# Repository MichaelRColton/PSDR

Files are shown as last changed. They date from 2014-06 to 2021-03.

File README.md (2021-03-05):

PSDR
====

PortableSDR - A Stand Alone HF Software Defined Transciever.
[Hackaday.io Link](https://hackaday.io/project/1538-portablesdr)

The PortableSDR is an all-in-one solution for ham operators, hikers, backpackers, and DIY enthusiasts who are looking for an open-source QRP (low-power) radio for communication. It is a fully stand-alone HF/Shortwave Software Defined Radio (SDR) Transceiver and includes a Vector Network Analyzer and Antenna Analyzer as well as GPS, perfect for portable operations in a variety of conditions. It is designed to be a flexible platform for development, a learning aid, and and a useful instrument for electronics enthusiasts.

## Features

- Coverage from 0 to 35MHz
- Waterfall display that lets you see radio signals
- Receives AM, USB (Upper Side Band), LSB (Lower Side Band), and Morse code (CW)
- Modulates USB and LSB signals
- Variable bandpass filter

## Hardware

- Powerful ARM processor
- Color LCD display
- Dual DDS frequency Synthesizers
- Quadrature Sampling Detector & Exciter
- Digitally controllable instrumentation amplifiers
- Morse Code key (the "Giblet" on the bottom right corner of the enclosure)
- Magnitude & Phase measurement chip (for VNA and antenna analysis functions) with Impedance Bridge
- Dual SMA connectors, smartphone style earphone/microphone connector, and USB port
- GPS
- Built in Microphone and Speaker
- Internal Lithium Polymer battery with charger and high efficiency switching regulator
- MicroSD slot
- Pads for grabbing raw I/Q signals, both in and out.

## Why did I make it?
I'm an avid backpacker and radio enthusiast. To me there is something exciting about making contact with others from remote locations where cell phones and the internet can't reach. I wanted an advanced radio that was ideally suited to tough environments. That meant I it needed to be very compact, integrated, and durable. As an engineer, I wanted an open platform that really takes advantage of the hardware and has the potential to grow and be used for other applications.

There are numerous, excellent radios out there, but none offered the combination I wanted. The best radios are closed source, larger, and expensive, while most open designs are very basic and lacking in flexibility.

=======
## Contributing
Please read our [Contributing.md](CONTRIBUTING.md) for ways to help keep this project going.

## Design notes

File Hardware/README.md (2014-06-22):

Schematics and Board layout files are for Mentorgraphics PADS.

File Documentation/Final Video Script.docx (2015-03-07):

Final Video:

Open, Wow, Connected, Reproducable/other uses, Inovation, Interface, Manufacturable

Show off prototype (industrial design), demonstrate connectedness, Sell to non-technical viewers.

5 Minutes.

PortableSDR. What it is, what does it do, why would you want one? (What can it do for you?) What makes it special.

Points I want to hit on. SDR flexibility and upgradability use as a tool and learning aid, backpacking/survival applications. Why HF?

PortableSDR.

What is it? The PortableSDR is a pocket sized, two way shortwave radio. It’s a radio that can keep you connected with the world when you are out in remote places like when you are hiking, backpacking, or fishing, or when traveling abroad.

What sets the PortableSDR apart? It’s a Software Defined Radio. That means most of its functions are handled in software, rather than with dedicated electronics. That it makes the PortableSDR very flexible and upgradable. For example, the national weather service regularly broadcasts weather photos, they could be very helpful for backpackers, but with a normal radio, if it wasn’t designed to receive these photos, it’ll never be able to. The PortableSDR on the other hand, like a computer or smartphone, can load new software that gives it new capabilities. It’s a radio that can evolve and improve with time.

Easy to use: The PortableSDR was designed to be rugged and easy to use. It has a machined aluminum case with a polycarbonate front cover. It’s totally self contained and requires only an antenna to operate. The whole thing is controlled by a single knob. Push and turn the knob to select what you want to change, and release and turn to change it. These keys are for amateur radio operators wanting to do Morse code. It has USB for charging and firmware updates and could also be used for things like keyboards, or remote operation over the internet. It includes what’s called a waterfall display. This allows you to see radio signals. With this you can quickly and easily find signals to listen to.

Why shortwave? Most of the time, when we hear about Megahertz and Gigahertz, more is better. Very high frequency radio waves travel in straight lines. So if you aren’t close to a radio station or cell tower, you can’t hear it. But the band of frequencies up to about 30MHz is special. Signals at these frequencies are able to bounce between the earth and the upper atmosphere. That’s why you can hear broadcasts from China on a shortwave radio, but not on the radio in your car. If you are in a remote area, shortwave signals may be the only thing that will reach you. These are the frequencies the PortableSDR was designed to listen and transmit on so you can connect to people around the world.

Using a shortwave radio at home can be challenging because there is so much noise from things like power lines, and computers. But out away from civilization, things are quieter, so you can hear signals more clearly and from much further away. When I am at home, I can jump on the internet and connect to anyone, anywhere, but there is something magical to me about connecting with people around the world from remote places, where cell phones and the internet can’t reach.

It’s also worth pointing out that in disasters, radios like these are sometimes the only way to communicate.

Emergency Location: The PortableSDR includes a GPS receiver, this combined with the shortwave transmitter means that in an emergency, the PortableSDR may be able to transmit your location to others, even when there is no internet or cellular coverage.

I didn’t design it as an emergency device, if that’s what you need, there are better tools, I made it for fun, for shortwave listeners and amateur radio enthusiasts to take their hobby to remote places, where cell phones and wifi still can’t reach.

Open: The PortableSDR is an open source project. Everything about its design is freely available. Anyone that is interested in making the PortableSDR better can contribute. Its circuitry was designed to be easy to understand and modify so it will be helpful to people learning radio electronics. I’m working on documentation that walks through how each part of the circuit works and why. It also contains several advanced instruments, like an Antenna Analyzer and Vector Network Analyzer, and Spectrum analyzer that make it a useful tool for electronics and radio enthusiasts.

More Info: There is a lot more than I can share in a few minutes. For more detailed information, please visit the link below.

I designed the PortableSDR because I wanted a high performance radio I could take with me on backpacking trips. This is the radio I wanted. I’ve been blown away by the response I’ve received from many people online. Apparently, this is the radio a lot of you want as well. Thank you so much for all your support and encouragement. And thank you for watching.

Licence: No licences is needed to use the PortableSDR for listening in on broadcasts and other signals, but to take full advantage of its capabilities, you’ll need to get an Amatrue Radio licence. They aren’t particularly hard to get, you’ll learn a lot, and may discover a new hobby.

Getting a PSDR: I plan on offering kits for people that are excited to build their own. I’m working on detailed assembly instructions that will help. I also hope to offer assembled units.

I am looking into producing both the case and circuit boards in different colors.

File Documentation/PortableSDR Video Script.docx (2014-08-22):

PortableSDR

The PortableSDR is a self constrained software defined transceiver. With spectrum analysis, and vector network analysis functions. It’s designed to be ergonomic, and very intuitive to use.

I want the PortableSDR to be a great radio, particularly for portable use, a useful, versatile tool, and a potentially life saving device.

I designed it because this is was the radio I wanted to have. I love backpacking, in particular ultralight backpacking. I have two great radios that are made for portable use, the Yaesu FT-817 and the AT Sprint (version2). The 817 is very capable and fun to use, but large, fairly heavy, consumes a lot of electricity. The Sprint is much smaller and lighter, but is extremely limited in its capabilities. Neither take advantage of the amazing flexibility of SDR techniques.

Whenever I’ve seen ham radio operators operating out in the field, they often carry a radio like one of these, an external battery, an antenna tuner, a morse code key, etc. I don’t want that. I really want the only thing other than the radio, to be the antenna.

I also realized that so many RF instruments have many of the same building blocks in common, a transceiver has a lot in common with a spectrum analyzer which has a pretty good deal in common with a vector network analyzer. I want the PortableSDR to take full advantage of the components available.

There have been interesting developments in ultra low power communication. With DSP techniques, it is possible to send and receive extremely weak signals, far too weak to hear, if you don’t mind sending very slowly. This is a perfect fit for backpacking use, where you may want or need to get a message out, but don’t have a lot of power or a great antenna. In particular for emergencies, I think the PortableSDR could send out a call for help when there may be few other options for communication. For this reason (as well as obtaining precies time information) the PSDR will include GPS.

I’ve decided to take the plunge with open source here for the first time. I figured I’d go all in, so every aspect of the design is open, all component lists, schematic, pcb files, gerbers, software, etc. It’s all open.

I’ve made great progress on the design. It’s already highly functional, and I’m delighted that a few people have already built their own. Check it out!

- PortableSDR: The PortableSDR is a Portable Software Defined Tranciever, with Spectrum analyzer, Vector network analyzer and GPS. I am designing it to be ergonomic and easy to use. It has an innovative interface, and is completely open source.
- Background: I made the PortableSDR because I wanted the capability of SDR, but I needed something rugged, self constrained, and in a size and form that I could take backpacking. I wanted something very capable, but also light and easy to use. Most portable Amateur radios are either very limited in capability and usability, or are large and expensive. Often, they require accessories and upgrades to work well and very few run open source software.
- Only about 30Mhz? The PortableSDR covers the HF or shortwave bands. From the AM broadcast band up to about 30Mhz. At these frequencies, radio waves bounce off the earth’s atmosphere, meaning you can hear signals and people from all around the world, and you can talk back. This means the PortableSDR can communicate for huge distances, thousands of miles. Some of the most interesting signals in radio happen here.
- Flexibility: Transceivers, Spectrum analyzers, and Vector Network Analyzers share a lot of common components, so I am designing the PortableSDR to take advantage of this to make it very flexible. The circuit is laid out in blocks that make it easy to learn and modify. It’s not only a great little radio, a learning aid and a useful tool.
- Recent work on very low power digital transmission means that the PortableSDR will be able to send short digital messages thousands of miles from anywhere in the world without any infrastructure. This means it could be used as a lifesaving tool when there is no other way to get a message out. That’s why the GPS is included. There is already a large number of people that monitor these messages, I hope in the future this emergency reporting can be automated.
- This is my first time completely open sourcing my work. Every part of the design is freely available to inspect, learn from, and tinker with. I’m really excited to see what others can do with what I’ve started. A few people have already built up their own PortableSDRs.
- Currently I have the first board, the PSDR1, build and functioning. The interface works with a single knob. Push and turn to select a setting, turn without pushing to change it. The waterfall display makes it easy to see what is happening on nearby frequencies. A variable bandpass filter makes it possible to focus in on what you are trying to listen to. It can currently demodulate AM and Lower Sideband transmissions. There is a lot to do but a lot is working well already.
- The next step is to build the next revision of hardware, and to get it out into the community.

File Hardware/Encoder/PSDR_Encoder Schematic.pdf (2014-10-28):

## 1 ENCA

## 3 COM

## 2 ENCB

## 4 SWA

## 5 SWB

S2

ENCODER_PEC09-2320F-S0015

1
TOUCH3 1
TOUCH4 1
TOUCH5 1
TOUCH6

1 M4

MH125_PLATED

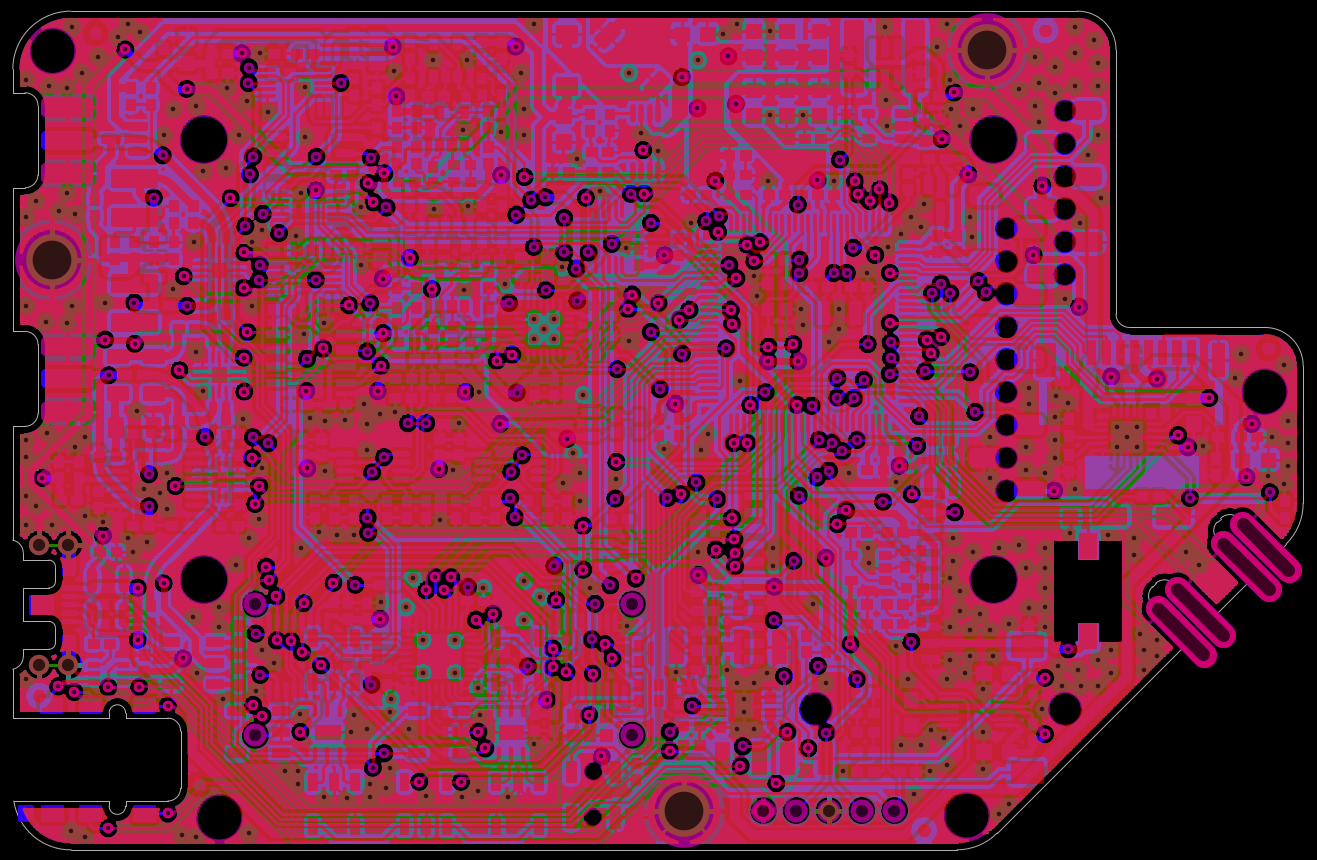
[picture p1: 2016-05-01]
Hardware/Gerbers/PSDR25 Main Board/COPPER.png

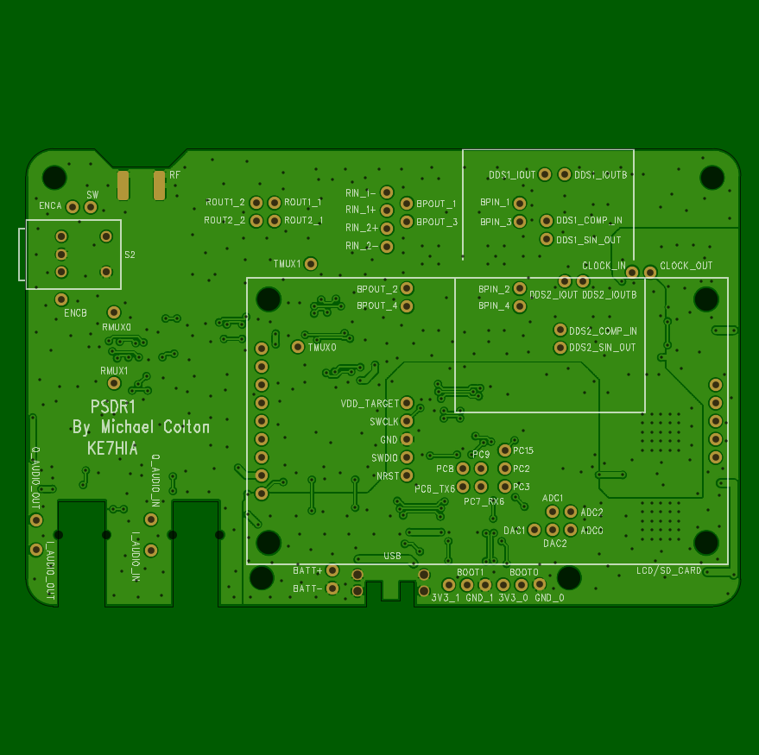
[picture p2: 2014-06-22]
Hardware/Gerbers/PSDR1/bottom_mirror.png

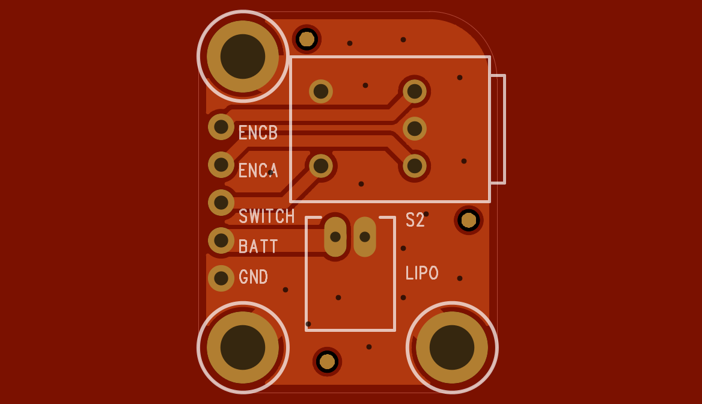
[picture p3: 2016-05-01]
Hardware/Gerbers/PSDR25_Encoder Board/TOP.png

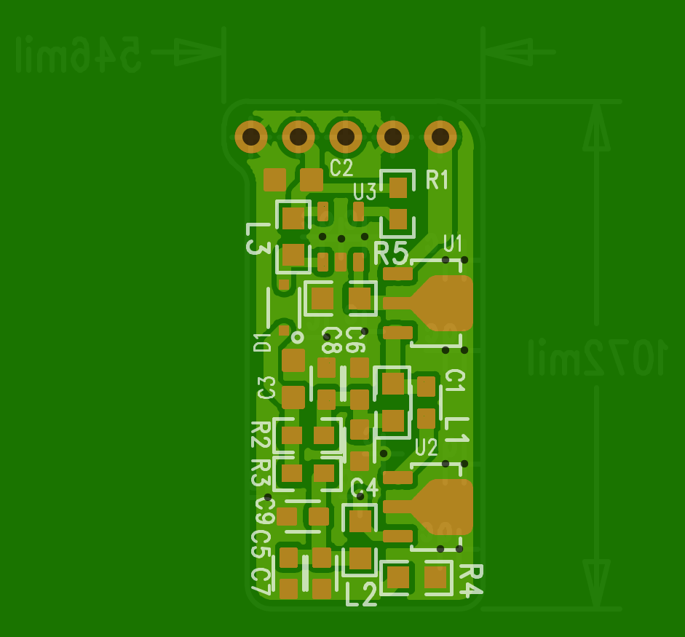
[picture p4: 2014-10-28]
Hardware/Gerbers/PSDR2 Amp Board/BOTTOM-Mirrored.png

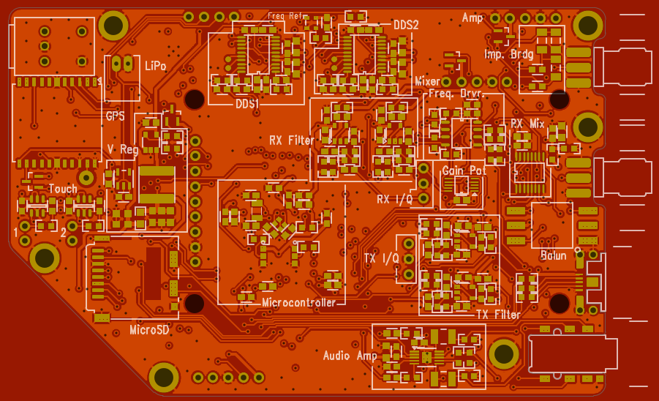
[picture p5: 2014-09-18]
Hardware/Gerbers/PSDR2 Main Board/BOTTOM - Mirrored.png

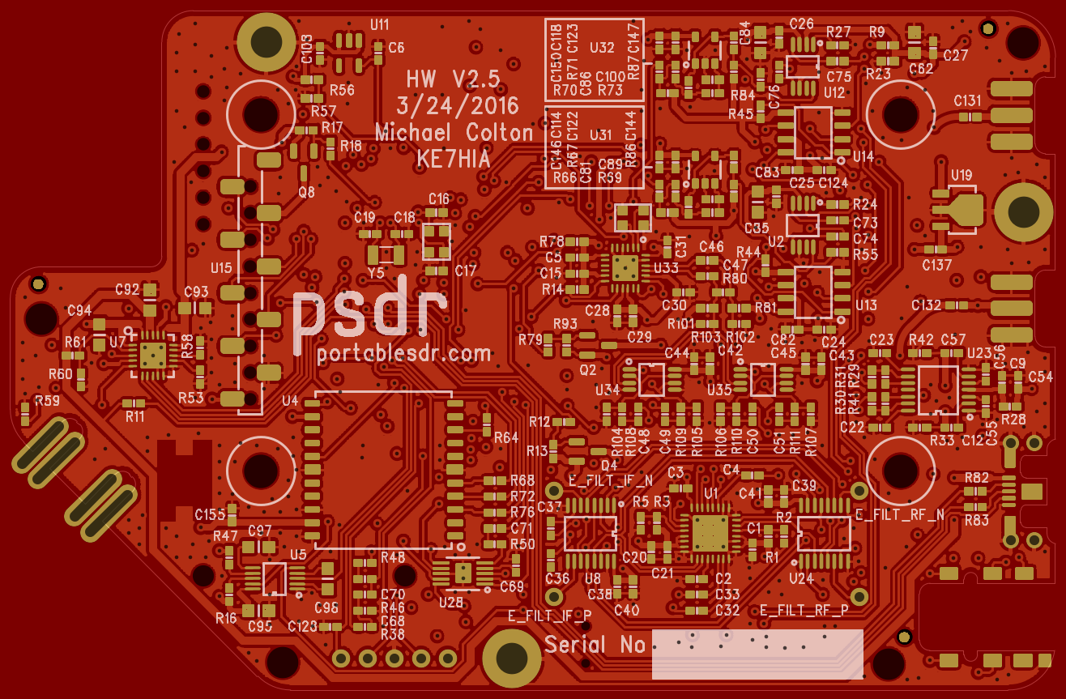
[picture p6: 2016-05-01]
Hardware/Gerbers/PSDR25 Main Board/BOTTOM.png

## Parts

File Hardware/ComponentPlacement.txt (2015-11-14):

PartType                                RefDes                        PartDecal                                Pins      Layer                          Orient.                        X                              Y                             SMD       Glued
0.1"_1PIN                               AMP-IN                        0.1"_1PIN                                1         Top                            90                             330                            2490                          False     False     
0.1"_1PIN                               AMP-OUT                       0.1"_1PIN                                1         Top                            0                              530                            2490                          False     False     
0.1"_1PIN                               AMP-POWER                     0.1"_1PIN                                1         Top                            0                              630                            2490                          False     False     
SMA_BOARD_EDGE                          ANT/VNA-IN                    SMA_BOARD_EDGE                           5         Bottom                         180                            177.165354330709               2165.35433070866              True      True      
CSM-X7R-100N-10P-25V-0603               C1                            C0603                                    2         Bottom                         90                             2100                           2170                          True      False     
CSM-X7R-100N-10P-25V-0603               C2                            C0603                                    2         Bottom                         270                            2100                           2290                          True      False     
CSM-X7R-100N-10P-25V-0603               C3                            C0603                                    2         Bottom                         0                              2230                           2410                          True      False     
CSM-X5R-10U0-10P-25V-0805               C4                            GENERIC_CAP_0805                         2         Bottom                         90                             2040                           2160                          True      False     
CSM-X5R-10U0-10P-25V-0805               C5                            GENERIC_CAP_0805                         2         Bottom                         270                            2040                           2300                          True      False     
CSM-X7R-1U0-10P-10V-0603                C6                            C0603                                    2         Bottom                         180                            3180                           1310                          True      False     
CSM-X7R-1U0-10P-10V-0603                C7                            C0603                                    2         Bottom                         270                            3280                           1430                          True      False     
CSM-X7R-100N-10P-25V-0603               C8                            C0603                                    2         Bottom                         0                              950                            1290                          True      False     
CSM-C0G-100P-5P-50V-0603                C9                            C0603                                    2         Top                            0                              1130                           2410                          True      False     
CSM-X7R-100N-10P-25V-0603               C10                           C0603                                    2         Bottom                         270                            3540                           1250                          True      False     
CSM-X7R-100N-10P-25V-0603               C11                           C0603                                    2         Bottom                         270                            3850                           1250                          True      False     
CSM-X7R-100N-10P-25V-0603               C12                           C0603                                    2         Top                            180                            1330                           2480                          True      False     
CSM-X5R-4U7-10P-10V-0603                C13                           C0603                                    2         Bottom                         180                            3000                           1800                          True      False     
CSM-X5R-10U0-10P-10V-0805               C14                           GENERIC_CAP_0805                         2         Bottom                         270                            2990                           1180                          True      False     
CSM-X7R-10N-10P-50V-0603                C15                           C0603                                    2         Bottom                         270                            1840                           2460                          True      False     
CSM-X5R-1U0-10P-25V-0603                C16                           C0603                                    2         Top                            0                              300                            780                           True      False     
CSM-X5R-1U0-10P-25V-0603                C17                           C0603                                    2         Bottom                         0                              550                            1710                          True      False     
CSM-X7R-10N-10P-50V-0603                C18                           C0603                                    2         Top                            270                            780                            1880                          True      False     
CSM-X7R-10N-10P-50V-0603                C19                           C0603                                    2         Top                            270                            780                            1750                          True      False     
CSM-C0G-18P-5P-50V-0603                 C20                           C0603                                    2         Top                            270                            2570                           1990                          True      False     
CSM-C0G-18P-5P-50V-0603                 C21                           C0603                                    2         Top                            0                              2550                           1900                          True      False     
CSM-X7R-10N-10P-50V-0603                C22                           C0603                                    2         Top                            270                            780                            1520                          True      False     
CSM-X7R-10N-10P-50V-0603                C23                           C0603                                    2         Top                            270                            780                            1390                          True      False     
CSM-X7R-100N-10P-25V-0603               C24                           C0603                                    2         Top                            0                              1020                           1610                          True      False     
CSM-X7R-100N-10P-25V-0603               C25                           C0603                                    2         Top                            0                              1020                           1550                          True      False     
CSM-X7R-100N-10P-25V-0603               C26                           C0603                                    2         Top                            90                             850                            960                           True      False     
CSM-X7R-100N-10P-25V-0603               C27                           C0603                                    2         Top                            90                             850                            720                           True      False     
CSM-X7R-100N-10P-25V-0603               C28                           C0603                                    2         Bottom                         180                            2140                           2080                          True      False     
CSM-X7R-100N-10P-25V-0603               C29                           C0603                                    2         Bottom                         90                             2240                           2050                          True      False     
CSM-X7R-10N-10P-50V-0603                C30                           C0603                                    2         Bottom                         270                            2300                           2050                          True      False     
CSM-C0G-18P-5P-50V-0603                 C31                           C0603                                    2         Bottom                         180                            2400                           2020                          True      False     
CSM-C0G-18P-5P-50V-0603                 C32                           C0603                                    2         Bottom                         0                              2530                           2020                          True      False     
CSM-X5R-1U0-10P-25V-0603                C33                           C0603                                    2         Bottom                         180                            2350                           2410                          True      False     
CSM-X7R-100N-10P-25V-0603               C34                           C0603                                    2         Bottom                         90                             1400                           2170                          True      False     
CSM-X7R-100N-10P-25V-0603               C35                           C0603                                    2         Bottom                         270                            1400                           2290                          True      False     
CSM-X7R-100N-10P-25V-0603               C36                           C0603                                    2         Bottom                         180                            1650                           2410                          True      False     
CSM-X5R-10U0-10P-25V-0805               C37                           GENERIC_CAP_0805                         2         Bottom                         90                             1340                           2160                          True      False     
CSM-X5R-10U0-10P-25V-0805               C38                           GENERIC_CAP_0805                         2         Bottom                         270                            1340                           2300                          True      False     
CSM-X7R-100N-10P-25V-0603               C39                           C0603                                    2         Bottom                         180                            1440                           2080                          True      False     
CSM-X7R-100N-10P-25V-0603               C40                           C0603                                    2         Bottom                         90                             1540                           2050                          True      False     
CSM-X7R-10N-10P-50V-0603                C41                           C0603                                    2         Bottom                         270                            1600                           2050                          True      False     
CSM-C0G-18P-5P-50V-0603                 C42                           C0603                                    2         Bottom                         180                            1700                           2020                          True      False     
CSM-C0G-18P-5P-50V-0603                 C43                           C0603                                    2         Bottom                         0                              1830                           2020                          True      False     
CSM-X5R-1U0-10P-25V-0603                C44                           C0603                                    2         Bottom                         0                              1530                           2410                          True      False     
CSM-C0G-18P-5P-50V-0603                 C45                           C0603                                    2         Top                            270                            2000                           1990                          True      False     
CSM-C0G-18P-5P-50V-0603                 C46                           C0603                                    2         Top                            180                            2020                           1900                          True      False     
CSM-C0G-18P-5P-50V-0603                 C47                           C0603                                    2         Top                            90                             2000                           1810                          True      False     
CSM-C0G-18P-5P-50V-0603                 C48                           C0603                                    2         Top                            180                            2100                           1660                          True      False     
CSM-C0G-18P-5P-50V-0603                 C49                           C0603                                    2         Top                            270                            2060                           1990                          True      False     
CSM-C0G-18P-5P-50V-0603                 C50                           C0603                                    2         Top                            270                            2060                           1810                          True      False     
CSM-C0G-18P-5P-50V-0603                 C51                           C0603                                    2         Top                            0                              2100                           1720                          True      False     
CSM-C0G-18P-5P-50V-0603                 C52                           C0603                                    2         Top                            90                             2570                           1810                          True      False     
CSM-C0G-18P-5P-50V-0603                 C53                           C0603                                    2         Top                            0                              2470                           1660                          True      False     
CSM-C0G-18P-5P-50V-0603                 C54                           C0603                                    2         Top                            270                            2510                           1990                          True      False     
CSM-C0G-18P-5P-50V-0603                 C55                           C0603                                    2         Top                            270                            2510                           1810                          True      False     
CSM-C0G-18P-5P-50V-0603                 C56                           C0603                                    2         Top                            180                            2470                           1720                          True      False     
CSM-C0G-18P-5P-50V-0603                 C57                           C0603                                    2         Top                            270                            1850                           1990                          True      False     
CSM-X7R-10N-10P-50V-0603                C58                           C0603                                    2         Bottom                         180                            880                            1860                          True      False     
CSM-X7R-100N-10P-25V-0603               C59                           C0603                                    2         Bottom                         180                            880                            1920                          True      False     
CSM-X7R-100N-10P-25V-0603               C60                           C0603                                    2         Bottom                         0                              550                            1650                          True      False     
CSM-X7R-100N-10P-25V-0603               C61                           C0603                                    2         Top                            0                              300                            840                           True      False     
CSM-X5R-47U-20P-6V3-0805                C62                           C0805                                    2         Bottom                         90                             290                            1740                          True      False     
CSM-X7R-100N-10P-25V-0603               C63                           C0603                                    2         Bottom                         90                             350                            1730                          True      False     
CSM-X7R-1N-10P-50V-0603                 C64                           C0603                                    2         Top                            0                              990                            2380                          True      False     
CSM-X7R-1N-10P-50V-0603                 C65                           C0603                                    2         Top                            0                              990                            2200                          True      False     
CSM-X7R-1N-10P-50V-0603                 C66                           C0603                                    2         Top                            0                              990                            2260                          True      False     
CSM-X7R-1N-10P-50V-0603                 C67                           C0603                                    2         Top                            0                              990                            2320                          True      False     
CSM-C0G-100P-5P-50V-0603                C68                           C0603                                    2         Top                            180                            1290                           2160                          True      False     
CSM-C0G-18P-5P-50V-0603                 C69                           C0603                                    2         Top                            0                              1830                           1900                          True      False     
CSM-C0G-18P-5P-50V-0603                 C70                           C0603                                    2         Top                            90                             1850                           1810                          True      False     
CSM-C0G-18P-5P-50V-0603                 C71                           C0603                                    2         Top                            0                              1750                           1660                          True      False     
CSM-C0G-18P-5P-50V-0603                 C72                           C0603                                    2         Top                            270                            1790                           1990                          True      False     
CSM-C0G-18P-5P-50V-0603                 C73                           C0603                                    2         Top                            270                            1790                           1810                          True      False     
CSM-C0G-18P-5P-50V-0603                 C74                           C0603                                    2         Top                            180                            1750                           1720                          True      False     
CSM-C0G-18P-5P-50V-0603                 C75                           C0603                                    2         Top                            270                            1280                           1990                          True      False     
CSM-C0G-18P-5P-50V-0603                 C76                           C0603                                    2         Top                            180                            1300                           1900                          True      False     
CSM-C0G-18P-5P-50V-0603                 C77                           C0603                                    2         Top                            90                             1280                           1810                          True      False     
CSM-C0G-18P-5P-50V-0603                 C78                           C0603                                    2         Top                            180                            1380                           1660                          True      False     
CSM-C0G-18P-5P-50V-0603                 C79                           C0603                                    2         Top                            270                            1340                           1990                          True      False     
CSM-C0G-18P-5P-50V-0603                 C80                           C0603                                    2         Top                            270                            1340                           1810                          True      False     
CSM-C0G-18P-5P-50V-0603                 C81                           C0603                                    2         Top                            0                              1380                           1720                          True      False     
CSM-X7R-100N-10P-25V-0603               C82                           C0603                                    2         Top                            0                              1020                           1970                          True      False     
CSM-X7R-100N-10P-25V-0603               C83                           C0603                                    2         Top                            0                              1020                           1910                          True      False     
CSM-X5R-10U0-20P-6V3-0603               C84                           C0603                                    2         Top                            90                             790                            720                           True      False     
CSM-X5R-10U0-20P-6V3-0603               C85                           C0603                                    2         Top                            90                             790                            960                           True      False     
CSM-X5R-10U0-20P-6V3-0603               C86                           C0603                                    2         Top                            0                              640                            880                           True      False     
CSM-X5R-10U0-20P-6V3-0603               C87                           C0603                                    2         Top                            0                              640                            940                           True      False     
CSM-X5R-10U0-20P-6V3-0603               C88                           C0603                                    2         Top                            0                              640                            820                           True      False     
CSM-X5R-10U0-20P-6V3-0603               C89                           C0603                                    2         Top                            0                              640                            1000                          True      False     
CSM-X5R-10U0-10P-10V-0805               C90                           GENERIC_CAP_0805                         2         Bottom                         180                            3190                           1200                          True      False     
CSM-X5R-10U0-10P-10V-0805               C91                           GENERIC_CAP_0805                         2         Bottom                         180                            3190                           1130                          True      False     
CSM-X5R-10U0-10P-25V-0805               C92                           GENERIC_CAP_0805                         2         Top                            180                            2890                           2450                          True      False     
CSM-X5R-4U7-10P-16V-0805                C93                           C0805                                    2         Top                            90                             3010                           2330                          True      False     
CSM-X5R-4U7-10P-16V-0805                C94                           C0805                                    2         Top                            180                            2640                           2350                          True      False     
CSM-X5R-10U0-10P-25V-0805               C95                           GENERIC_CAP_0805                         2         Top                            90                             3180                           450                           True      False     
CSM-X5R-10U0-10P-25V-0805               C96                           GENERIC_CAP_0805                         2         Top                            0                              3150                           330                           True      False     
CSM-X5R-10U0-10P-25V-0805               C97                           GENERIC_CAP_0805                         2         Top                            180                            2960                           400                           True      False     
CSM-X5R-10U0-10P-25V-0805               C98                           GENERIC_CAP_0805                         2         Top                            180                            3090                           640                           True      False     
CSM-X7R-100N-10P-25V-0603               C99                           C0603                                    2         Top                            270                            2990                           600                           True      False     
CSM-X7R-1N-10P-50V-0603                 C100                          C0603                                    2         Top                            180                            1970                           250                           True      False     
CSM-X7R-1N-10P-50V-0603                 C101                          C0603                                    2         Top                            90                             1860                           280                           True      False     
CSM-X7R-10N-10P-50V-0603                C102                          C0603                                    2         Top                            270                            1650                           230                           True      False     
CSM-X7R-1U0-10P-10V-0603                C103                          C0603                                    2         Top                            270                            1590                           230                           True      False     
CSM-X7R-100N-10P-25V-0603               C104                          C0603                                    2         Top                            180                            1750                           340                           True      False     
CSM-X5R-4U7-10P-6V3-0603                C105                          C0603                                    2         Top                            270                            2370                           280                           True      False     
CSM-X7R-100N-10P-25V-0603               C106                          C0603                                    2         Top                            180                            3440                           750                           True      False     
CSM-X5R-22U-20P-10V-1210                C107                          C1210                                    2         Bottom                         0                              1070                           390                           True      False     
CSM-X5R-1U0-10P-25V-0603                C108                          C0603                                    2         Bottom                         90                             1380                           290                           True      False
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

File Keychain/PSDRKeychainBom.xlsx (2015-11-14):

RefDes | Part Type | Description | Count | Value | Digikey Prt#
U3 | 3V3_LDO_MCP1802 |  | 1 |  | MCP1802T-3302I/OTCT-ND
Y1 | ABMM2-8.000MHZ-E2-T |  | 1 |  | 535-9628-1-ND
BUT, RESET | BUTTON_B3U-1000P-B |  | 2 |  | SW1143CT-ND
C8,10 | CSM-C0G-100P-5P-50V-0603 |  | 2 | 47p | 1276-1037-1-ND
C20,21 | CSM-C0G-18P-5P-50V-0603 |  | 2 | 18p | 1276-1089-1-ND
C9 | CSM-X5R-10U0-10P-10V-0805 |  | 1 | 10u0 | 1276-2407-1-ND
C1,2,4,5 | CSM-X5R-1U0-10P-25V-0603 |  | 4 | 1u0 | 1276-1946-1-ND
D3 | LED-WHITE-0603 |  | 1 | APTD1608QWF | 475-2831-1-ND
USB | MICRO-USB_10118194-0001LF |  | 1 |  | 609-4618-1-ND
Q3,4 | NPN_SOT23_CORRECTED |  | 2 |  | 568-4510-1-ND
R2,3,8 | RSM-10K0-1PCT-100MW-0603 |  | 3 | 10K0 | 311-10.0KHRCT-ND
R1,4,5 | RSM-1K00-1PCT-100MW-0603 |  | 3 | 1K00 | 311-1.00KHRCT-ND
R9 | RSM-1K50-1PCT-100MW-0603 |  | 1 | 1K50 | 311-1.50KHRCT-ND
R10,11 | RSM-22R1-1PCT-100MW-0603 |  | 2 | 22R1 | 311-22.1HRCT-ND
R32 | RSM-255R-1PCT-100MW-0603 |  | 1 | 255R | 311-255HRCT-ND
R7 | RSM-36K5-1PCT-100MW-0603 |  | 1 | 36K5 | 311-36.5KHRCT-ND
R6 | RSM-47K5-1PCT-100MW-0603 |  | 1 | 47K5 | 311-47.5KHRCT-ND
U1 | STM32F103CB |  | 1 |  | 497-6288-ND

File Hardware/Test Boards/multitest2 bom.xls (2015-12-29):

Bill Of Materials for Si5338 Test Board_00AF.sch on 11/14/2015
Number | Reference Designator | Qty | Part | Value | DigiPartNo
1 | U9,15 | 2 | 74CBTLV3253 |  | 568-5265-1-ND
2 | C1-9,11,18-23,26-39,42,63,136-139 | 36 | CAP_0603 | 100n | 490-1532-1-ND
3 | C12,13,24,25 | 4 | CAP_0603 | 100p | 1276-1008-1-ND
4 | C40,41 | 2 | CAP_0603 | 1u0 | 1276-1946-1-ND
5 | Y1 | 1 | CRYSTAL3225 |  | SER4069CT-ND
6 | C16,17 | 2 | CSM-X5R-2U2-10P-6V3-0603 | 2u2 | 1276-1134-1-ND
7 | C62 | 1 | CSM-X5R-47U-20P-6V3-0805 | 47u | 1276-2420-1-ND
8 | C14,15 | 2 | CSM-X7R-1N-10P-50V-0603 | 1n | 490-1494-1-ND
9 | U6,8 | 2 | DPDT_ANALOG_MAX4525 |  | MAX4525CUB+-ND
10 | L1,2 | 2 | ISM-0805-10U | MUCH HIGHER? Than 2u2 | 587-2472-1-ND
11 | U4,5 | 2 | MMIC-AMP_HMC482ST |  | 1127-1421-1-ND
12 | Q1,8 | 2 | MOSFET_P_SOT23_IRLML6401 |  | IRLML6401PBFCT-ND
13 | R4,7-9,25,44 | 6 | RES_0603 | 100k | P100KGCT-ND
14 | R1-3,10-22,26-43 | 34 | RES_0603 | 1k0 | MCT0603-1.00K-CFCT-ND
15 | U26 | 1 | RF_DPDT_MASWSS0129TR |  | 1465-1374-1-ND
16 | U10,11 | 2 | RF_MIXER_PE4140 |  | 1046-1021-1-ND
17 | R23,24 | 2 | RES_0603 | 10k | MCT0603-10.0K-CFCT-ND
18 | R5,6 | 2 | RES_0603 | 10r | RHM10.0ADCT-ND
19 | U1 | 1 | SI5338 |  | SI5338A-B-GM
20 | ANT/VNA-IN | 1 | SMA_BOARD_EDGE |  | J629-ND
21 | U2,3 | 2 | SY10EP52V
22 | L9 | 1 | T4-1-KK81
23 | U7 | 1 | VARIABLE_FILTER_HMC1023 |  | 1127-1662-ND
 | Maybe a sample pack of 0603 Resistors
 | Maybe some variable resistors!

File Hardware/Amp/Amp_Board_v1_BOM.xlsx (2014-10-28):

RefDes | Count | Part Type | Distributor Part No. | Distributor | Description | Manufacturer | Value | Tolerance
R1 | 1 | RSM-100K-1PCT-100MW-0603 | P100KGCT-ND |  |  |  | 100K | 0.01
C1 | 1 | CSM-X7R-100N-10P-25V-0603 | 490-1532-1-ND |  |  |  | 100n | 10P
C4, 5 | 2 | CSM-C0G-100P-5P-50V-0603 | 1276-1008-1-ND |  |  |  | 100p | 5P
R2, 3 | 2 | RSM-10R0-1PCT-100MW-0603 | RHM10.0ADCT-ND |  | RES 10 OHM 1/4W 1% 0603 SMD |  | 10R0 | 0.01
C2, 3 | 2 | CSM-X5R-10U0-10P-25V-0805 | 1276-1113-1-ND |  |  |  | 10u0 | 10P
L3 | 1 | ISM-0805-10U | 587-3020-1-ND |  | INDUCTOR 15UH 20% 0805 SMD |  | 15u
C6, 7 | 2 | CSM-X7R-1N-10P-50V-0603 | 490-1494-1-ND |  |  |  | 1n | 10P
R4, 5 | 2 | RSM-10R0-1PCT-125MW-0805 | 541-1.74HHCT-ND |  | RES 1.74 OHM 1/10W 1% 0603 SMD |  | 1R74 | 0.01
C8, 9 | 2 | CSM-X5R-2U2-10P-6V3-0603 | 1276-1134-1-ND |  |  |  | 2u2 | 10P
L1, 2 | 2 | ISM-0805-10U | 587-2043-1-ND |  | INDUCTOR 2.2UH 260MA 20% SMD |  | 2u2
D1 | 1 | DIODE-SOD-323 | SD101CWSTPMSCT-ND |  | DIODE SCHOTTKY 40V SOD323
U1, 2 | 2 | MMIC-AMP_HMC482ST | 1127-1421-1-ND |  | IC MMIC AMP HBT 5GHZ SOT-89
U3 | 1 | LED-BOOST-REG_LM3410 | LM3410XMF/NOPBCT-ND |  | IC DRVR WT/OLED BCKLT SOT23-5

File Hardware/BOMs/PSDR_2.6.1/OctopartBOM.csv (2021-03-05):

Qty | Line Item | Manufacturer | MPN | Octopart URL | Schematic Reference | Internal Part Number | Description | Total Qty (@ Batch Size: 1) | SKU | SKU | SKU | SKU | Packaging | Packaging | Packaging | Packaging | Unit Price (@ Batch Size: 1) | Unit Price (@ Batch Size: 1) | Unit Price (@ Batch Size: 1) | Unit Price (@ Batch Size: 1) | In Stock | In Stock | In Stock | In Stock | MOQ | MOQ | MOQ | MOQ | URL | URL | URL | URL | Distributor [Lowest Price (Overall)] | SKU [Lowest Price (Overall)] | Packaging [Lowest Price (Overall)] | Unit Price (@ Batch Size: 1) [Lowest Price (Overall)] | Line Total [Lowest Price (Overall)] | Batch Total [Lowest Price (Overall)] | In Stock [Lowest Price (Overall)] | MOQ [Lowest Price (Overall)] | URL [Lowest Price (Overall)] | Notes
 |  |  |  |  |  |  |  |  | Digi-Key | Future Electronics | Mouser | RS Components | Digi-Key | Future Electronics | Mouser | RS Components | Digi-Key | Future Electronics | Mouser | RS Components | Digi-Key | Future Electronics | Mouser | RS Components | Digi-Key | Future Electronics | Mouser | RS Components | Digi-Key | Future Electronics | Mouser | RS Components
2 | WM50018-05-ND | Molex | 22-28-4054 | https://octopart.com/22-28-4054-molex-278278 |  |  |  | 2 | WM50018-05-ND |  | 538-22-28-4054 |  | Bulk |  | Bulk |  | 0.45 |  | 0.41 |  | 1714 |  | 288 |  | 1 |  | 1 |  | https://octopart.com/click/track?ai=8237&sig=0768743&sid=459&ppid=278278&vpid=78026448&ct=offers |  | https://octopart.com/click/track?ai=8237&sig=0e5d879&sid=2401&ppid=278278&vpid=37931119&ct=offers |  | Newark | 56H1979 |  | 0.226 | 0.452 | 0.452 | 10524 | 1 | https://octopart.com/click/track?ai=8237&sig=0e22af8&sid=2402&ppid=278278&vpid=534807129&ct=offers
2 | J629-ND | Emerson Network Power | 142-0711-821 | https://octopart.com/142-0711-821-emerson+network+power-39448276 |  |  |  | 2 | J629-ND |  |  |  | Bulk |  |  |  | 4.74 |  |  |  | 34132 |  |  |  | 1 |  |  |  | https://octopart.com/click/track?ai=8237&sig=03f6d87&sid=459&ppid=39448276&vpid=113513258&ct=offers |  |  |  | Voyager Components | 142-0711-821-JOHNSON-N/A |  | 2.43361 | 4.86722 | 4.86722 | 7 | 1 | https://octopart.com/click/track?ai=8237&sig=03d8987&sid=2424&ppid=39448276&vpid=590627797&ct=offers
2 | SW1143CT-ND | Omron | B3U-1000P-B | https://octopart.com/b3u-1000p-b-omron-1057356 |  |  |  | 2 | SW1143CT-ND |  | 653-B3U-1000P-B |  | Cut Tape |  | Tape & Reel |  | 0.92 |  | 0.92 |  | 1995 |  | 6379 |  | 1 |  | 1 |  | https://octopart.com/click/track?ai=8237&sig=0715549&sid=459&ppid=1057356&vpid=36619538&ct=offers |  | https://octopart.com/click/track?ai=8237&sig=02e6279&sid=2401&ppid=1057356&vpid=37858250&ct=offers |  | LCSC | C231330 |  | 0.3769 | 0.7538 | 0.7538 | 3097 | 1 | https://octopart.com/click/track?ai=8237&sig=0cb2428&sid=27971&ppid=1057356&vpid=499990529&ct=offers
68 | 490-3285-1-ND | Murata | GRM188R72A104KA35D | https://octopart.com/grm188r72a104ka35d-murata-196904 |  |  |  | 68 | 490-3285-1-ND | 6104052 | 81-GRM188R72A104KA35 |  | Cut Tape | Cut Tape | Tape & Reel |  | 0.1154 | 0.073 | 0.116 |  | 1934716 | 0 | 313351 |  | 1 | 1 | 1 |  | https://octopart.com/click/track?ai=8237&sig=0552a4b&sid=459&ppid=196904&vpid=1759958&ct=offers | https://octopart.com/click/track?c=1&ai=8237&sig=095ddca&sid=2454&ppid=196904&vpid=495870575&ct=offers | https://octopart.com/click/track?ai=8237&sig=017296d&sid=2401&ppid=196904&vpid=37944309&ct=offers |  | Quest | GRM188R72A104KA35D |  | 0.0699 | 4.7532000000000005 | 4.7532000000000005 | 280406 | 1 | https://octopart.com/click/track?ai=8237&sig=0c9acba&sid=2412&ppid=196904&vpid=67430058&ct=offers
4 | 1276-1008-1-ND | Samsung | CL10C101JB8NNNC | https://octopart.com/cl10c101jb8nnnc-samsung-9299377 |  |  |  | 4 | 1276-1008-1-ND | 4220968 | 187-CL10C101JB8NNNC | 7665130 | Cut Tape | Cut Tape | Tape & Reel |  | 0.1 | 1.63 | 0.1 |  | 239121 | 341798 | 214141 | 176000 | 1 | 1 | 1 | 4000 | https://octopart.com/click/track?ai=8237&sig=0af5203&sid=459&ppid=9299377&vpid=72524765&ct=offers | https://octopart.com/click/track?ai=8237&sig=029d983&sid=2454&ppid=9299377&vpid=495872537&ct=offers | https://octopart.com/click/track?ai=8237&sig=0cd9e3d&sid=2401&ppid=9299377&vpid=659501335&ct=offers | https://octopart.com/click/track?ai=8237&sig=09b4d69&sid=10022&ppid=9299377&vpid=575772157&ct=offers | Newark | 82AC9367 | Cut Tape | 0.005 | 0.02 | 0.02 | 40090 | 1 | https://octopart.com/click/track?ai=8237&sig=0b7e270&sid=2402&ppid=9299377&vpid=511545639&ct=offers
5 | 1276-1009-1-ND | Samsung | CL10B103KB8NNNC | https://octopart.com/cl10b103kb8nnnc-samsung-9299374 |  |  |  | 5 | 1276-1009-1-ND | 7103639 | 187-CL10B103KB8NNNC | 7665373 | Cut Tape | Cut Tape | Tape & Reel |  | 0.1 | 0.098 | 0.1 |  | 1613097 | 6572866 | 438083 | 6204000 | 1 | 1 | 1 | 4000 | https://octopart.com/click/track?ai=8237&sig=08f0957&sid=459&ppid=9299374&vpid=72523832&ct=offers | https://octopart.com/click/track?ai=8237&sig=08b147c&sid=2454&ppid=9299374&vpid=495872440&ct=offers | https://octopart.com/click/track?ai=8237&sig=0edcec1&sid=2401&ppid=9299374&vpid=659501108&ct=offers | https://octopart.com/click/track?ai=8237&sig=09d8818&sid=10022&ppid=9299374&vpid=575772086&ct=offers | Newark | 82AC9315 | Cut Tape | 0.004 | 0.02 | 0.02 | 41660 | 1 | https://octopart.com/click/track?ai=8237&sig=00bc199&sid=2402&ppid=9299374&vpid=511545493&ct=offers
15 | 1276-1113-1-ND | Samsung | CL21B106KQQNNNE | https://octopart.com/cl21b106kqqnnne-samsung-18183217 |  |  |  | 15 | 1276-1113-1-ND | 9526229 | 187-CL21B106KQQNNNE |  | Cut Tape | Cut Tape | Tape & Reel |  | 0.139 | 0.196 | 0.082 |  | 963 | 1988 | 73036 |  | 1 | 1 | 1 |  | https://octopart.com/click/track?ai=8237&sig=0995b10&sid=459&ppid=18183217&vpid=72526172&ct=offers | https://octopart.com/click/track?ai=8237&sig=0265d4b&sid=2454&ppid=18183217&vpid=495872705&ct=offers | https://octopart.com/click/track?ai=8237&sig=01ff177&sid=2401&ppid=18183217&vpid=659501630&ct=offers |  | Mouser | 187-CL21B106KQQNNNE | Tape & Reel | 0.082 | 1.23 | 1.23 | 73036 | 1 | https://octopart.com/click/track?ai=8237&sig=01ff177&sid=2401&ppid=18183217&vpid=659501630&ct=offers
15 | 490-1472-1-ND | Murata | GRM188R72A102KA01D | https://octopart.com/grm188r72a102ka01d-murata-196190 |  |  |  | 15 | 490-1472-1-ND | 7114712 |  |  | Cut Tape | Cut Tape |  |  | 0.077 | 0.108 |  |  | 348772 | 886796 |  |  | 1 | 1 |  |  | https://octopart.com/click/track?ai=8237&sig=057f021&sid=459&ppid=196190&vpid=1764216&ct=offers | https://octopart.com/click/track?ai=8237&sig=00da36d&sid=2454&ppid=196190&vpid=657019381&ct=offers |  |  | Freelance Electronics | GRM188R72A102KA01D |  | 0.00647 | 0.09705 | 0.09705 | 7900 | 1 | https://octopart.com/click/track?ai=8237&sig=048efb7&sid=13062&ppid=196190&vpid=248337884&ct=offers
7 | 1276-1946-1-ND | Samsung | CL10B105KP8NNNC | https://octopart.com/cl10b105kp8nnnc-samsung-19831604 |  |  |  | 7 | 1276-1946-1-ND | 8103641 | 187-CL10B105KP8NNNC |  | Cut Tape | Cut Tape | Tape & Reel |  | 0.1 | 0.0141 | 0.1 |  | 3872897 | 416878 | 227214 |  | 1 | 1 | 1 |  | https://octopart.com/click/track?ai=8237&sig=084b68a&sid=459&ppid=19831604&vpid=72523947&ct=offers | https://octopart.com/click/track?ai=8237&sig=071bacc&sid=2454&ppid=19831604&vpid=495872463&ct=offers | https://octopart.com/click/track?ai=8237&sig=04a8eac&sid=2401&ppid=19831604&vpid=659501159&ct=offers |  | Newark | 82AC9335 | Cut Tape | 0.007 | 0.049 | 0.049 | 8083 | 1 | https://octopart.com/click/track?ai=8237&sig=0dd3b91&sid=2402&ppid=19831604&vpid=511545544&ct=offers
11 | 1276-3375-1-ND | Samsung | CL32A227MQVNNNE | https://octopart.com/cl32a227mqvnnne-samsung-21642163 |  |  |  | 11 | 1276-3375-1-ND | 7061029 | 187-CL32A227MQVNNNE | 7661160 | Cut Tape | Cut Tape | Tape & Reel |  | 1.525 | 2.03 | 1.53 | 1.627 | 4538 | 198141 | 44353 | 18 | 1 | 1 | 1 | 2 | https://octopart.com/click/track?ai=8237&sig=056834c&sid=459&ppid=21642163&vpid=72529399&ct=offers | https://octopart.com/click/track?ai=8237&sig=072bdb2&sid=2454&ppid=21642163&vpid=421050959&ct=offers | https://octopart.com/click/track?ai=8237&sig=02c25d7&sid=2401&ppid=21642163&vpid=659502060&ct=offers | https://octopart.com/click/track?ai=8237&sig=02c5766&sid=10022&ppid=21642163&vpid=575772541&ct=offers | LCSC | C400951 |  | 0.7538 | 8.2918 | 8.2918 | 12811 | 1 | https://octopart.com/click/track?ai=8237&sig=068f5a2&sid=27971&ppid=21642163&vpid=594417399&ct=offers
4 | 1276-1193-1-ND | Samsung | CL10A226MQ8NRNC | https://octopart.com/cl10a226mq8nrnc-samsung-19018972 |  |  |  | 4 | 1276-1193-1-ND | 1951326 | 187-CL10A226MQ8NRNC | 7661006P | Cut Tape | Cut Tape | Tape & Reel |  | 0.24 | 0.235 | 0.32 |  | 112669 | 309837 | 305 | 25 | 1 | 1 | 1 | 25 | https://octopart.com/click/track?ai=8237&sig=065f626&sid=459&ppid=19018972&vpid=72523680&ct=offers | https://octopart.com/click/track?ai=8237&sig=067f4e7&sid=2454&ppid=19018972&vpid=421049762&ct=offers | https://octopart.com/click/track?ai=8237&sig=0491f0a&sid=2401&ppid=19018972&vpid=659501058&ct=offers | https://octopart.com/click/track?ai=8237&sig=0ada1f7&sid=10022&ppid=19018972&vpid=660735010&ct=offers | Quest | CL10A226MQ8NRNC |  | 0.2 | 0.8 | 0.8 | 104 | 1 | https://octopart.com/click/track?ai=8237&sig=077a634&sid=2412&ppid=19018972&vpid=542505621&ct=offers
5 | 1276-1134-1-ND | Samsung | CL10B225KP8NNNC | https://octopart.com/cl10b225kp8nnnc-samsung-19831669 |  |  |  | 5 | 1276-1134-1-ND | 4103667 | 187-CL10B225KP8NNNC |  | Cut Tape | Cut Tape | Tape & Reel |  | 0.11 | 0.0325 | 0.12 |  | 92201 | 354585 | 72645 |  | 1 | 1 | 1 |  | https://octopart.com/click/track?ai=8237&sig=0f63fb3&sid=459&ppid=19831669&vpid=72524202&ct=offers | https://octopart.com/click/track?ai=8237&sig=06c1043&sid=2454&ppid=19831669&vpid=495872483&ct=offers | https://octopart.com/click/track?ai=8237&sig=0c75fe2&sid=2401&ppid=19831669&vpid=659501210&ct=offers |  | Future Electronics | 4103667 | Cut Tape | 0.0325 | 0.1625 | 0.1625 | 354585 | 1 | https://octopart.com/click/track?ai=8237&sig=06c1043&sid=2454&ppid=19831669&vpid=495872483&ct=offers
1 | 1276-2030-1-ND | Samsung | CL10B332JB8NNNC | https://octopart.com/cl10b332jb8nnnc-samsung-15492529 |  |  |  | 1 | 1276-2030-1-ND |  |  |  | Cut Tape |  |  |  | 0.1 |  |  |  | 102646 |  |  |  | 1 |  |  |  | https://octopart.com/click/track?c=1&ai=8237&sig=0ae29b7&sid=459&ppid=15492529&vpid=72524250&ct=offers |  |  |  | Digi-Key | 1276-2030-1-ND | Cut Tape | 0.1 | 0.1 | 0.1 | 102646 | 1 | https://octopart.com/click/track?c=1&ai=8237&sig=0ae29b7&sid=459&ppid=15492529&vpid=72524250&ct=offers
1 | 311-4001-1-ND | Yageo | CC0603JRX7R8BB333 | https://octopart.com/cc0603jrx7r8bb333-yageo-25629527 |  |  |  | 1 | 311-4001-1-ND | 7099787 | 603-CC603JRX7R8BB333 |  | Cut Tape | Tape & Reel | Tape & Reel |  | 0.11 |  | 0.13 |  | 18852 | 0 | 8695 |  | 1 | 4000 | 1 |  | https://octopart.com/click/track?ai=8237&sig=0ca1308&sid=459&ppid=25629527&vpid=457174973&ct=offers | https://octopart.com/click/track?c=1&ai=8237&sig=076279b&sid=2454&ppid=25629527&vpid=657181783&ct=offers | https://octopart.com/click/track?ai=8237&sig=0bc5dc1&sid=2401&ppid=25629527&vpid=268303231&ct=offers |  | Digi-Key | 311-4001-1-ND | Cut Tape | 0.11 | 0.11 | 0.11 | 18852 | 1 | https://octopart.com/click/track?ai=8237&sig=0ca1308&sid=459&ppid=25629527&vpid=457174973&ct=offers
4 | 1276-1062-1-ND | Samsung | CL10B474KO8NNNC | https://octopart.com/cl10b474ko8nnnc-samsung-9301678 |  |  |  | 4 | 1276-1062-1-ND | 2488724 | 187-CL10B474KO8NNNC | 7664765 | Cut Tape | Cut Tape | Tape & Reel |  | 0.1 | 0.098 | 0.1 |  | 216128 | 236311 | 151105 | 116000 | 1 | 1 | 1 | 4000 | https://octopart.com/click/track?ai=8237&sig=01034d2&sid=459&ppid=9301678&vpid=72524451&ct=offers | https://octopart.com/click/track?ai=8237&sig=03b38b2&sid=2454&ppid=9301678&vpid=495872506&ct=offers | https://octopart.com/click/track?ai=8237&sig=0ecb067&sid=2401&ppid=9301678&vpid=658751354&ct=offers | https://octopart.com/click/track?ai=8237&sig=04430c8&sid=10022&ppid=9301678&vpid=575772136&ct=offers | Newark | 82AC9359 | Cut Tape | 0.006 | 0.024 | 0.024 | 12275 | 1 | https://octopart.com/click/track?ai=8237&sig=004f9a0&sid=2402&ppid=9301678&vpid=511545615&ct=offers
1 | 1276-2420-1-ND | Samsung | CL21A476MQCLRNC | https://octopart.com/cl21a476mqclrnc-samsung-24871259 |  |  |  | 1 | 1276-2420-1-ND | 7103714 | 187-CL21A476MQCLRNC |  | Cut Tape | Cut Tape | Tape & Reel |  | 0.83 | 0.14 | 0.53 |  | 409971 | 0 | 71990 |  | 1 | 1 | 1 |  | https://octopart.com/click/track?ai=8237&sig=0b44936&sid=459&ppid=24871259&vpid=72525933&ct=offers | https://octopart.com/click/track?c=1&ai=8237&sig=0c213f7&sid=2454&ppid=24871259&vpid=495872659&ct=offers | https://octopart.com/click/track?ai=8237&sig=0621a86&sid=2401&ppid=24871259&vpid=659501512&ct=offers |  | Future Electronics | 7103714 | Cut Tape | 0.14 | 0.14 | 0.14 | 0 | 1 | https://octopart.com/click/track?c=1&ai=8237&sig=0c213f7&sid=2454&ppid=24871259&vpid=495872659&ct=offers
4 | 490-7203-1-ND | Murata | GRM188R61E475KE11D | https://octopart.com/grm188r61e475ke11d-murata-26982327 |  |  |  | 4 | 490-7203-1-ND | 6104085 | 81-GRM188R61E475KE1D | 8151386 | Cut Tape | Cut Tape | Tape & Reel |  | 0.36 | 0.365 | 0.41 |  | 300910 | 1056 | 213126 | 1350 | 1 | 1 | 1 | 25 | https://octopart.com/click/track?ai=8237&sig=0a6541a&sid=459&ppid=26982327&vpid=68513470&ct=offers | https://octopart.com/click/track?ai=8237&sig=0bae64b&sid=2454&ppid=26982327&vpid=495870555&ct=offers | https://octopart.com/click/track?ai=8237&sig=0cc25c5&sid=2401&ppid=26982327&vpid=168137474&ct=offers | https://octopart.com/click/track?ai=8237&sig=003d1de&sid=10022&ppid=26982327&vpid=575622394&ct=offers | Express Electronics | GRM188R61E475KE11D |  | 0.03 | 0.12 | 0.12 | 11307 | 1 | https://octopart.com/click/track?ai=8237&sig=0b8568b&sid=2450&ppid=26982327&vpid=674983100&ct=offers
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

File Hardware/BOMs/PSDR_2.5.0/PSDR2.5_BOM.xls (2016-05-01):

Bill Of Materials for PSDR.sch on 3/31/2016 |  | Quantity | Total Quantity
 |  | Number of units to build | 2
Item Number | Reference Designator |  |  | Type | Value | Vendor | Vendor Part Number | Manufacturer | Manufacturer Part Number | Replacement Allowed?
1 | ANT/VNA-IN,VNA-OUT | 2 | 4 | SMA_BOARD_EDGE |  |  | J629-ND
2 | BOOT, RST | 2 | 4 | BUTTON_B3U-1000P-B |  | Digikey | SW1143CT-ND
3 | C1-5,8,15,20,21,25-39,42,43,46–54,59,63,82,83,99,104,106,112,116,117,120,125,-144,146,147,150 | 69 | 138 | CAP_0603 | 100n |  | 490-1532-1-ND
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

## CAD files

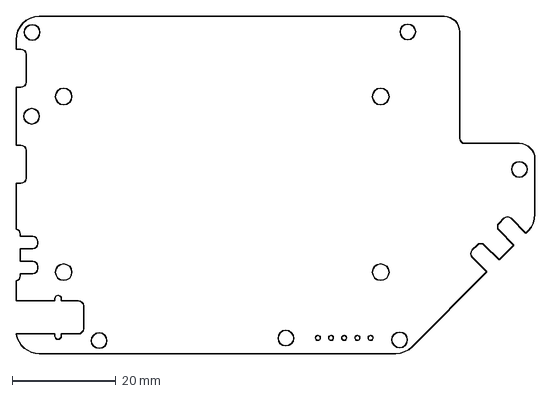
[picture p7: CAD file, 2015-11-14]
Hardware/BOMs/PSDR_2.0.0/PSDR2_MainBoard.DXF
100.0 x 65.0 mm

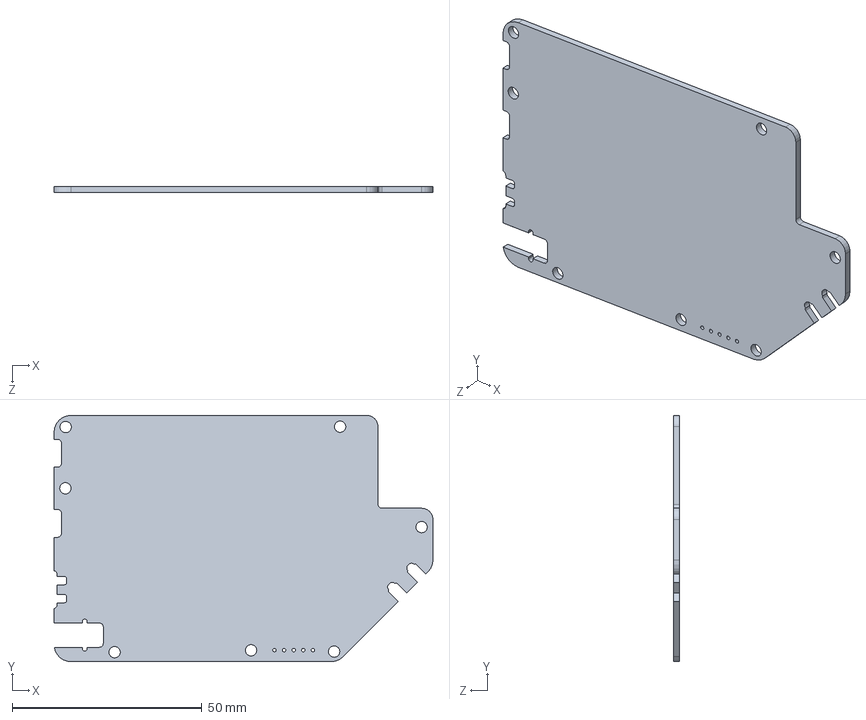
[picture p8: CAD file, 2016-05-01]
Hardware/Enclosure/PSDR2_MainBoard.SLDPRT
100.0 x 65.0 x 1.68 mm

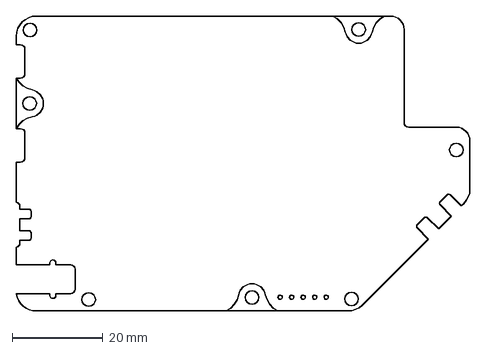
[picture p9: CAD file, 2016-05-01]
Hardware/Enclosure/PSDR2_MainBoard-Backside Housing Keepouts.DXF
100.0 x 65.0 mm

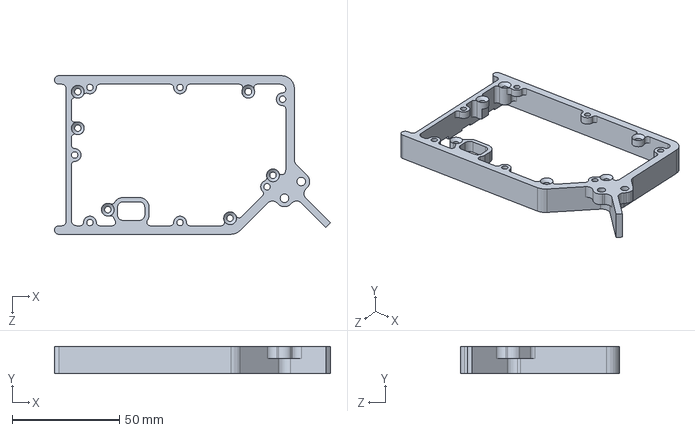
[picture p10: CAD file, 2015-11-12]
Hardware/Enclosure/Main_Enclosure.SLDPRT
128.7 x 12.7 x 74.0 mm

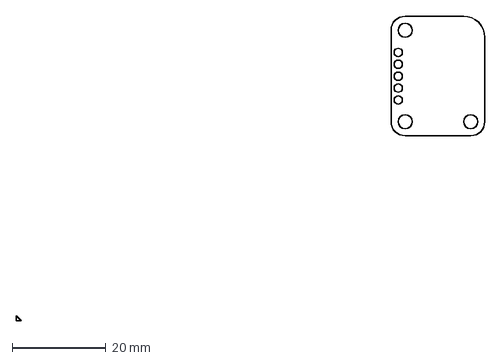
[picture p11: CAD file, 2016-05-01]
Hardware/Enclosure/EncoderBoard-offset.DXF
100.0 x 65.0 mm

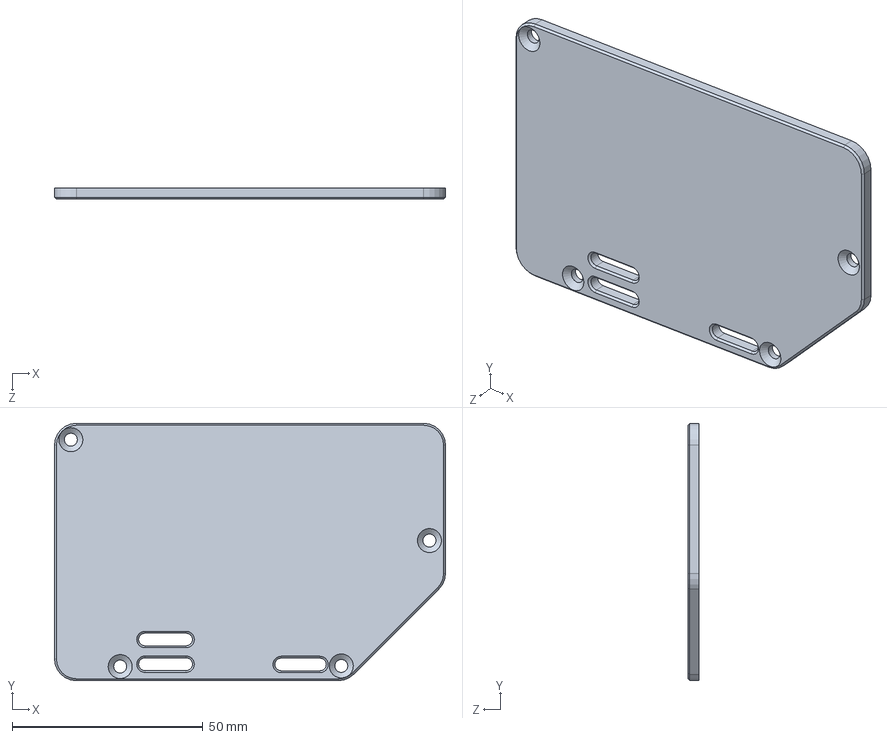
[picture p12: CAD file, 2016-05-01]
Hardware/Enclosure/Face Cover.SLDPRT
102.4 x 67.4 x 3.00 mm

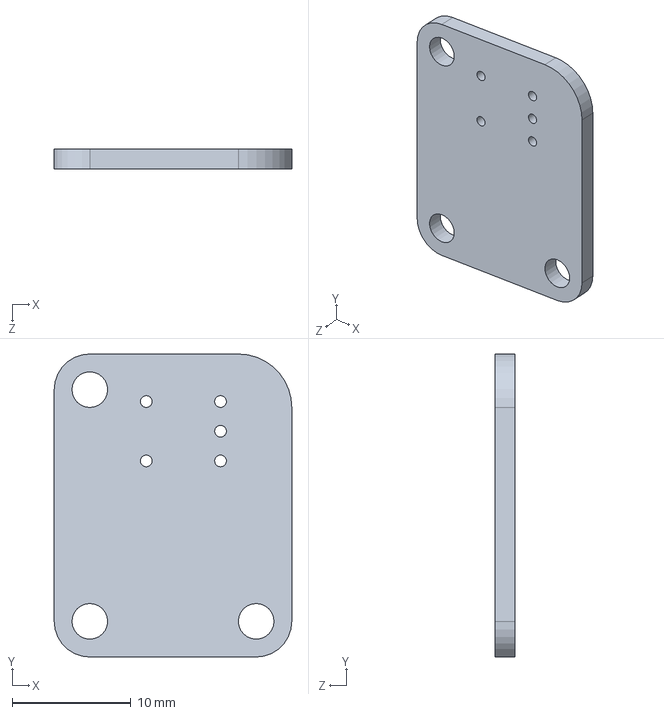
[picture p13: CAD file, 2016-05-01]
Hardware/Enclosure/EncoderBoard.SLDPRT
20.0 x 25.5 x 1.68 mm

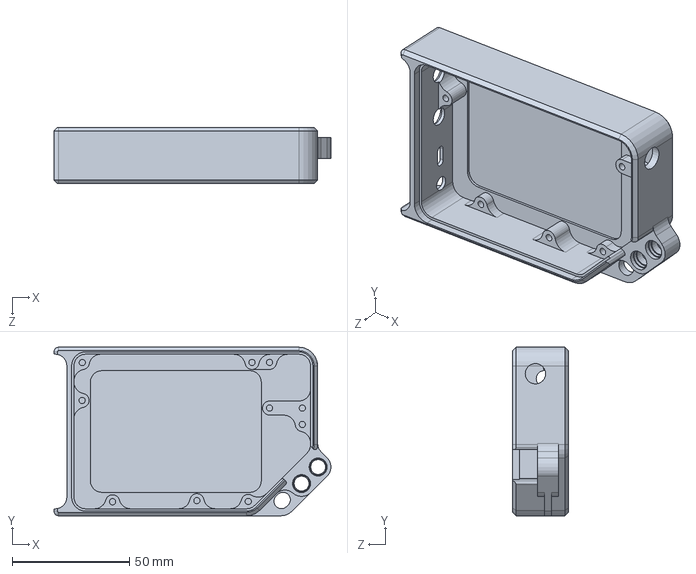
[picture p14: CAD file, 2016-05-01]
Hardware/Enclosure/BottomHalf2.sldprt
118.2 x 72.0 x 24.0 mm

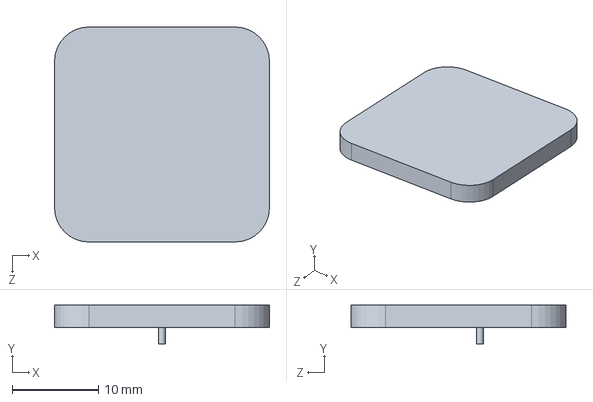
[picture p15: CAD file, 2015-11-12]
Hardware/Enclosure/GPS_Antenna.SLDPRT
25.0 x 4.50 x 25.0 mm

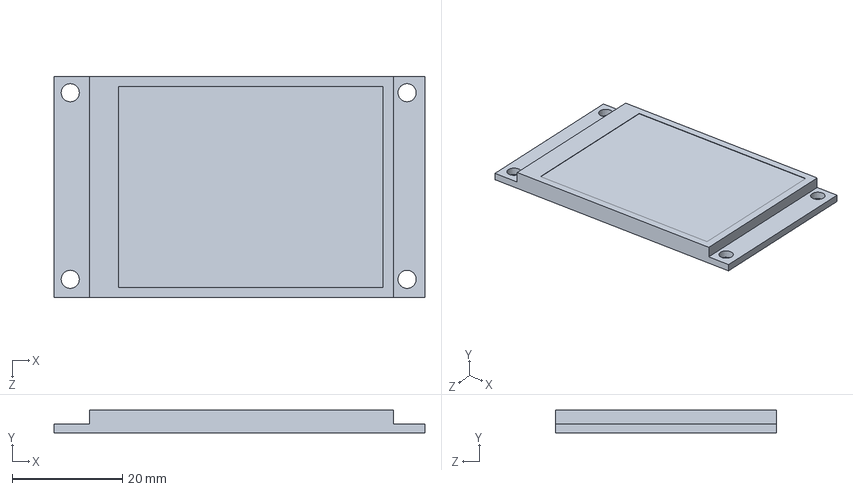
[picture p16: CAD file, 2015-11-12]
Hardware/Enclosure/2.2in_LCD_Module.SLDPRT
67.3 x 4.15 x 40.0 mm

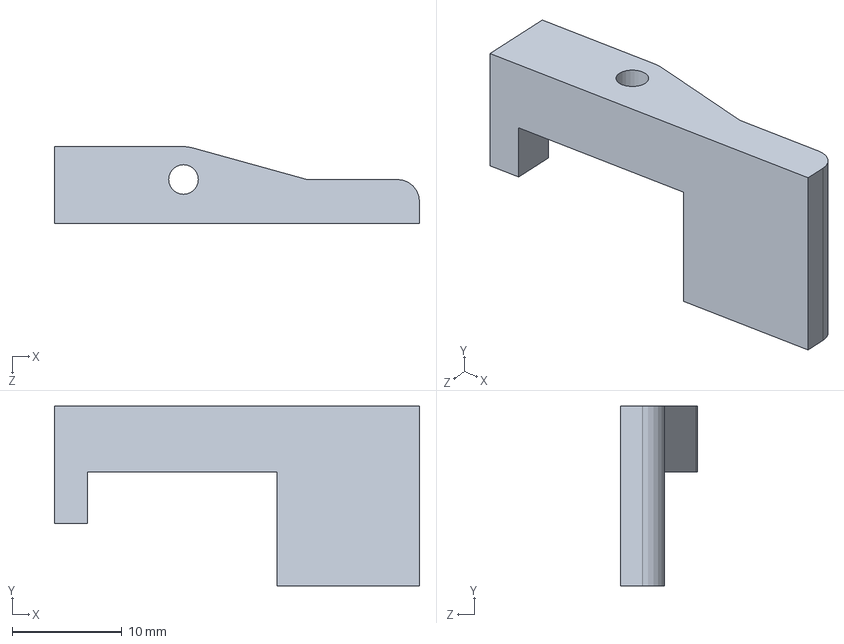
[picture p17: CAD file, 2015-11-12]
Hardware/Enclosure/paddle_Middored.SLDPRT
33.3 x 16.4 x 7.00 mm

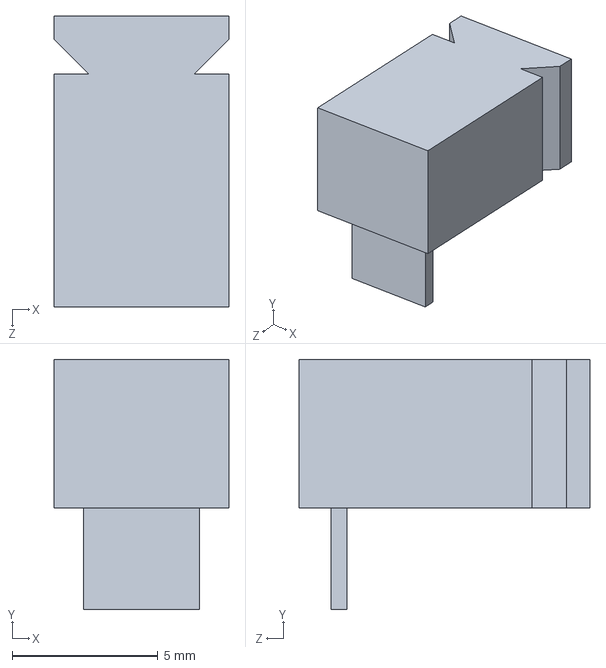
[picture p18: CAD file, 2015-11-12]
Hardware/Enclosure/Battery Connector.SLDPRT
6.00 x 8.60 x 10.0 mm

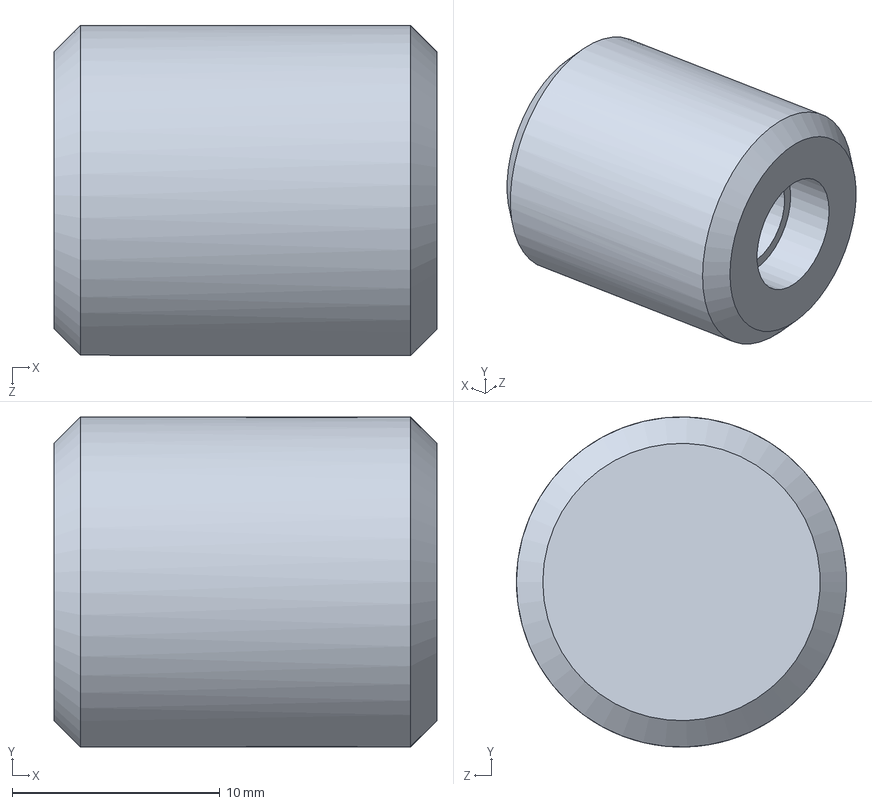
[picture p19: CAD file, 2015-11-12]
Hardware/Enclosure/knob.SLDPRT
18.4 x 15.9 x 15.9 mm

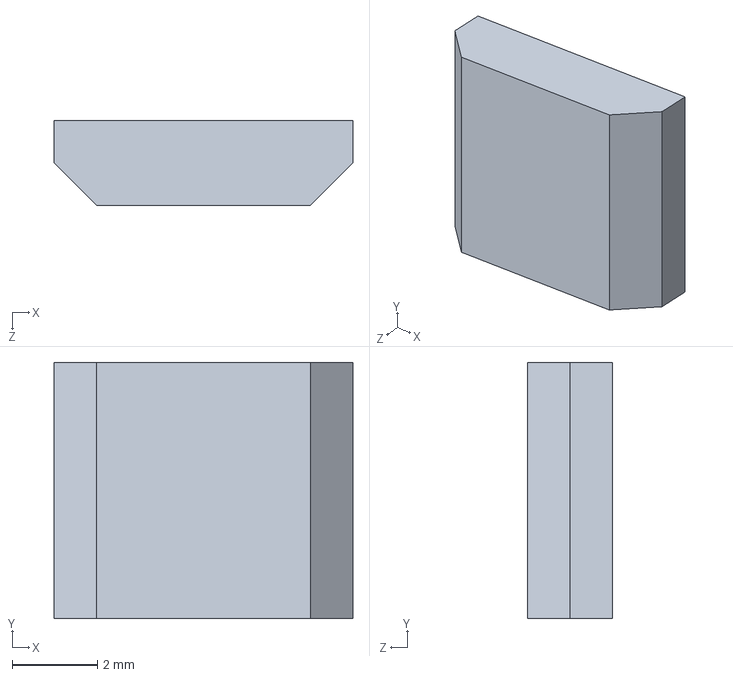
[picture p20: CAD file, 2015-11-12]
Hardware/Enclosure/MicroUSBMale.SLDPRT
7.00 x 6.00 x 2.00 mm

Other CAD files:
Hardware/Enclosure/LeeSpring-LTR028E01S.SLDPRT
Hardware/Enclosure/Bottom_Enclosure.SLDPRT
Hardware/Enclosure/paddle_Mirrored.SLDPRT
Hardware/Enclosure/GPS_Antenna_18x18x4.SLDPRT
Hardware/Enclosure/7x3x3 Bearing.SLDPRT
Hardware/Enclosure/92029A208.SLDPRT
Hardware/Enclosure/92095A183.SLDPRT
Hardware/Enclosure/93395A198.SLDPRT
Hardware/Enclosure/93395A210.SLDPRT
Hardware/Enclosure/93657A708.SLDPRT
Hardware/Enclosure/94500A222.SLDPRT
Hardware/Enclosure/95610A530.SLDPRT
Hardware/Enclosure/BNC_Adapter.SLDPRT
Hardware/Enclosure/Battery.SLDPRT
Hardware/Enclosure/Bottom_Cover.SLDPRT
Hardware/Enclosure/Encoder.SLDPRT
Hardware/Enclosure/EncoderBoard.DXF
Hardware/Enclosure/Knurled_Knob.SLDPRT
Hardware/Enclosure/LCD_Standoff.SLDPRT
Hardware/Enclosure/LeeSpring-LTL015B08S.SLDPRT
Hardware/Enclosure/Other Spring Thing.SLDPRT
Hardware/Enclosure/PSDR2_MainBoard.DXF
Hardware/Enclosure/Slotted_Knob1.SLDPRT
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

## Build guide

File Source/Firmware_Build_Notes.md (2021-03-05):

Firmware Build Notes
====================

* Install gcc-arm-none-eabi: apt-get install gcc-arm-none-eabi, or download from https://launchpad.net/gcc-arm-embedded/4.7
* Download Eclipse Kepler, v4.3 for C/C++ dev from https://eclipse.org/downloads/packages/release/Kepler/SR2
* Help -> Install New software
* add Name: GNU ARM, Location: http://gnuarmeclipse.sourceforge.net/updates
* Click the radio button, and hit next, next, agree to the license, finsh, Hit OK to allow unsigned contents
* Restart eclipse
* Help -> Install New Software
* same as before,add: Name: Zylin Embedded CDT, Location: http://opensource.zylin.com/zylincdt 
* sudo apt-get install openocd
* File -> import -> Existing Projects into Workspace (May be a better way here!)
* Navigate to the PSDR/Source directory and add it.
* hit Build All

You should end up with PSDR/Source/Debug/PSDR.elf  which is the binary firmware file

TODO: Flashing firmware to the PSDR instructions

New Architecture Build Instructions (WIP):

Windows:
1. Install the GNU Tools ARM Embedded. Add bin (not arm-none-eabi/bin) to path?
2. Navigate to firmware directory in shell and execute: make
3. Use whatever editor you want for the files

For eclipse:
1. File->New->Project...
2. C/C++->Makefule Project with Existing Code, "Next"
3. Browse to the root directory of the PSDR firmware
4. I have been selecting "Cross ARM GCC" not sure if that's needed. "Next"
5. Right click on the project in the Project Explorer and select settings. In C/C++ Build, uncheck "Use default build command" and type "make" (or "make VERBOSE=1") without the quotes. Clock "OK"
6. Try to build the project: CTRL-B or Project Menu->Build-All or right click on the project->Build Project
7. TODO: Set up debugging. Fix all the error messages that come up.
For some reason this doesn't work for me unless I build it at least once from the command line. Also, if I do a make clean, I have to build from the command line. More to learn!

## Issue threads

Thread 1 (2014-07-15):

Create Assembly Drawing for PSDR1

MichaelRColton, 2014-07-15:
Some of the silk screens can be a little confusing, so an assembly drawing would be helpful.

MichaelRColton, 2017-01-07:
I probably won't bother with the drawings for the PSDR1 (if the three of you that have one really need one let me know!) but I did make instructions for the PSDR2.6. Find it here: https://github.com/MichaelRColton/PSDR/blob/PSDR_F7/Documentation/Assembly%20Instructions.pdf

Closed 2017-01-07.

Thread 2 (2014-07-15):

Create PSDR1 Assembly Notes

MichaelRColton, 2014-07-15:
This should include the changes to the PCB (VSS/VDD swap on MCU, and Grounds on DDS1-2) and all jumpers. Pictures wouldn't be a bad idea.

MichaelRColton, 2017-01-07:
Again, not going to bother at this point. If someone really needs them, let me know. Some documentation is available in the updates on the hackaday.io page here: https://hackaday.io/project/1538-portablesdr#menu-logs

Closed 2017-01-07.

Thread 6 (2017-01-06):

S meter pinned on USB with filter bottom at 0

pwarren, 2017-01-06:
S meter is pinned to halfway between +20 and +30 Db over 9. Moving the bottom of the filter up to '40' and it moves around with some bearing on the received signal! (PSDR_F7 branch)

MichaelRColton, 2017-01-07:
Are you saying it's always stuck there? On mine it moves around a lot (though the numbers don't correspond to anything yet.)

pwarren, 2017-01-07:
Heh ok, and I just noticed it doing the same thing on AM mode as well!

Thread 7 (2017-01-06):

Project organisation: Licensing, Contributions etc

pwarren, 2017-01-06:
Figured I'd put up an issue for this.

I'd like to get a CONTRIBUTING.md file going, probably based on following https://mozillascience.github.io/working-open-workshop/contributing/

It would be a good idea to set the licensing terms for the code too, and make clear which parts are under which license (eg. GPLv2 or higher not appropriate for the shematics or gerbers, works for the code, but DSP_Lib is BSD(?) licensed, etc)

Code layout and design, I've been very impressed by the code in the mCHF repos: https://github.com/df8oe/mchf-github, which may have some ideas for us!  (In particular, I'm struggling with how to add FM mod/demod, including subaudible tones etc It's not clear to me from the current code, which may say more about me than the code!)

jeffersonbenson, 2021-02-19:
#15 seems to be accomplishing this, pending any necessary changes.

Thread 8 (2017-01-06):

Persistent state storage

pwarren, 2017-01-06:
It'd be nice to have the last used menu settings come back when the radio's turned on, with a way to reset it too I guess.

I'd imagine we'd need a menu state struct, which can be written to FLASH memory at some interval, maybe a second or so after a change?

MichaelRColton, 2017-01-07:
Agreed. Depending on what power state we drop down into, we may be able to preserve those things in memory without too much of a hit to standby current.

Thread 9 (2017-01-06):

Proper Off menu item and 'Turn On' gesture

pwarren, 2017-01-06:
While my current implementation of an off button 'works' it doesn't seem to preserve the battery much more than a day or so.

Also, I need to figure out how to get the unit into a state that can monitor the buttons for the turn on gesture, I don't think my EnterSTANDBYMode() can do that, it appears to only be able to look for rising edges on the PA0 pin or interrupts.

MichaelRColton, 2017-01-07:
I haven't had time to look at or play with your new code yet, but I think I remember you mentioning turning off peripherals. Were you talking about those internal to the MCU, or the various external devices attached to the MCU?

I didn't design the PSDR with an eye for excellent standby efficiency (not that I don't want to, it just wasn't high on the list and I had other things to worry about) but I did include the ability to kill power to many of the sub systems on the board (via MCU controlled FETs), and some of the chips can be turned off by setting them to lower power states via whatever bus they are connected to.

I was pretty sure that the pins I used for the encoder switch, and maybe (hopefully!) the paddles supported pin change interrupts that should be able to wake the MCU, but I am not positive. Also potentially helpful would be slowing the clock way down, and setting up a routine that, for example, wakes the MCU on the first pin change event, then quietly watches for the other events in the gesture (whatever form that ends up taking) before bringing itself (and the other subsystems) up the rest of the way. If it doesn't see those other events within a certain time window, then it assumes that first event was unintentional and goes back to sleep.

I think the boards draw around 8mA (is that right?) before they are programmed, so that might be as low as we end up getting, but that should give 10ish days, which I think would be reasonable at this stage of development.

pwarren, 2017-01-07:
All I've done so far is do the opposite of the setupPeripheralPower() function, i.e: __GPIO_CLK_DISABLE() etc etc. then call HAL_PWR_EnterSTANDBYMode(). Not sure how much it helps, but It does recover when the reset button is pushed for at least a few hours after turning it off.

I should have a bit of time this week to look a things in a bit more depth for power management, after I get myself together for my https://linux.conf.au/ miniconf presentation. I'll definitely be showing off the PSDR while I'm there :)

MichaelRColton, 2017-01-15:
I made a mistake in my measurement before (I was using a different meter and misread it) so it draws ~80mA before it's programmed, and that's about what your turn-off code gets us down to.

Some thermal imaging shows that our biggest power consumption is the frequency synth chip (U241: SI5338). Pretty sure that can be powered down in code.

The LCD control circuitry is wasting some power (not sure if there is a command to power that down), not including the backlight.

Also bad are the phase/mag chip (U314: AD8302), And the AD8131s (U260 and U253) and there isn't anything that can be done by the MCU to power them off.

Looks like I have some changes to make in the next rev.

We'll want to issue a command to put the SI5338 (and LCD if possible) into a lower power state, and then I don't think we'll get a whole lot lower than that.

And, of course, getting the wake-up gesture going. (P.S. Sometimes hitting reset didn't see to want to wake it, not sure why...)

Top side with LCD
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
Top without LCD (that bright spot in the middle is the heat from the back of the SI5338)
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
Bottom
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

sanamon, 2017-01-18:
I know it's not so high-tech, but perhaps an old-school switch between battery and radio would solve the problem?  :-)

jeffersonbenson, 2021-02-01:
Gonna see if I can revive this thread :grin:
Is the goal here to work something like (https://github.com/chacal/stm32sleep) where there is a low-power SLEEP state and then a WAKE gesture?
Based on the circuitry, there isn't really a great way to completely disconnect the device from the battery. At this point it looks like the best we can do is get it to a low enough power state for short to medium-term storage, and then advise users to bring a spare battery pack?

jeffersonbenson, 2021-02-04:
To follow up on my above comment, couldn't you also just add a slide switch inline with the battery and have it poke out the "front" of the case, over by the rotary encoder? See below crude mockup:
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

sanamon, 2021-02-04:
Hi,

I’m sure it’s the easiest route at least.

But i’d start by looking into the preamp issue (preamp not enabled, perhaps by not bing initialized in software) as this thing is deaf as a brick right now (sensitivity around -70dBm if I remember correctly, indicating 50 dB “missing”)

Regards
Jonas

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

jeffersonbenson, 2021-02-04:
@sanamon I see what you're saying with regards to the preamp issue. Perhaps something that can be brought up in a separate issue for further discussion?
For the issue at hand finding a compatible switch is the quickest way to power the whole device off.

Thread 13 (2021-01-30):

Obsolete parts in 2.6.1 BOM

jeffersonbenson, 2021-01-30:
While compiling a BOM for an upcoming 2.6.1 build, I discovered that the following parts are obsolete according to Digikey and do not have replacements available. Further investigation will be required in order to find suitable replacement parts.

Parts not found:
599-1068-1-ND  - RF amplifier U304
1465-1374-1-ND - RF DPDT Switch U16, U24, U30

jeffersonbenson, 2021-02-19:
Found the following outside of DigiKey, which is annoying but nevertheless it can be found

599-1068-1-ND - RF amplifier U304
SXB-2089Z
https://www.win-source.net/rf-amplifiers-sxb-2089z.html

1465-1374-1-ND - RF DPDT Switch U16, U24, U30
MASWSS0129TR-3000
https://www.richardsonrfpd.com/Products/Product/MASWSS0129

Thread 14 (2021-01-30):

Missing parts in 2.6.1. BOM

jeffersonbenson, 2021-01-30:
The following parts are marked as either NA or DNS in the BOM. Have they just been removed and the BOM needs to be updated?

CAP_0603 - C307, C320
RES_0603 - R72, R79

jeffersonbenson, 2021-02-19:
So after learning a few things about reading BOMs, the NA seems to mean "just leave it open" and DNS means "do not stuff".

My only concern would be that there needs to be something to bridge the connections here like a 0ohm resistor or something. I'll need to investigate the traces.

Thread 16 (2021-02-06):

Enable Pre-Amp in Firmware

jeffersonbenson, 2021-02-06:
But i’d start by looking into the preamp issue (preamp not enabled, perhaps by not bing initialized in software) as this thing is deaf as a brick right now (sensitivity around -70dBm if I remember correctly, indicating 50 dB “missing”)

DM2NT, 2021-12-06:
I think Michael hasn't worked on this project for a long time. I also have a PSDR here. But like all the others, it's just a paperweight.

MichaelRColton, 2021-12-06:
It's true, I've become busy with other projects and the PSDR hasn't gotten
much of my time recently. Jeff is correct, the preamp/low-pass filter
circuit isn't working. I had it working on development hardware, but my
efforts to get it to operate properly on the production board didn't reach
completion. That would certainly be a great place to focus attention for
anyone that is interested in assisting with development.

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

DM2NT, 2021-12-06:
Is it very complicated to activate the preamp? Unfortunately I don't have a Windows computer to run the development environment.

MichaelRColton, 2021-12-07:
Well in theory it shouldn't be too hard. Though it's certainly not as easy
as turning on power to it. There are RF switches that need to be
configured, and the pre-amp/low-pass filter IC has a lot of configuration
registers and things that have to be set correctly. The frustrating part is
that I had built one up on a dev board I made, ran some test code on it and
verified it was doing what I wanted (in this case, I was more focused on
the low-pass filtering part, but it did demonstrate the chip was working.)
but when I tried to do it on the production PSDR, I had trouble getting it
to work. I'm not sure what the problem is. And right now I just don't have
the bandwidth to work on it.

Most of my code is not in the main branch on github, btw, make sure you
look at them to see where the most recent activity is.

It might be worth putting on external pre-amp on the PSDR to see if it
performs better with that there. Where I live the bands are so noisy (S9+
most of the time) that the PSDRs sensitivity is actually fine, any signal
that can get through that shows up on the PSDR. I didn't realize at the
time that the sensitivity was a problem.

I am, by no means, an expert in RF/Radio design. If anyone makes
modifications that improve performance, I would love to know about them.

There is another project, called uSDR (there are some variations on it)
that pulls off pretty good performance with simpler circuitry than the
PSDR, and includes a very efficient amplifier design, something the PSDR
almost completely lacks. When I have some time, I'm interested in taking
what is (in my opinion) superior on the PSDR (the screen, processing power,
waterfall, ergonomics, case design, etc.) and merging in what I can from
the uSDR (simpler design, better sensitivity, better output power and
output filtering) into a next generation PSDR that could actually meet the
design goals I had for the original. But that may be a ways down the
line....

-Michael

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

DM2NT, 2021-12-09:
Hi Michael,

I also know the uSDX. Unfortunately, it doesn't offer a good display interface. I don't want to do without the waterfall display. Andreas DF8OE has already implemented the HMC1023 in his UHSDR. Here is the link to the Github: https://github.com/df8oe/UHSDR/tree/active-devel/mchf-eclipse/hardware

Maybe you can already use a part here.
However, I still don't have a Windows computer ...

petermccracken, 2021-12-09:
... I think a Malahit is what you want, either the original or there is one of the china clones which is as good as the original. There's a very active group of FB. Also google teensy convolution sdr if you really want to get into it.

petermccracken, 2021-12-09:
Also have a look at the mcHF group on FB, if you look through the posts there's a Russian guy who is selling modified kits for the mcHF with a 4" display, looks very good. There are heaps of possibilities and projects out there.

MichaelRColton, 2021-12-09:
DM2NT, Yes, I agree the uSDX interface is lacking (and in my opinion, the
ergonomics, case design, and the microcontroller is very underpowered,
thought they've managed to do an impressive amount with it) the idea I'm
playing with is merging the PSDR and the uSDX, but it will be a while, or
may never happen at all. Also, you don't need a Windows computer to work on
the PSDR, I just don't have instructions for other environments. Any guide
on doing STM32 development for your platform will likely work.

Peter, the Malahit looks pretty cool, but looks like it has rather
different goals from what I hope the PSDR eventually becomes. I am aware of
the mcHF, it's a nice project for sure. Interestingly, KA7OEI, the guy that
overhauled the mcHF, hugely improved its software (and maybe hardware too?)
lives not far from me and I've talked to him about the PSDR. He said he's
willing to take a look at it, but we haven't really made it happen yet.

-Michael

On Thu, Dec 9, 2021 at 9:21 AM petermccracken ***@***.***>
wrote:

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

sanamon, 2022-07-04:
> Unfortunately I don't have a Windows computer to run the development environment.

You dont need windows to do this. If You have a Linux machine, see https://github.com/MichaelRColton/PSDR/wiki/Linux-build-instructions

Cheers,
Jonas

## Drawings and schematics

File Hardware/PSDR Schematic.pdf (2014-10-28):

# TODO:

# Rename pins and stuff

## Look into variable band pass filters (switched cap?)

## consider a mixer to enable 2m (or other) freq operation

# Add light sensor for backlight, you know?

# Change frequency antialiasing filters

# Change over to new LCD

# Add temperature sensor near freq reference add second freq ref?

# add comparitor to freq ref output? (or use one with square output)

Consider switching to that frequency generator part that everyone else uses with 4x divider?

# Add ability to turn off subsystems (like RF)

# Add some kind of RF out amplifier?

# Look into magnetic encoder

# antenna tuner?

# DONE:

# Clean up schematic (to resemble block diagram)

# Later?:

## parallel display conflicts with DAC on most parts (unless you go to 144pins or more)

# so should I add a dac/codec or bag the parallel display for now?

bag it for now.

# multitap inductor?

# NOTES: Analog dies at about 2.3v Digital also dies at about 2.4v, but the display becomes very dark at 2.7~

Looks like life is pretty good at 2.9v.

# Add test points to relevent locations

# Add fiducials. Oops!

Try bottom entry LCD connector turn encoder on its side smaller GPS antenna Power cuttoff circuit fix charge voltage divider thing see if you can bring half-vcc to one of the microcontroller ADCs do I like using half-vcc, or just putting voltage dividers all over the place? The mic preamp ouputs a bias voltage, okay for external mic, how about for the mems mic? I really need to characterize the antialiasing filters - DONE: 3db cuttof is 15-16kHz! adjust charge circuit resistors to make sense (current limit, charge rate, etc.) Consider changing freq synth topology, maybe PLL with div2 I/Q splitter? detect charger type (usb type) and adjust charge current appropriately? A few parts are too close together Should I consider 0402s? IN_AMP_ENABLE Doesn't make it to the MCU!!!! GAH! Doesn't there need to be a half-vcc bias on the mic filter out?

Did I forget to route the external mic out to the microcontroller? (to detect button presses?) :/

# Is the mems mic okay with a bias from the preamp? Maybe not. Put cap inline? No bias on external mic. Really? :/ Look into AD9958? We probably want the AMP power line to come from the battery, not from 3v3

# GPS Interface

## Vbat is for backup battery, but since the 3v3 reg is always on

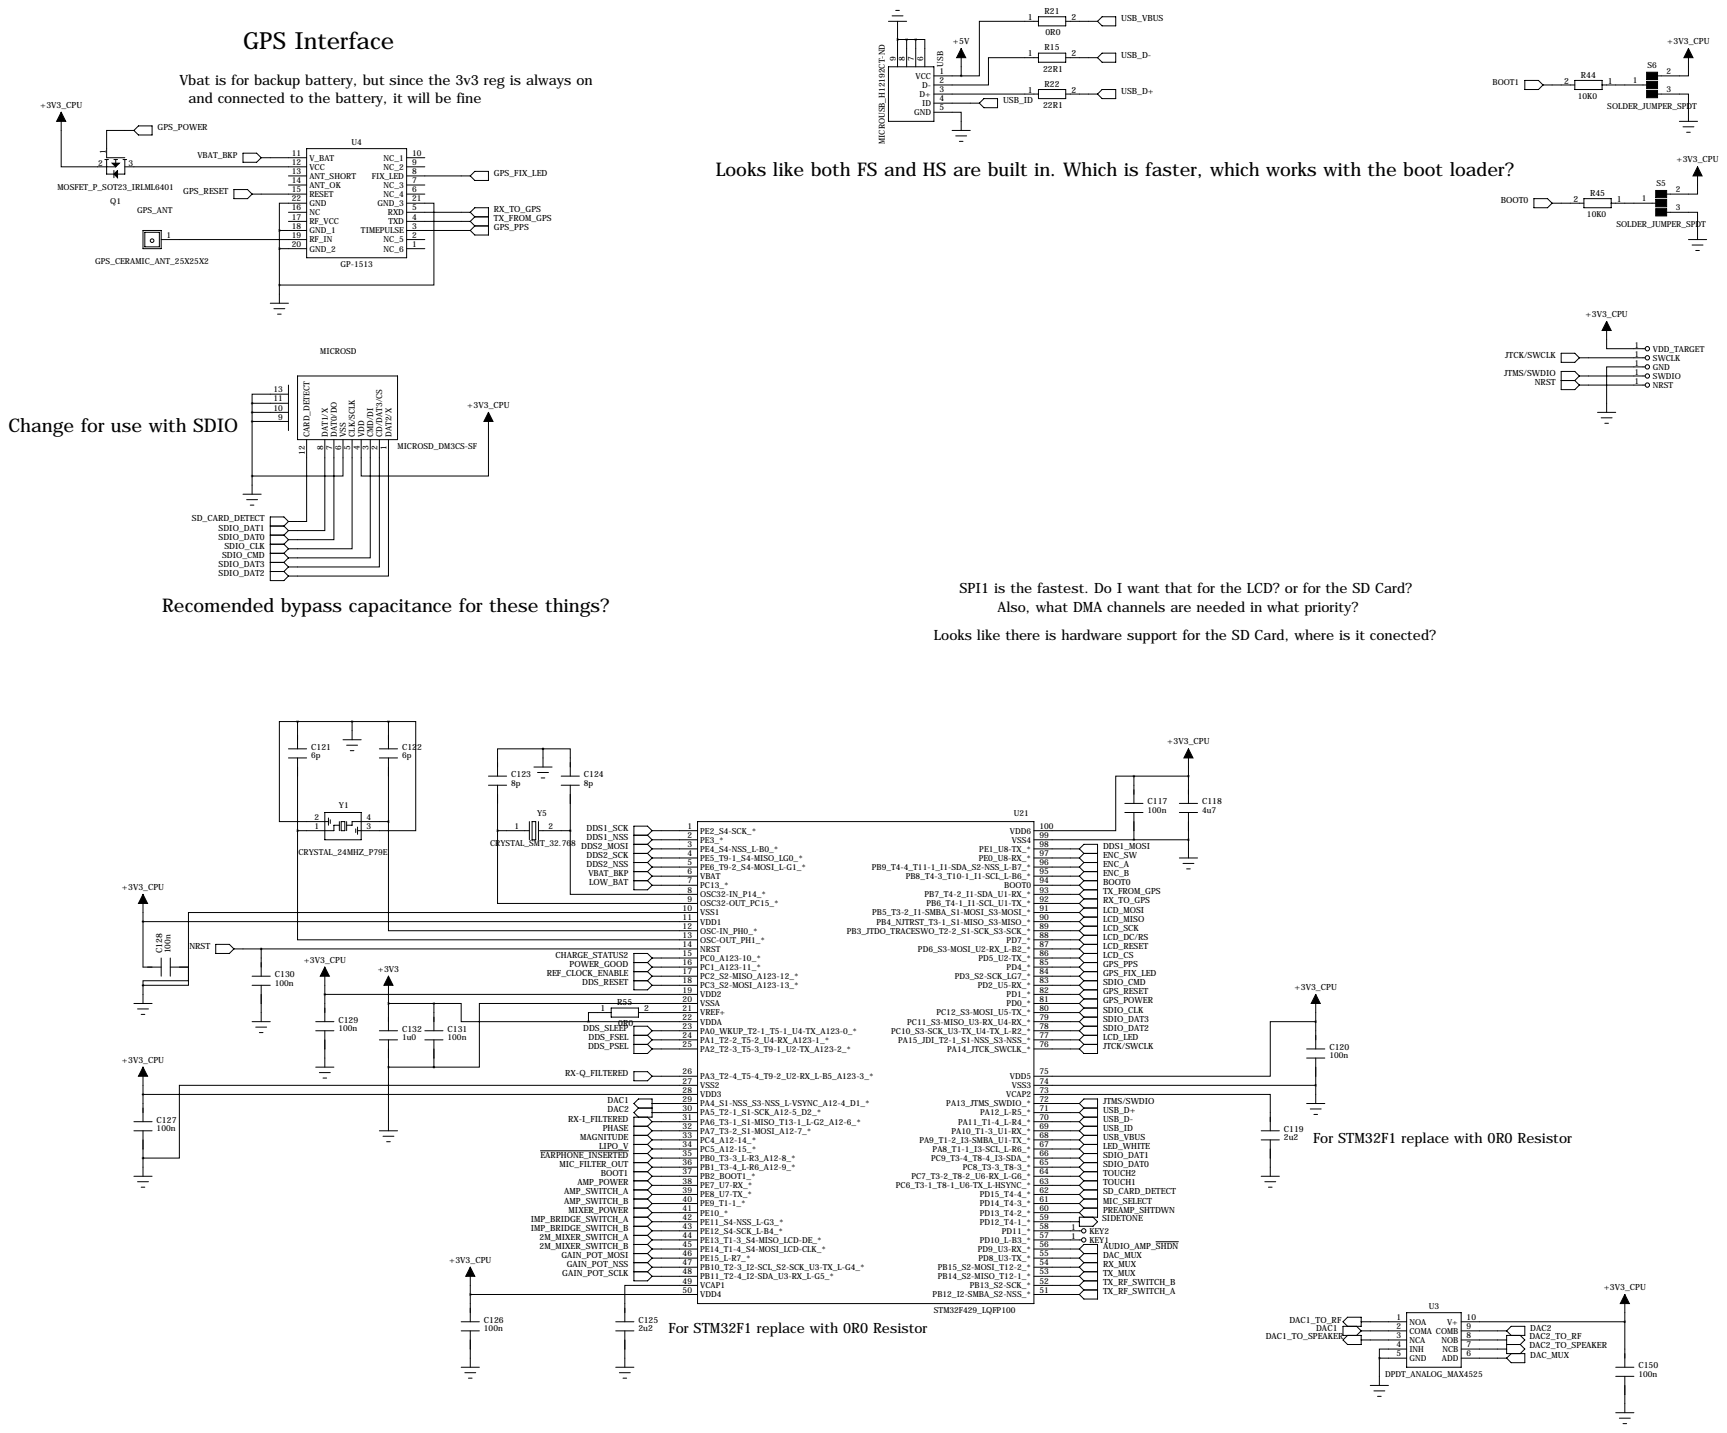
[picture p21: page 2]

and connected to the battery, it will be fine

Looks like both FS and HS are built in. Which is faster, which works with the boot loader?

Change for use with SDIO

SPI1 is the fastest. Do I want that for the LCD? or for the SD Card?

Recomended bypass capacitance for these things?

Also, what DMA channels are needed in what priority?

Looks like there is hardware support for the SD Card, where is it conected?

For STM32F1 replace with 0R0 Resistor

# 75 Mhz Clock Circuit

# 70 Mhz LPF

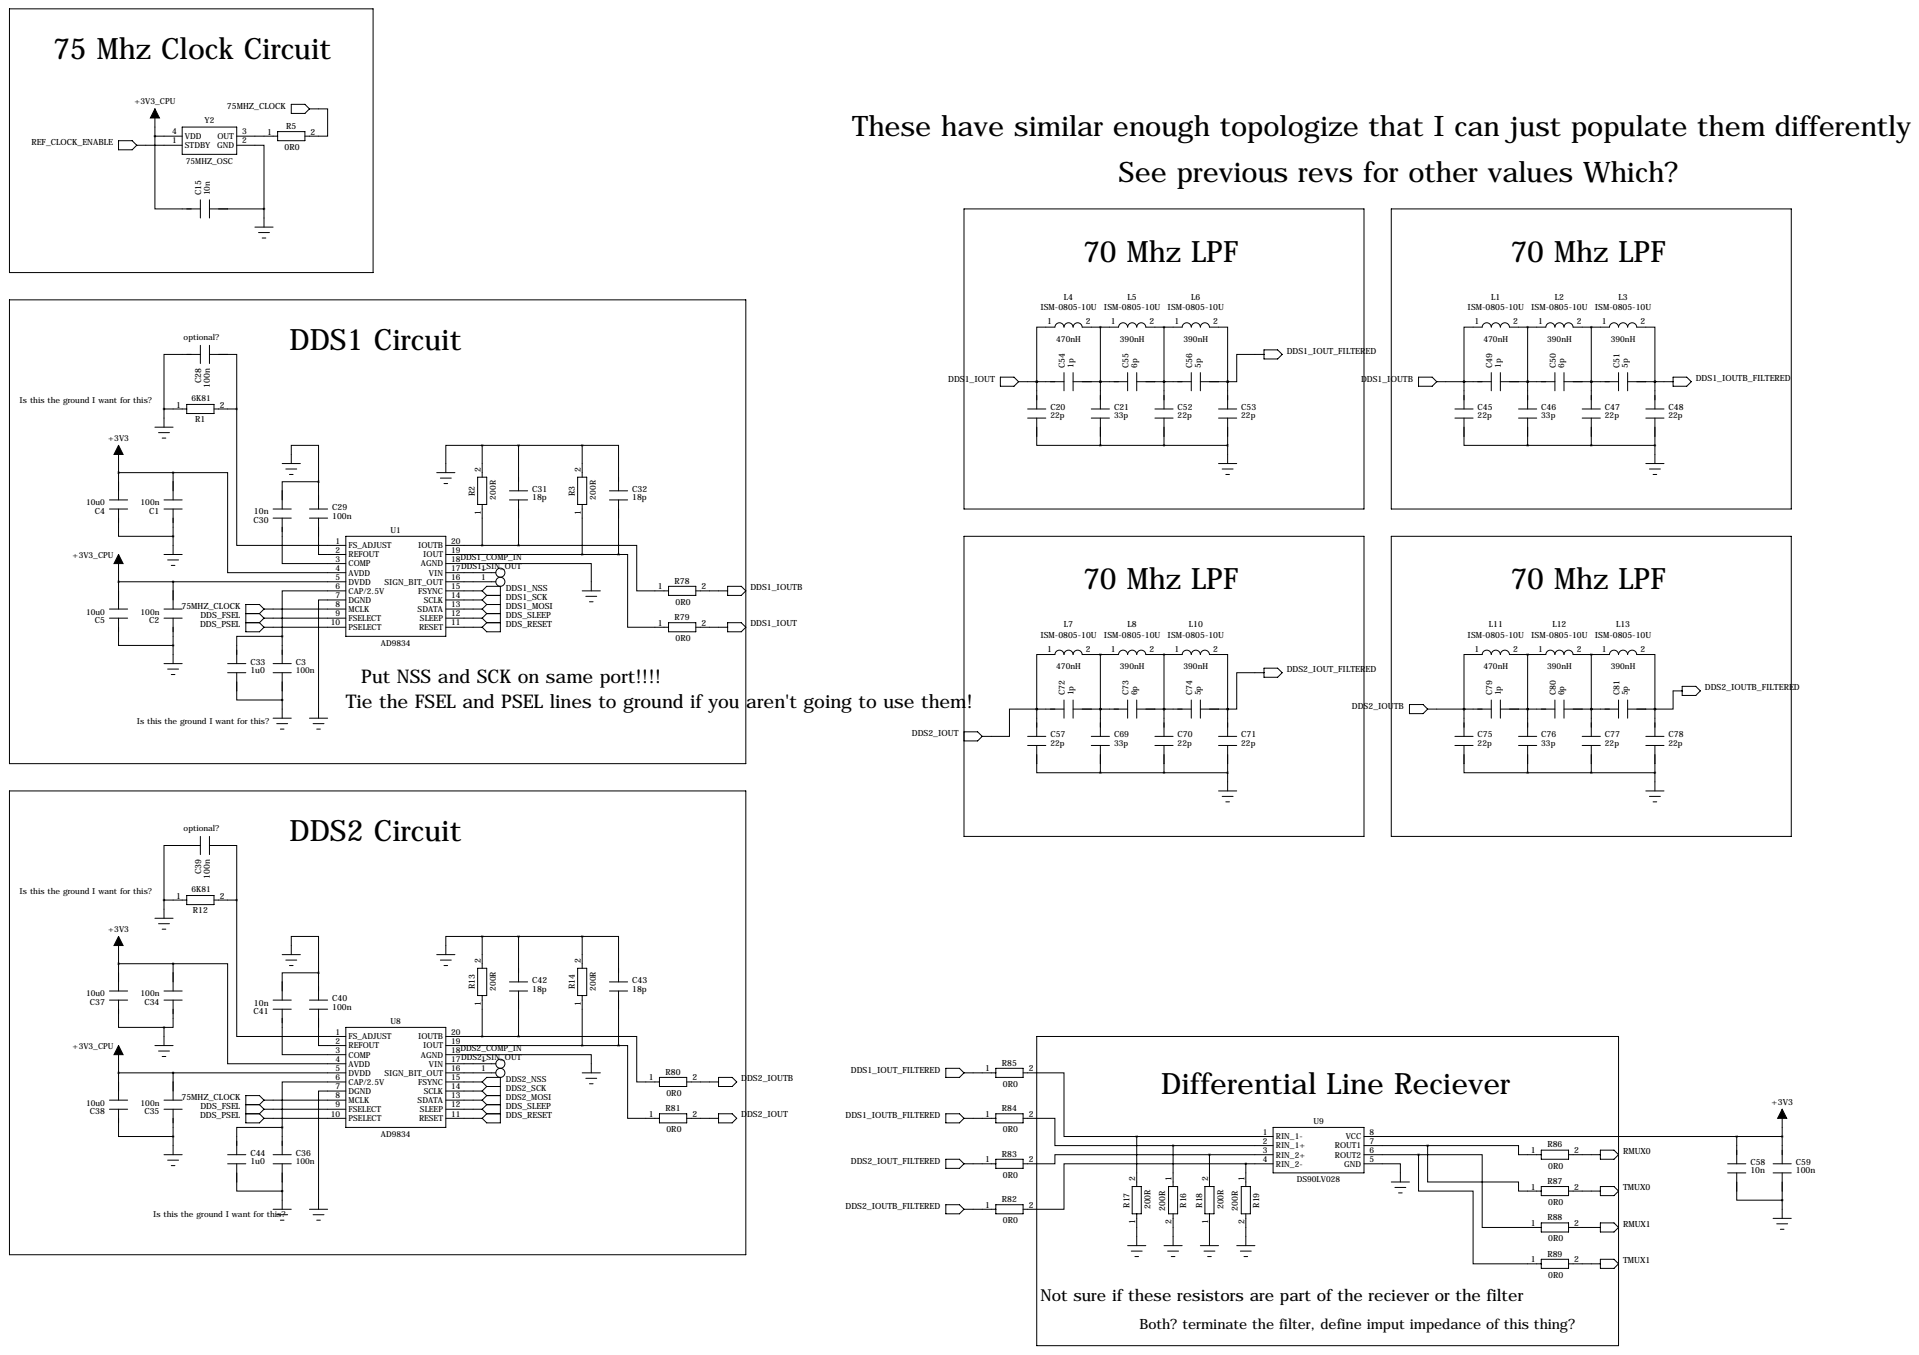
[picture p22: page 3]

These have similar enough topologize that I can just populate them differently

See previous revs for other values Which?

Is this the ground I want for this?

Put NSS and SCK on same port!!!!

Not sure if these resistors are part of the reciever or the filter

Both? terminate the filter, define imput impedance of this thing?

# Do I want analog or digital 3.3?

# RX-I Signal to AA Filter

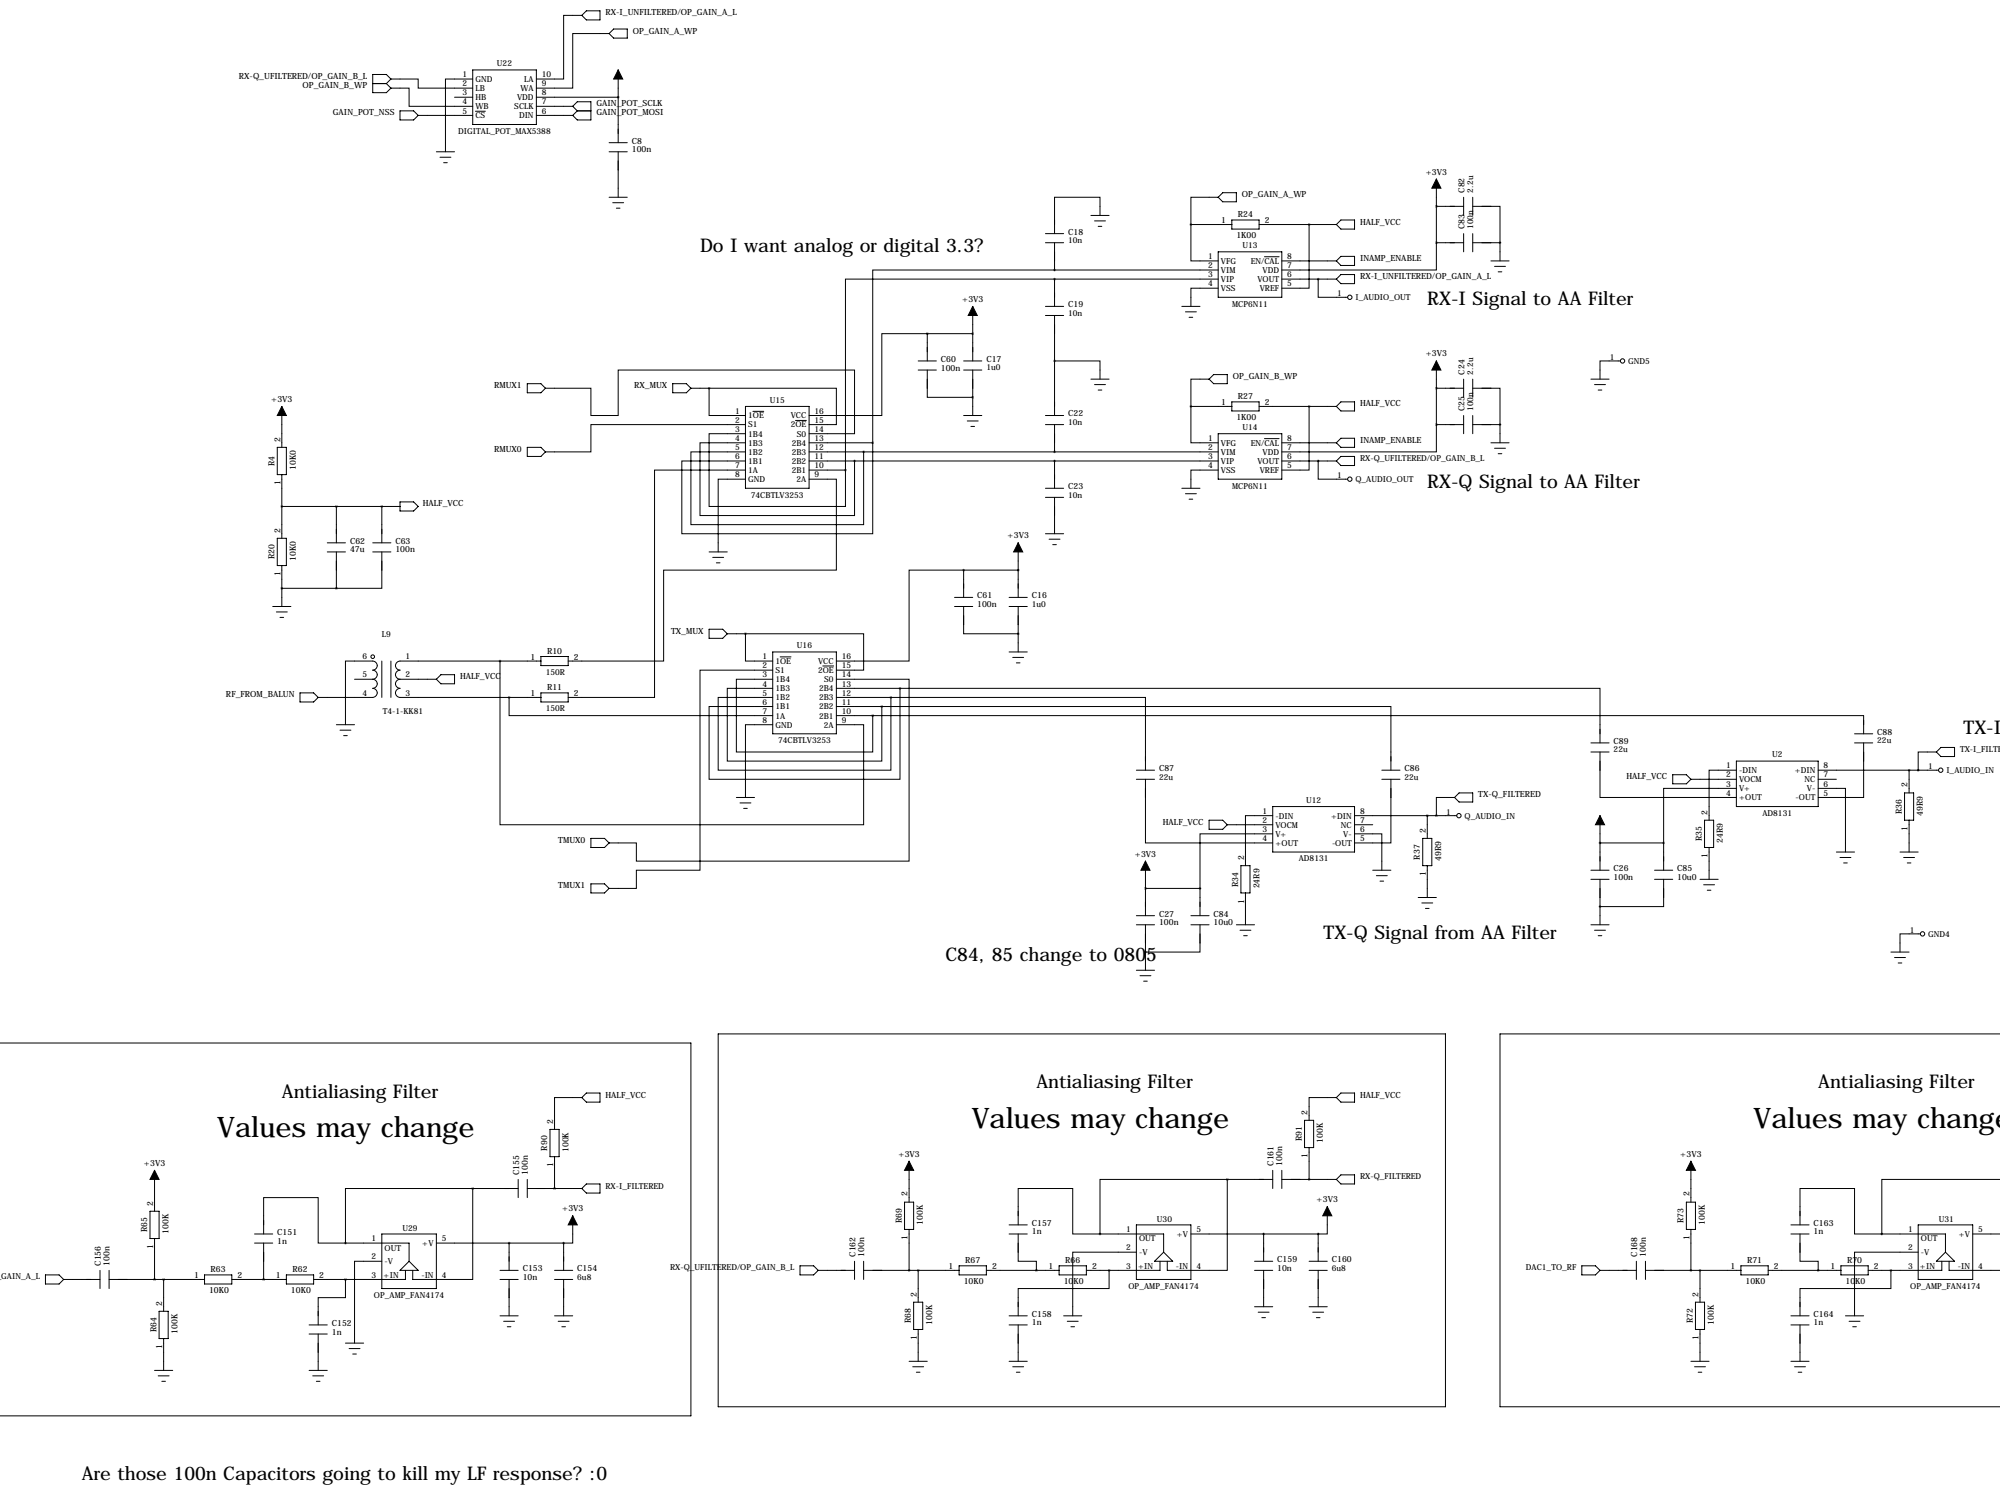
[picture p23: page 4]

RX-Q Signal to AA Filter

TX-I Signal from AA Filter

TX-Q Signal from AA Filter

Are those 100n Capacitors going to kill my LF response? :0

Antialiasing Filter | Microphone Preamp

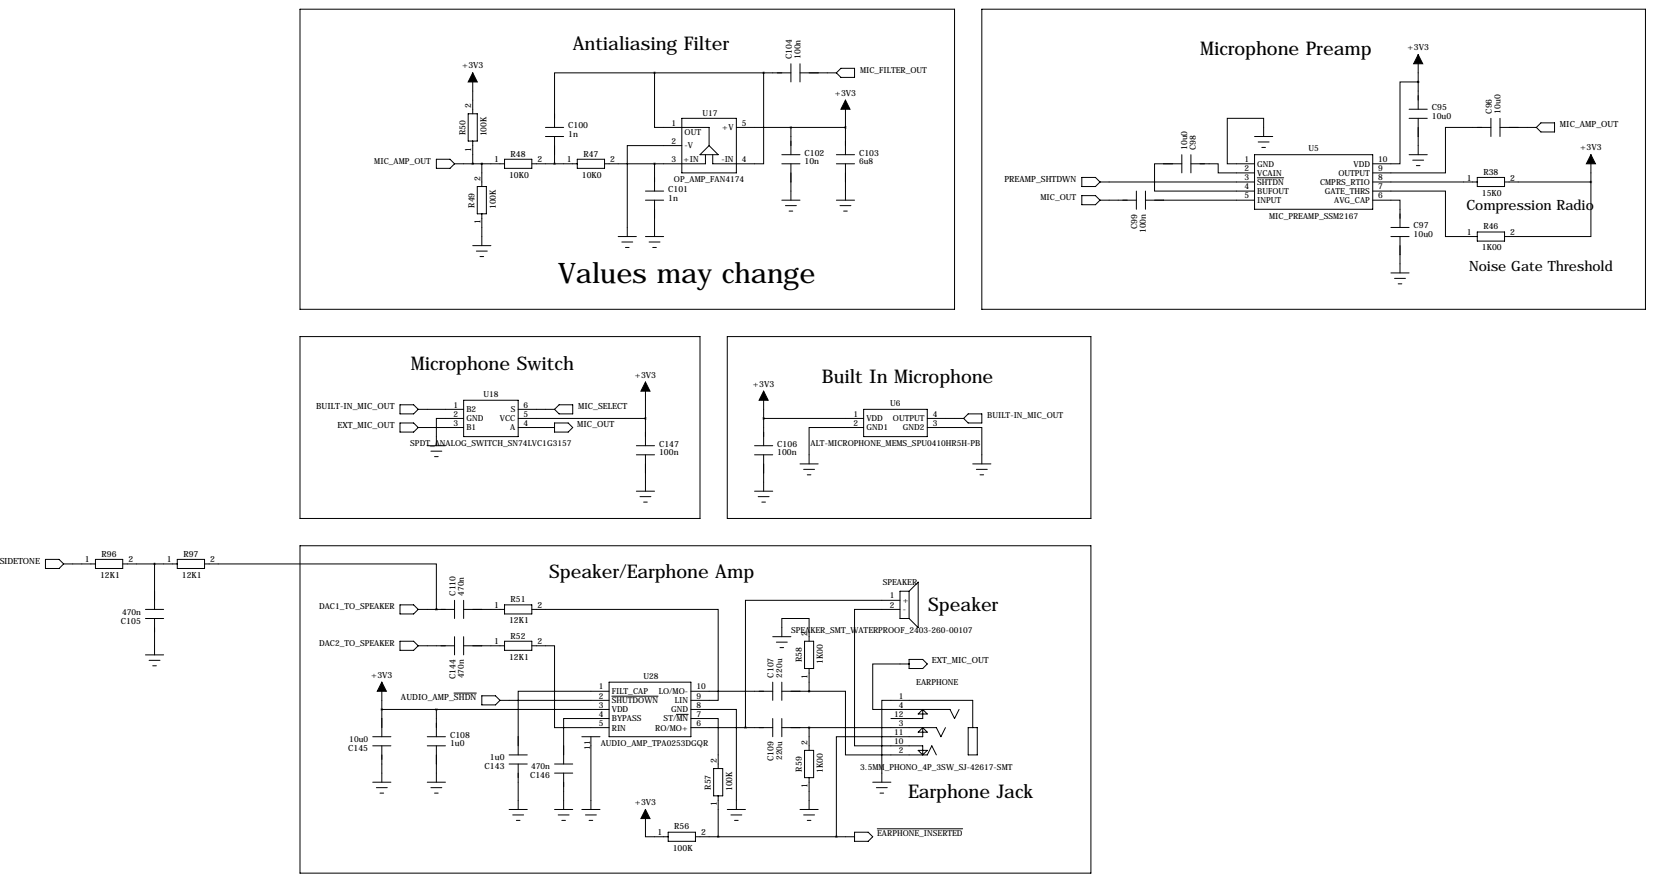
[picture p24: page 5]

Noise Gate Threshold Values may change

Built In Microphone Microphone Switch

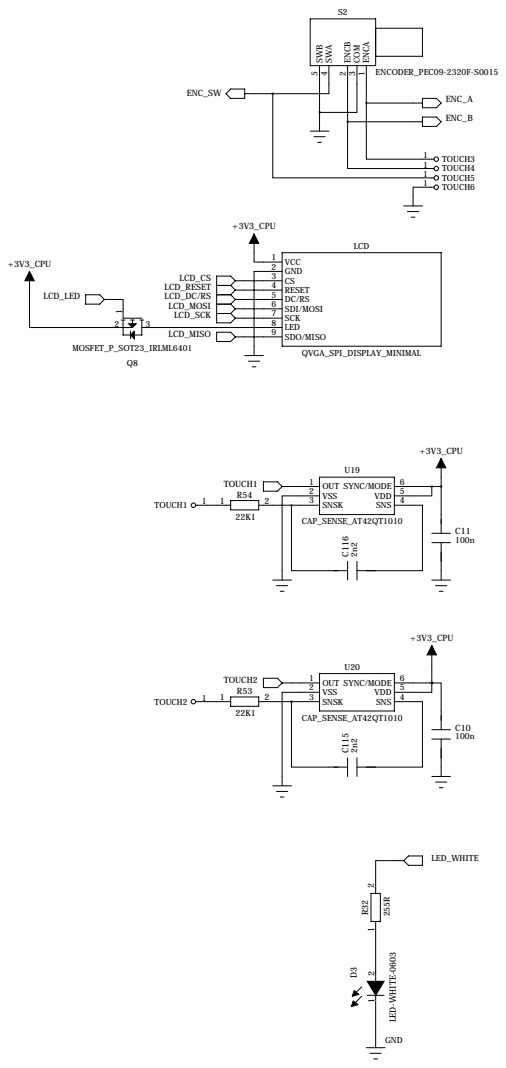
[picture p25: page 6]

# VBackup Supply

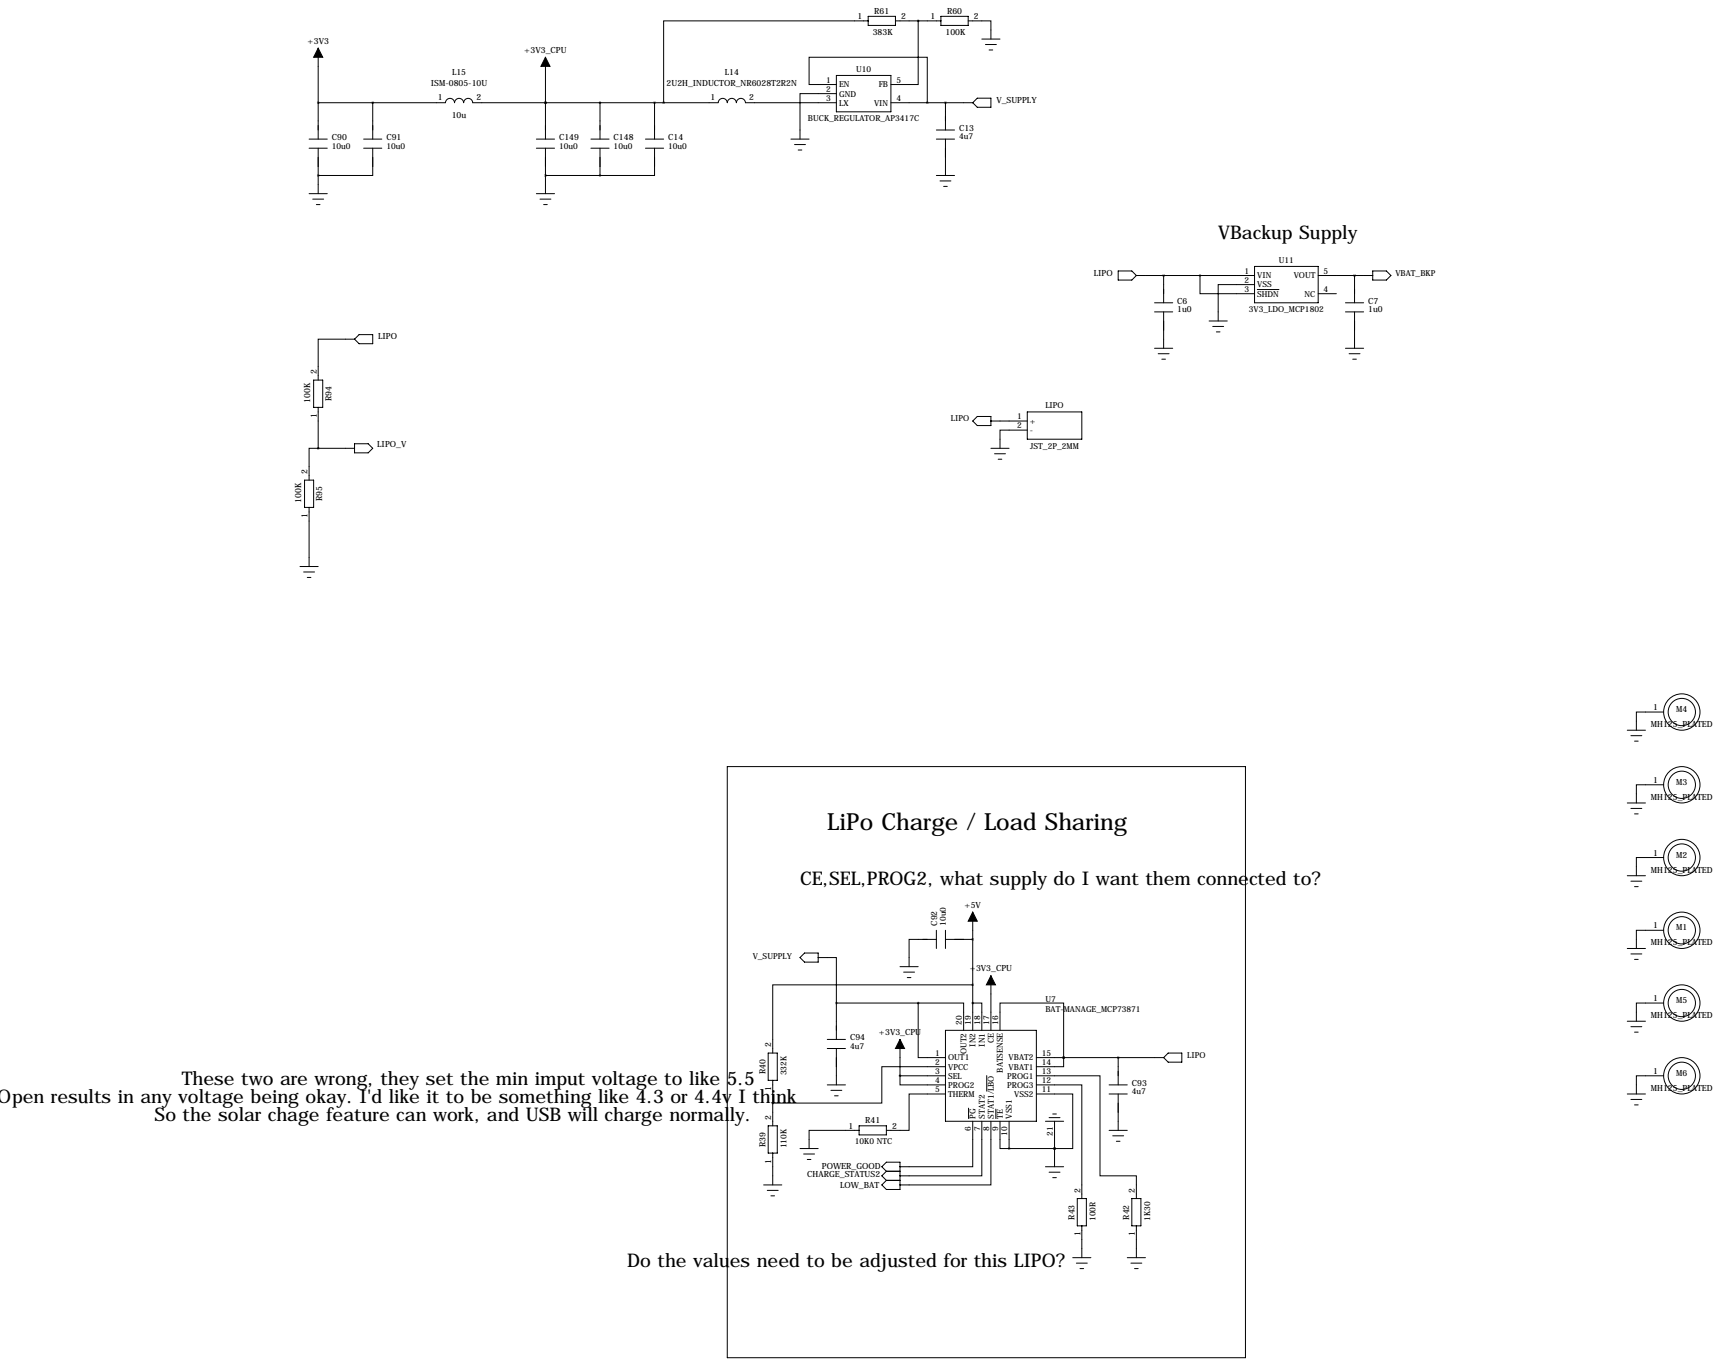
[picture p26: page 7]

LiPo Charge / Load Sharing

CE,SEL,PROG2, what supply do I want them connected to?

R40 = 0R and R39 = Open results in any voltage being okay. I'd like it to be something like 4.3 or 4.4v I think

So the solar chage feature can work, and USB will charge normally.

Do the values need to be adjusted for this LIPO?

# It might make sense to put an inverter rather than run both lines to the micro

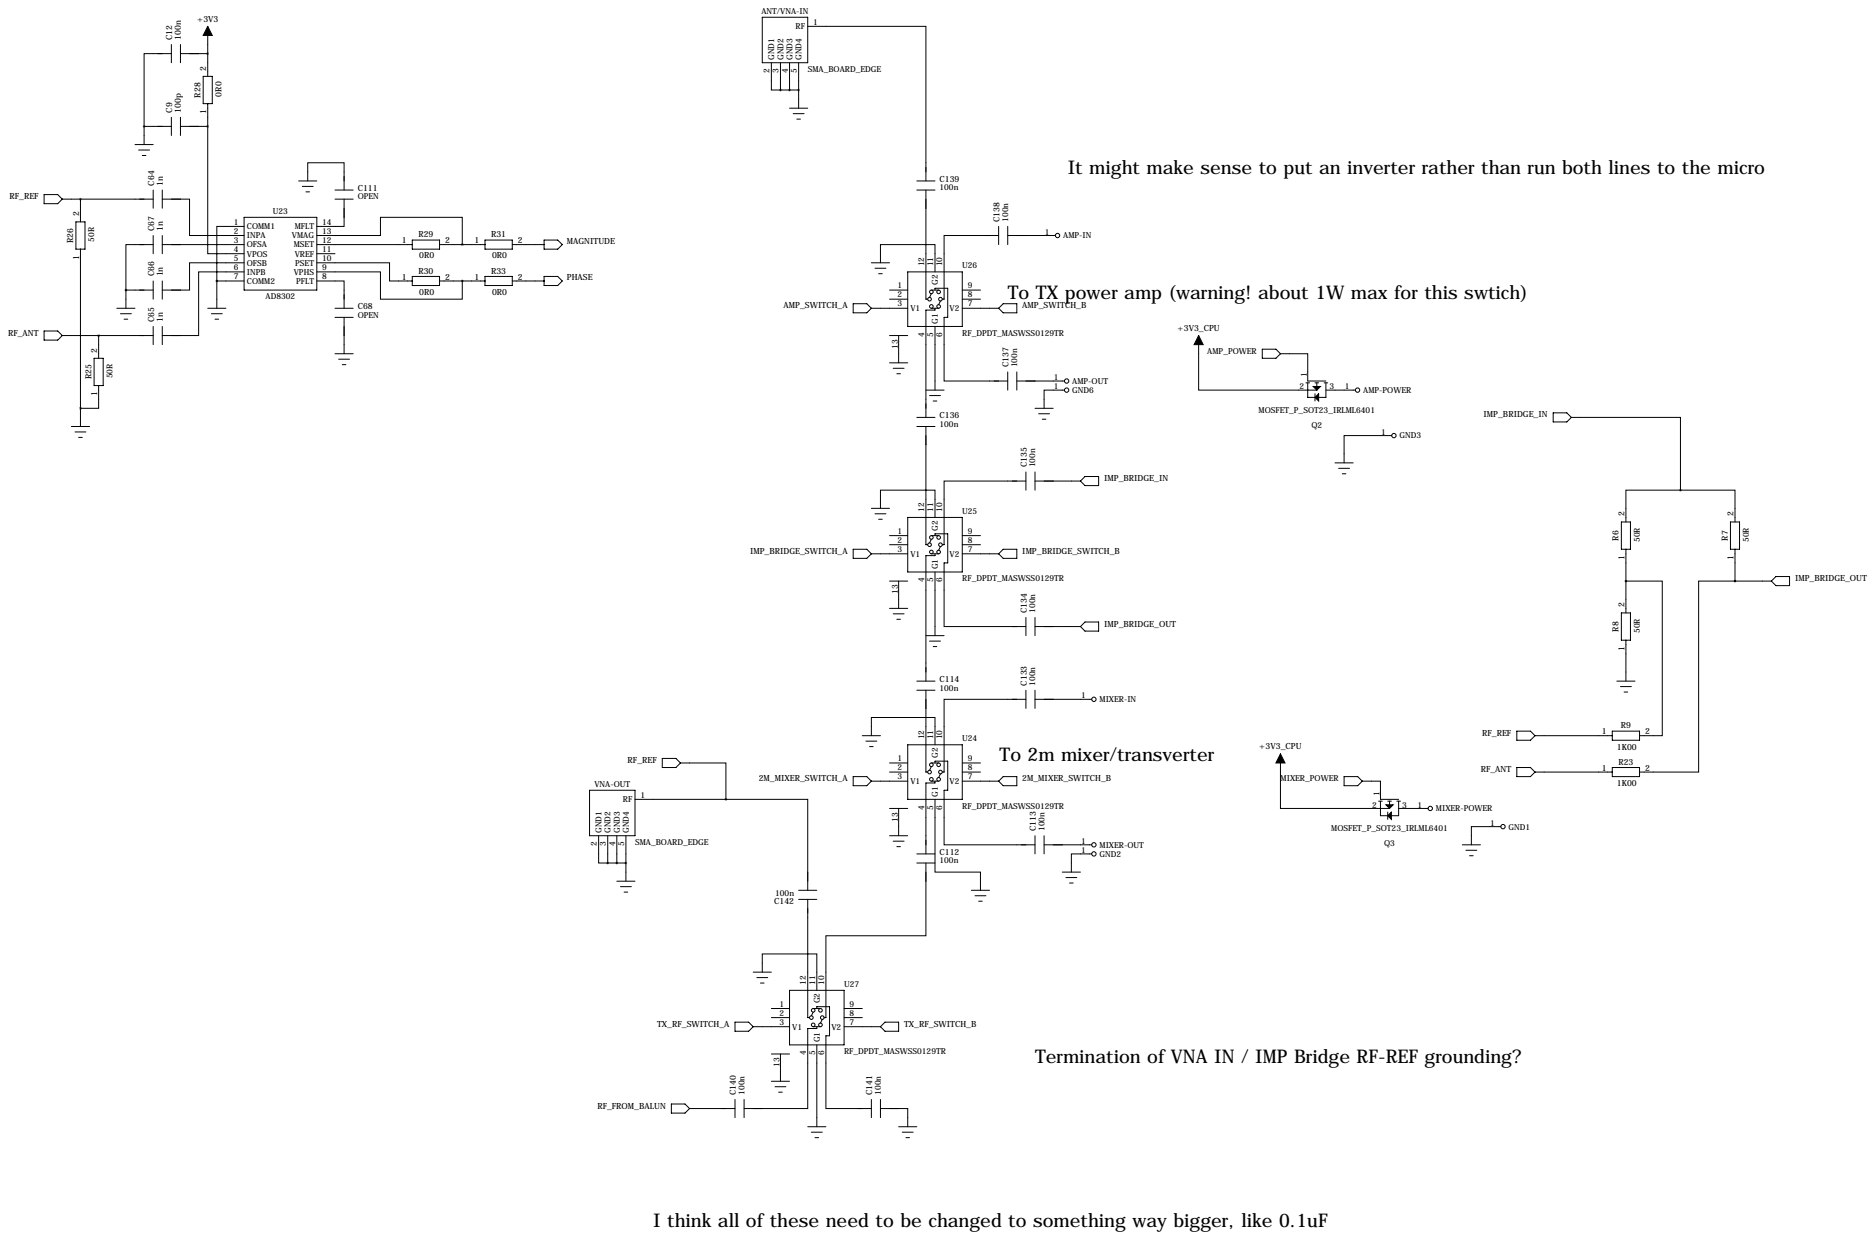
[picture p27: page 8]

INPA 3
OFSA 4

To TX power amp (warning! about 1W max for this swtich)

Termination of VNA IN / IMP Bridge RF-REF grounding?

I think all of these need to be changed to something way bigger, like 0.1uF

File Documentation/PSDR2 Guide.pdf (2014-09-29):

# Vector Network Analyzer

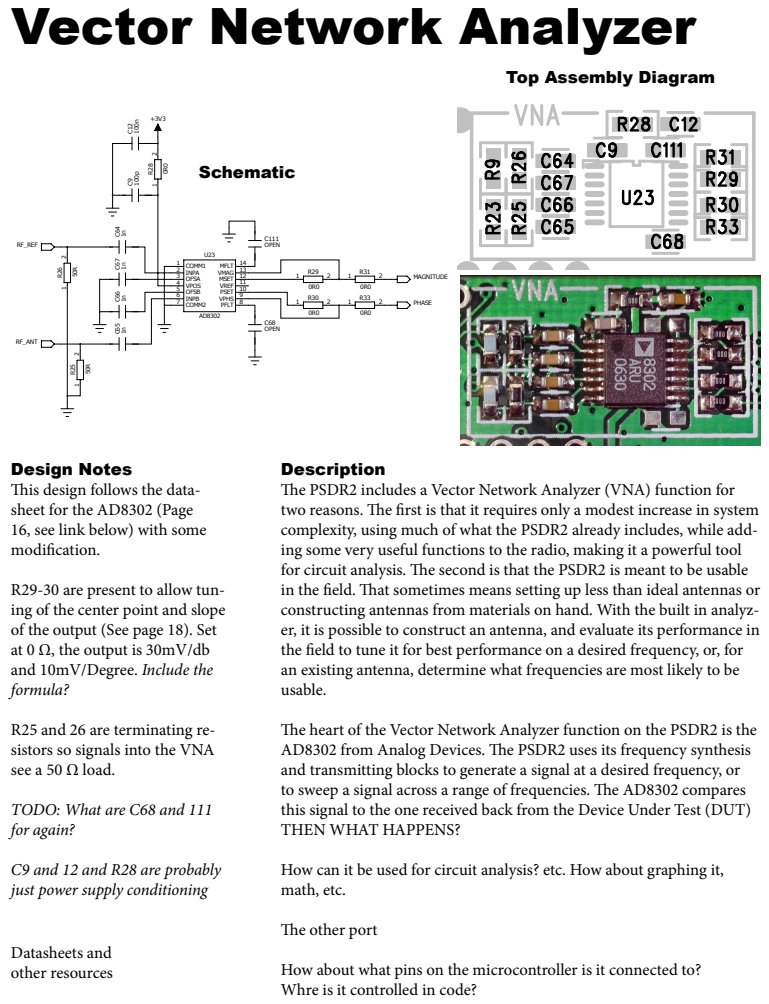
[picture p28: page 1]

1 COMM1 2 INPA 3 OFSA 4 VPOS 5 OFSB 6 INPB 7 COMM2

This design follows the data-
sheet for the AD8302 (Page
16, see link below) with some
modification.
R29-30 are present to allow tun-
ing of the center point and slope
of the output (See page 18). Set
at 0 Ω, the output is 30mV/db
and 10mV/Degree. Include the
formula?
R25 and 26 are terminating re-
sistors so signals into the VNA
see a 50 Ω load.
TODO: What are C68 and 111
for again?
C9 and 12 and R28 are probably
just power supply conditioning

The PSDR2 includes a Vector Network Analyzer (VNA) function for
two reasons. The first is that it requires only a modest increase in system
complexity, using much of what the PSDR2 already includes, while add-
ing some very useful functions to the radio, making it a powerful tool
for circuit analysis. The second is that the PSDR2 is meant to be usable
in the field. That sometimes means setting up less than ideal antennas or
constructing antennas from materials on hand. With the built in analyz-
er, it is possible to construct an antenna, and evaluate its performance in
the field to tune it for best performance on a desired frequency, or, for
an existing antenna, determine what frequencies are most likely to be
usable.
The heart of the Vector Network Analyzer function on the PSDR2 is the
AD8302 from Analog Devices. The PSDR2 uses its frequency synthesis
and transmitting blocks to generate a signal at a desired frequency, or
to sweep a signal across a range of frequencies. The AD8302 compares
this signal to the one received back from the Device Under Test (DUT)
THEN WHAT HAPPENS?
How can it be used for circuit analysis? etc. How about graphing it,
math, etc.
The other port
How about what pins on the microcontroller is it connected to?
Whre is it controlled in code?

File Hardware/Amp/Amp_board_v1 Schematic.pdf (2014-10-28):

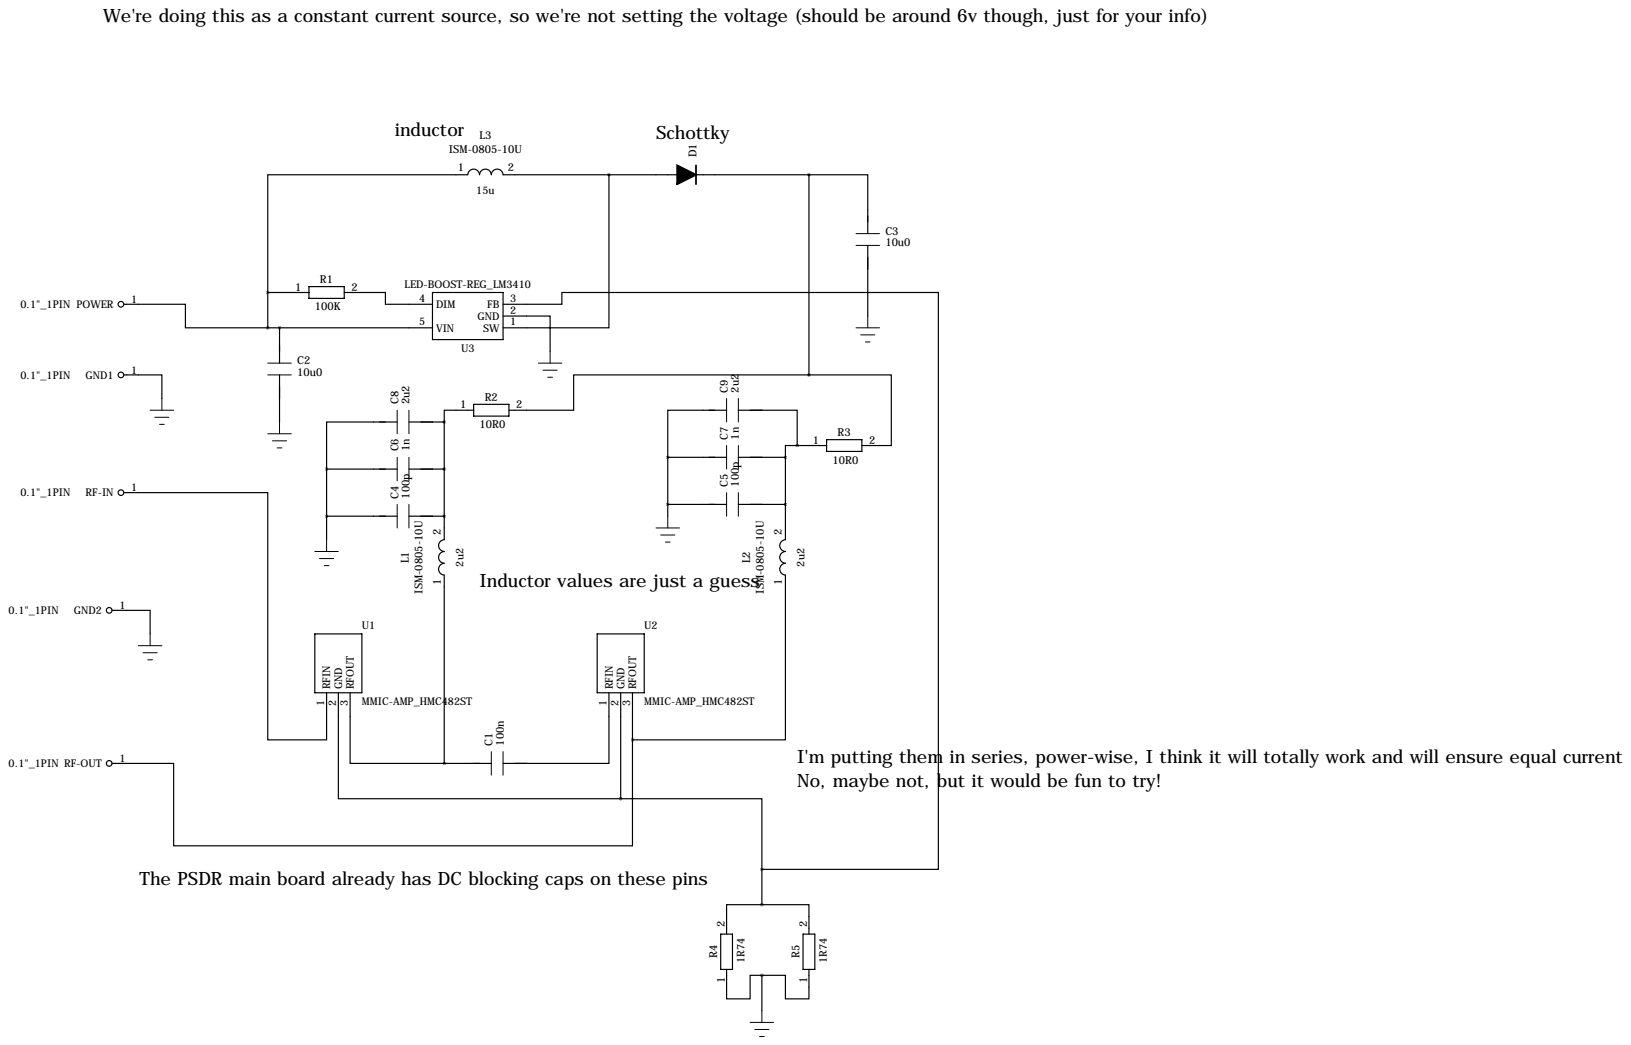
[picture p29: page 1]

We're doing this as a constant current source, so we're not setting the voltage (should be around 6v though, just for your info)

Inductor values are just a guess

I'm putting them in series, power-wise, I think it will totally work and will ensure equal current
No, maybe not, but it would be fun to try!

The PSDR main board already has DC blocking caps on these pins

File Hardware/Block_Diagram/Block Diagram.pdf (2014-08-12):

# User Interface

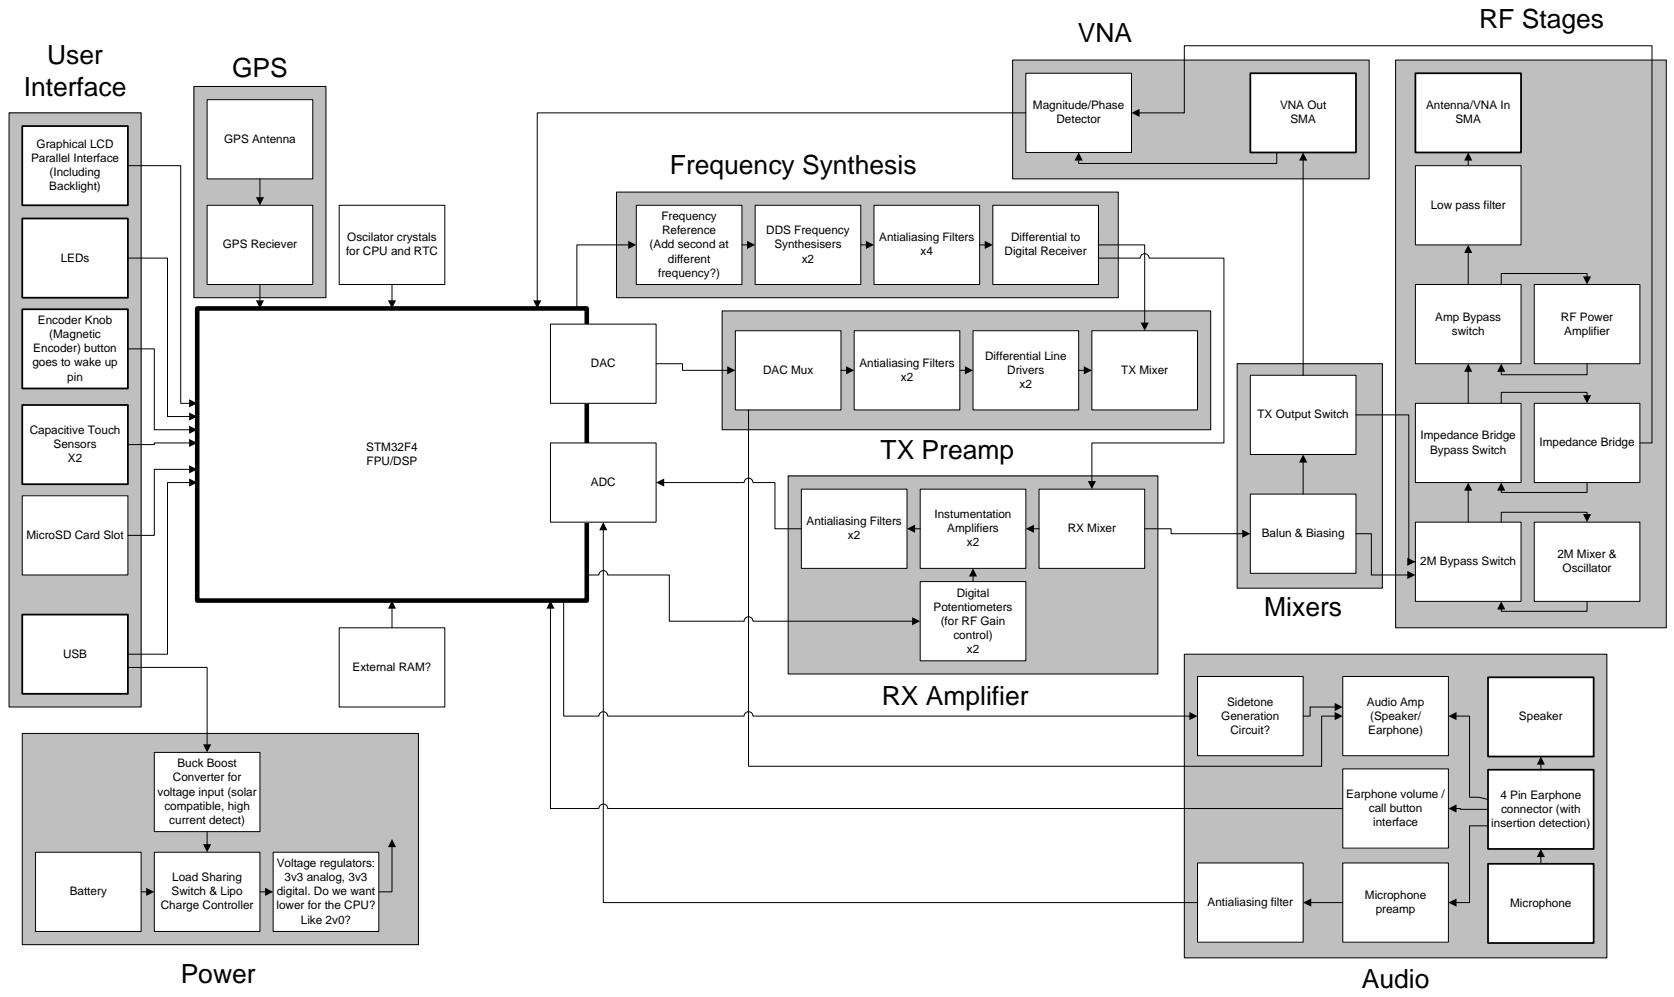
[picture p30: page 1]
STM32F4 FPU/DSP; Backlight); ADC; DAC; Antialiasing Filters x2; pin; USB; DDS Frequency Synthesisers x2; Antialiasing Filters x4; Balun & Biasing; different frequency?); GPS Reciever; GPS Antenna; Battery; VNA Out SMA; Impedance Bridge Bypass Switch; Impedance Bridge; 2M Bypass Switch; 2M Mixer &; Oscillator; LEDs; External RAM?; Capacitive Touch Sensors X2; Antialiasing filter; Microphone preamp; Microphone; DAC Mux; Audio Amp (Speaker/ Earphone); Speaker; insertion detection); GPS; Power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

Magnitude/Phase Detector

Antenna/VNA In SMA

Graphical LCD
Parallel Interface (Including

Low pass filter

Frequency
Reference (Add second at

Oscilator crystals for CPU and RTC

Differential to Digital Receiver

RF Power Amplifier Amp Bypass switch

Encoder Knob
(Magnetic Encoder) button goes to wake up

TX Mixer Differential Line Drivers x2

TX Output Switch

RX Mixer Instumentation Amplifiers x2

MicroSD Card Slot

Digital
Potentiometers (for RF Gain control) x2

Sidetone Generation Circuit?

Buck Boost
Converter for voltage input (solar compatible, high current detect)

Earphone volume / call button interface

4 Pin Earphone connector (with

Voltage regulators: 3v3 analog, 3v3

Load Sharing
Switch & Lipo Charge Controller

digital. Do we want
lower for the CPU?
Like 2v0?

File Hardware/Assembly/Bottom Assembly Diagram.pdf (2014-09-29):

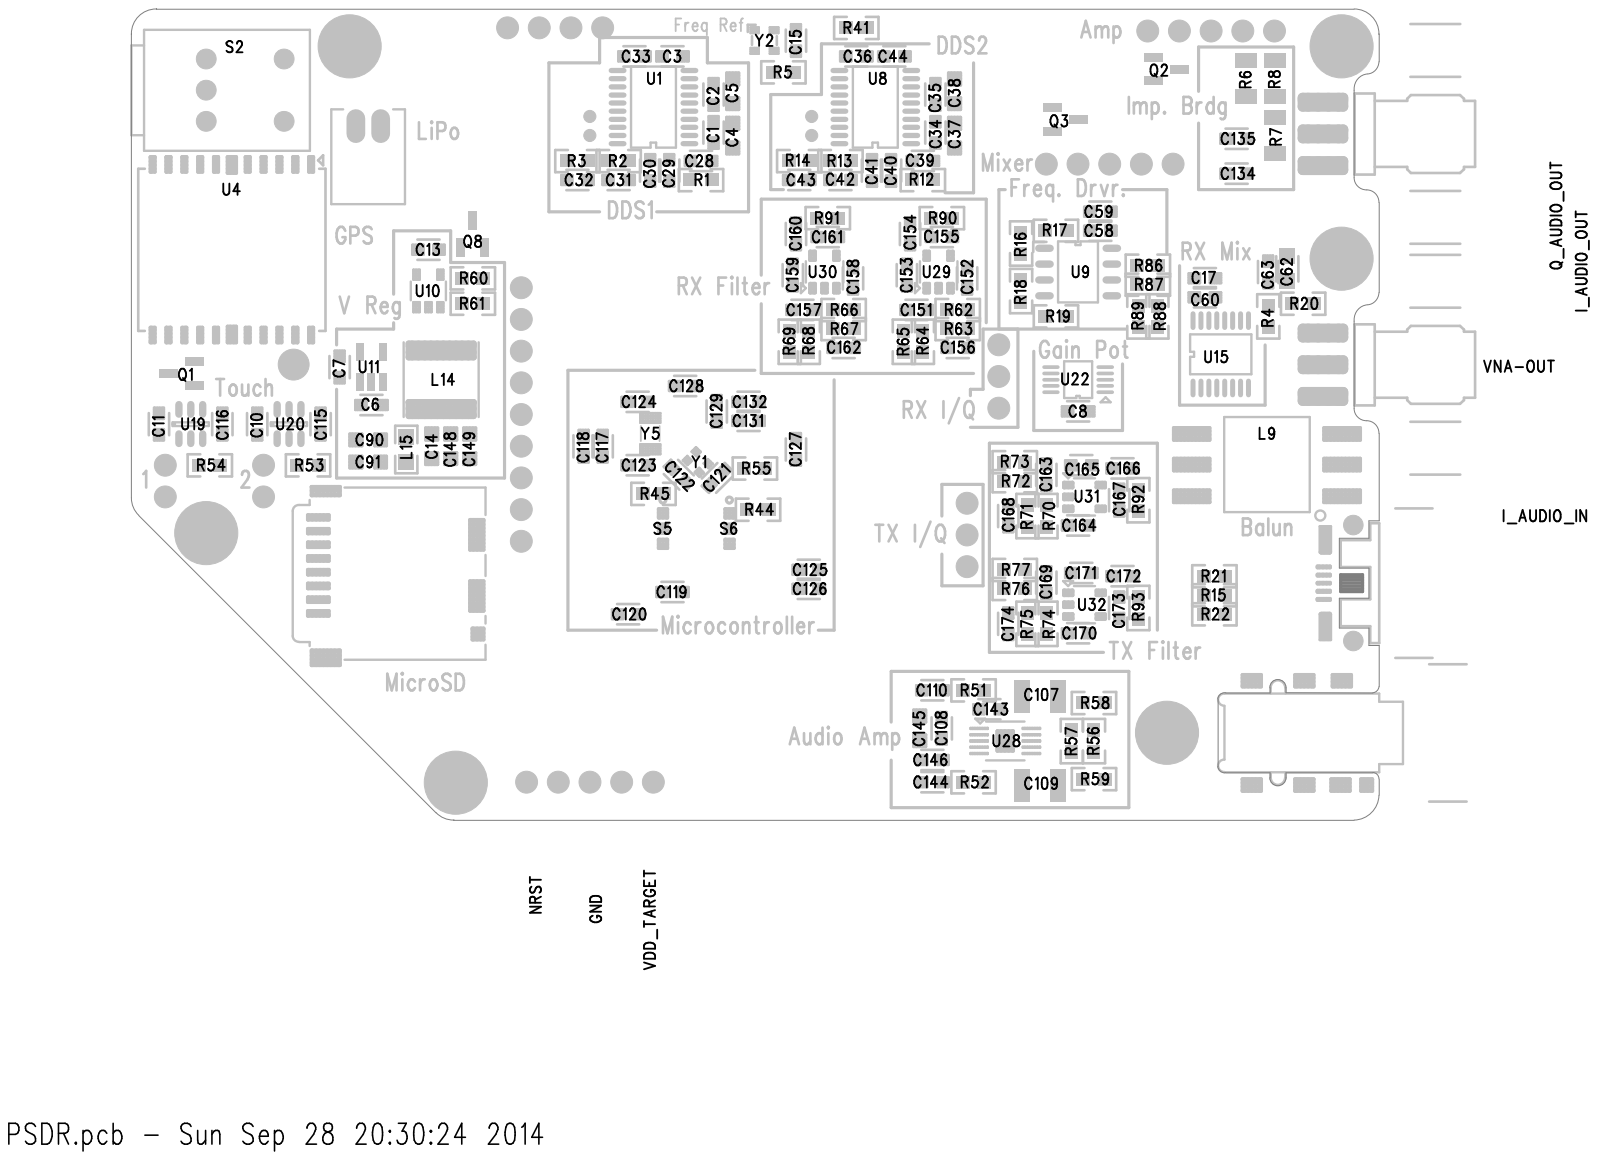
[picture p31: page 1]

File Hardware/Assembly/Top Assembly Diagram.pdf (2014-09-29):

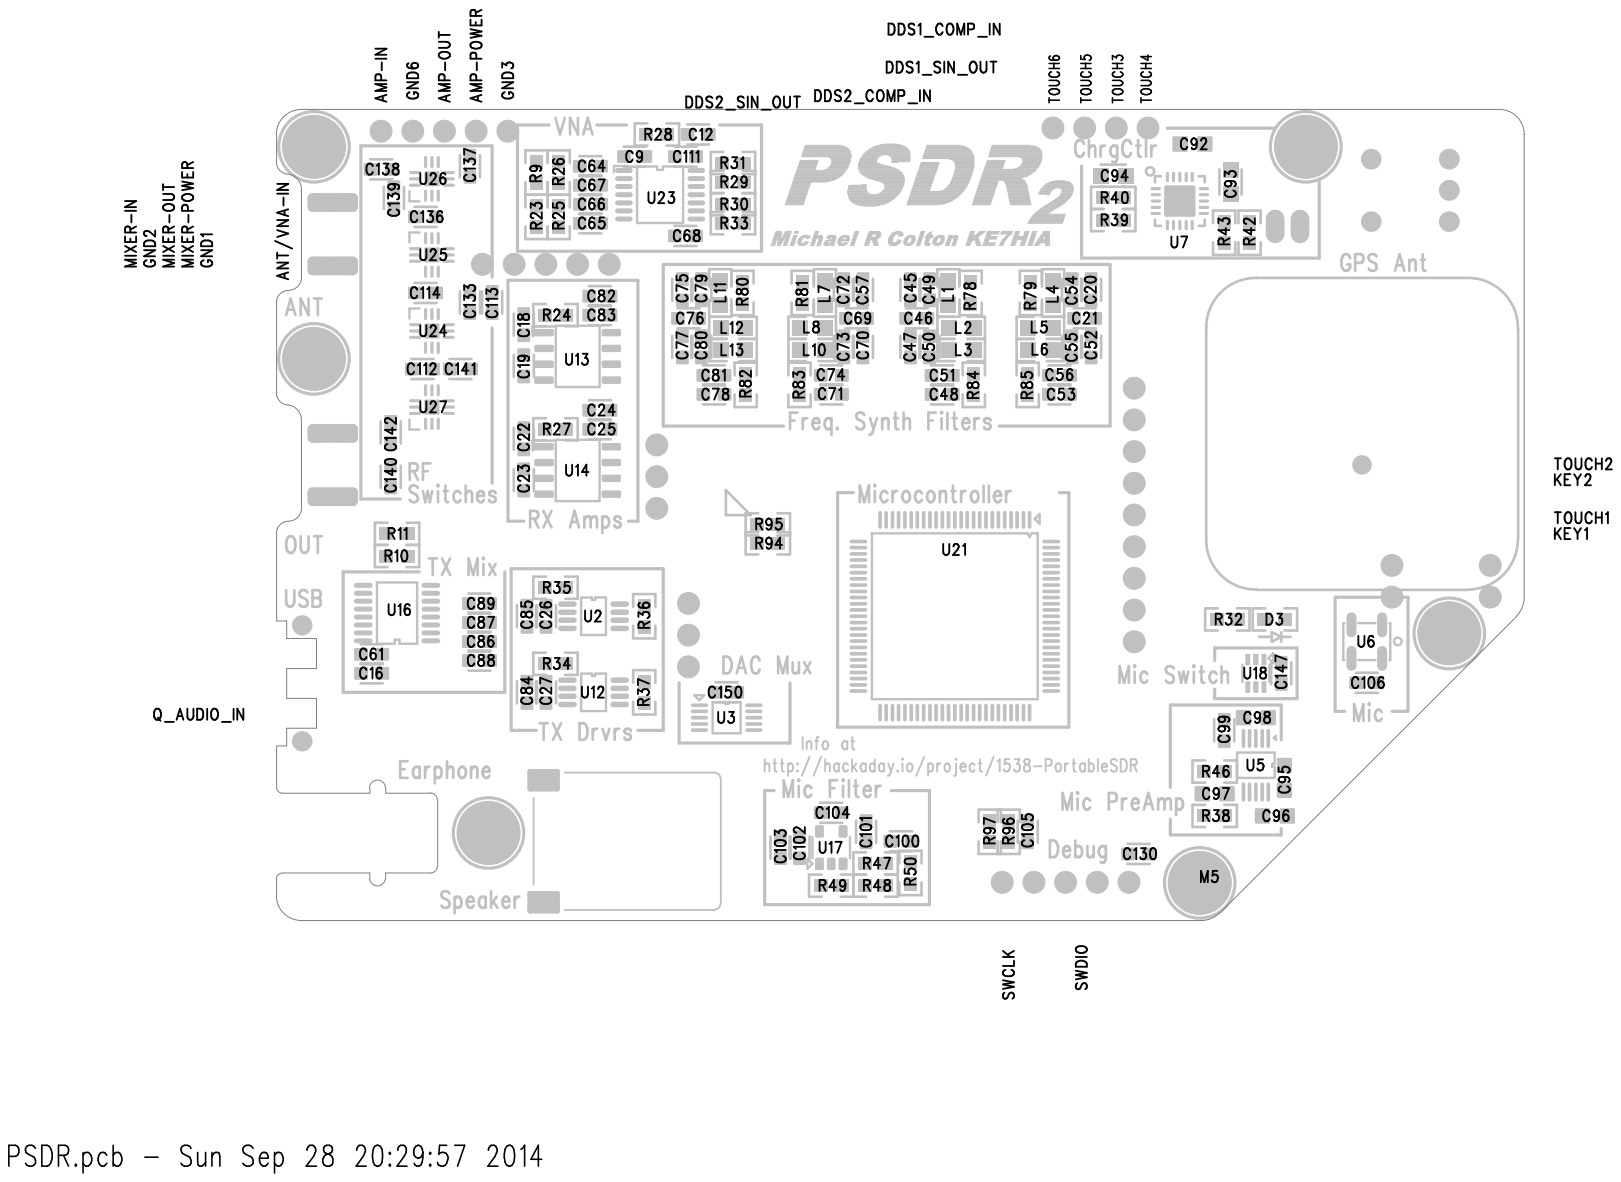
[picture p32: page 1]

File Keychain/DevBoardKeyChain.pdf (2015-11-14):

# Microcontroller

# PortableSDR Keychain


Designed by Michael R Colton

Uses elements of the Maple Mini by Leaf Labs: http://leaflabs.com/about-maple

For more information, please visit PortableSDR.com or github.com/MichaelRColton/PSDR

VIN 2 | 4
VSS 3

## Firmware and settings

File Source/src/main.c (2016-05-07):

//
// This file is part of the GNU ARM Eclipse distribution.
// Copyright (c) 2014 Liviu Ionescu.
//

// ----------------------------------------------------------------------------

//#define ARM_MATH_CM4

#include "main.h"


// ----------------------------------------------------------------------------
//
// Standalone STM32F4 led blink sample (trace via NONE).
//
// In debug configurations, demonstrate how to print a greeting message
// on the trace device. In release configurations the message is
// simply discarded.
//
// Then demonstrates how to blink a led with 1Hz, using a
// continuous loop and SysTick delays.
//
// Trace support is enabled by adding the TRACE macro definition.
// By default the trace messages are forwarded to the NONE output,
// but can be rerouted to any device or completely suppressed, by
// changing the definitions required in system/src/diag/trace_impl.c
// (currently OS_USE_TRACE_ITM, OS_USE_TRACE_SEMIHOSTING_DEBUG/_STDOUT).
//

// ----- Timing definitions -------------------------------------------------

// Keep the LED on for 2/3 of a second.
#define BLINK_ON_TICKS  (TIMER_FREQUENCY_HZ * 2 / 3)
#define BLINK_OFF_TICKS (TIMER_FREQUENCY_HZ - BLINK_ON_TICKS)

// ----- main() ---------------------------------------------------------------

// Sample pragmas to cope with warnings. Please note the related line at
// the end of this function, used to pop the compiler diagnostics status.
#pragma GCC diagnostic push
//#pragma GCC diagnostic ignored "-Wunused-parameter"
//#pragma GCC diagnostic ignored "-Wmissing-declarations"
//#pragma GCC diagnostic ignored "-Wreturn-type"
#pragma GCC diagnostic ignored "-Wfloat-conversion"

void dac1SetValue(uint16_t value);
void dac2SetValue(uint16_t value);
//void ddsPrefix(void);
//void sendToDds(uint16_t data1, uint16_t data2);
#define FFT_SIZE 256 //supported sizes are 16, 64, 256, 1024
#define FFT_BUFFER_SIZE  512 //double the FFT_SIZE above.
__IO long long millis = 0;


float afGain = 1.0;
float afGainLast = 2.0;
float afGainStep = 0.1;
float afGainMax = 25.0;

uint16_t maxAmplitude = 0;

float fftFilterCoeficient[FFT_BUFFER_SIZE];
float filterTemp[FFT_BUFFER_SIZE];
uint16_t filterKernelLength = 100; //what's a good value? How does it relate to the FFT size?

uint16_t menuPos = 0;
uint16_t menuEncoderTicks = 0;
uint16_t menuLastPos = 1;
uint16_t menuCount = 11;
uint32_t frequencyDialMultiplier = 1;

long vfoAFrequency = 6111000;
long vfoALastFreq = 0;
int encoderPos, encoderLastPos;

int16_t filterUpperLimit = 68;
int16_t filterLastUpperLimit = 2;
int16_t filterLowerLimit = 0;
int16_t filterLastLowerLimit = 2;
uint8_t mode = 0;
uint8_t modeLast = 2;

float agcLevel = 0;
float agcScale = 160; //Higher is lower volume.. for now
float txAgcLevel = 0;


int ifShift = 0;

float fftMaxMaxMax = 20;
float fftMaxMaxMin = 0.2;

int transmitting = 0;
unsigned int tone = 0;

uint8_t displayUpdating = 0;

/** System Clock Configuration
*/
void SystemClock_Config(void)
{

  RCC_ClkInitTypeDef RCC_ClkInitStruct;
  RCC_OscInitTypeDef RCC_OscInitStruct;

  __PWR_CLK_ENABLE();

  __HAL_PWR_VOLTAGESCALING_CONFIG(PWR_REGULATOR_VOLTAGE_SCALE1);

  RCC_OscInitStruct.OscillatorType = RCC_OSCILLATORTYPE_HSE;
  RCC_OscInitStruct.HSEState = RCC_HSE_ON;
  RCC_OscInitStruct.PLL.PLLState = RCC_PLL_ON;
  RCC_OscInitStruct.PLL.PLLSource = RCC_PLLSOURCE_HSE;
  RCC_OscInitStruct.PLL.PLLM = 15;
  RCC_OscInitStruct.PLL.PLLN = 210;
  RCC_OscInitStruct.PLL.PLLP = RCC_PLLP_DIV2;
  RCC_OscInitStruct.PLL.PLLQ = 7;
  HAL_RCC_OscConfig(&RCC_OscInitStruct);

  RCC_ClkInitStruct.ClockType = RCC_CLOCKTYPE_SYSCLK|RCC_CLOCKTYPE_PCLK1
                              |RCC_CLOCKTYPE_PCLK2;
  RCC_ClkInitStruct.SYSCLKSource = RCC_SYSCLKSOURCE_PLLCLK;
  RCC_ClkInitStruct.AHBCLKDivider = RCC_SYSCLK_DIV1;
  RCC_ClkInitStruct.APB1CLKDivider = RCC_HCLK_DIV4;
  RCC_ClkInitStruct.APB2CLKDivider = RCC_HCLK_DIV2;
  HAL_RCC_ClockConfig(&RCC_ClkInitStruct, FLASH_LATENCY_5);

}

void polarToRect(float m, float a, float32_t* x, float32_t* y)
{
	*y = m * arm_sin_f32(a);
	*x = m * arm_cos_f32(a);
}

void populateCoeficients(int bandwidth, int sideband, int offset)
{
	//Chapter 17 of DSP Guide* //TODO: Make a bibliography!

	//1. Take as input, desired filter response in array, both magnitude and phase (it's okay for phase to be zero)
	//	 Looks like magnitude can be any non-negative value. First and last values of Phase must be zero.
	//2. Convert to rectangular form. ***I really wish there was a built in function for this :<
	//3. Run through an inverse FFT.
	//4. Shift
	//5. Truncate
	//6. Window
	//7. Reverse the FFT in preparation for FFT Convolution?

	uint16_t filterKernelLength = 100; //what's a good value? How does it relate to the FFT size?

	//1:
	//sideband: 0 = LSB, 1 = USB, 2 = Both (AM)
	//I think the code below is all wrong. At least for LSB, if the magnitude is zero, then phase doesn't matter, yeah?
	if(sideband > 2) return; //Error
	int i;
	for(i = 0; i < FFT_BUFFER_SIZE; i++)
	{
		switch(sideband)
		{
		case 0:
			if((i > FFT_BUFFER_SIZE - (offset + bandwidth)) && (i < FFT_BUFFER_SIZE - offset))
				fftFilterCoeficient[i] = 1;
			else
				fftFilterCoeficient[i] = 0;
			break;
		case 1:
			if((i > offset) && (i < offset + bandwidth))
				fftFilterCoeficient[i] = 1;
			else
				fftFilterCoeficient[i] = 0;
			break;
		case 2:
			if(((i > FFT_BUFFER_SIZE - (offset + bandwidth)) && (i < FFT_BUFFER_SIZE - offset))
					|| ((i > offset) && (i < offset + bandwidth)))
				fftFilterCoeficient[i] = 1;
			else
				fftFilterCoeficient[i] = 0;
			break;
		}
	}
	fftFilterCoeficient[FFT_BUFFER_SIZE / 2] = 0;
	fftFilterCoeficient[FFT_BUFFER_SIZE - 1] = 0;

	return; //Skipping all the later stuff doesn't seem to make a huge difference yet...

	//2:
//	float x, y;
//	for(i = 0; i < FFT_SIZE; i++)
//	{
//		polarToRect(fftFilterCoeficient[i], fftFilterCoeficient[FFT_BUFFER_SIZE - 1 - i], &x, &y);
//		fftFilterCoeficient[i] = x;
//		fftFilterCoeficient[FFT_BUFFER_SIZE - 1 - i] = y;
//	}

	//3:
	arm_cfft_radix4_instance_f32 fft_co;
	arm_cfft_radix4_init_f32(&fft_co, FFT_SIZE, 1, 1);
	arm_cfft_radix4_f32(&fft_co, fftFilterCoeficient);

	//4:
	int index;


	for (i = 0; i < FFT_BUFFER_SIZE; i++)
	{
		index = i + filterKernelLength/2;
		if(index > FFT_BUFFER_SIZE - 1) index = index - FFT_BUFFER_SIZE;
		filterTemp[index] = fftFilterCoeficient[i];
	}

	for(i = 0; i < FFT_BUFFER_SIZE; i++)
	{
		fftFilterCoeficient[i] = filterTemp[i];
	}

	//5 & 6:
	for(i = 0; i < FFT_BUFFER_SIZE; i++)
	{
		if(i <= filterKernelLength) fftFilterCoeficient[i] =
				fftFilterCoeficient[i] * (0.54 - 0.46 * arm_cos_f32(2* 3.14159265*i/filterKernelLength));
		if(i > filterKernelLength) fftFilterCoeficient[i] = 0;
	}

//	arm_cfft_radix4_instance_f32 fft_co;
	arm_cfft_radix4_init_f32(&fft_co, FFT_SIZE, 0, 1);
	arm_cfft_radix4_f32(&fft_co, fftFilterCoeficient);


//	for(i = 0; i < FFT_SIZE; i++)
//	{
//		filterTemp[i] = fftFilterCoeficient[i * 2];
//		filterTemp[FFT_BUFFER_SIZE - 1 - i] = fftFilterCoeficient[i * 2 + 1];
//	}
//
//	for(i = 0; i < FFT_BUFFER_SIZE; i++)
//	{
//		fftFilterCoeficient[i] = filterTemp[i];
//	}
}


void applyCoeficient(float *samples, int shift)
{
	//See DSP Guide Chapter 9 (Equation 9-1)
	int i;
	for(i = 0; i < FFT_SIZE; i++)
	{
		filterTemp[i * 2] = samples[i * 2] * fftFilterCoeficient[i * 2] - samples[i * 2 + 1] * fftFilterCoeficient[i * 2 + 1];
		filterTemp[i * 2 + 1] = samples[i * 2 + 1] * fftFilterCoeficient[i * 2 + 1] + samples[i * 2] * fftFilterCoeficient[i * 2];
	}

	int shifter;
	for(i = 0; i < FFT_BUFFER_SIZE; i++)
	{
		shifter = i + 2 * shift;
		if(i < 0) samples[i] = 0;
		if(i > FFT_BUFFER_SIZE - 1) samples[i] = 0;
		samples[i] = filterTemp[i + 2 * shift];
	}
}


void setupPeripheralPower()
{
	__GPIOA_CLK_ENABLE();
	__GPIOB_CLK_ENABLE();
	__GPIOC_CLK_ENABLE();
	__GPIOD_CLK_ENABLE();
	__GPIOE_CLK_ENABLE();
	__DMA1_CLK_ENABLE();
	__DMA2_CLK_ENABLE();
	__I2C2_CLK_ENABLE();
}

void configDMA(SPI_HandleTypeDef *hspi)
{
//	  static DMA_HandleTypeDef hdma_tx;
//	  static DMA_HandleTypeDef hdma_rx;
//
//
//	hdma_tx.Instance                 = SPIx_TX_DMA_STREAM;
//
//	  hdma_tx.Init.Channel             = SPIx_TX_DMA_CHANNEL;
//	  hdma_tx.Init.Direction           = DMA_MEMORY_TO_PERIPH;
//	  hdma_tx.Init.PeriphInc           = DMA_PINC_DISABLE;
//	  hdma_tx.Init.MemInc              = DMA_MINC_ENABLE;
//	  hdma_tx.Init.PeriphDataAlignment = DMA_PDATAALIGN_BYTE;
//	  hdma_tx.Init.MemDataAlignment    = DMA_MDATAALIGN_BYTE;
//	  hdma_tx.Init.Mode                = DMA_NORMAL;
//	  hdma_tx.Init.Priority            = DMA_PRIORITY_LOW;
//	  hdma_tx.Init.FIFOMode            = DMA_FIFOMODE_DISABLE;
//	  hdma_tx.Init.FIFOThreshold       = DMA_FIFO_THRESHOLD_FULL;
//	  hdma_tx.Init.MemBurst            = DMA_MBURST_INC4;
//	  hdma_tx.Init.PeriphBurst         = DMA_PBURST_INC4;
//
//	  HAL_DMA_Init(&hdma_tx);
//
//	  /* Associate the initialized DMA handle to the the SPI handle */
//	  __HAL_LINKDMA(hspi, hdmatx, hdma_tx);
//
//	  /* Configure the DMA handler for Transmission process */
//	  hdma_rx.Instance                 = SPIx_RX_DMA_STREAM;
//
//	  hdma_rx.Init.Channel             = SPIx_RX_DMA_CHANNEL;
//	  hdma_rx.Init.Direction           = DMA_PERIPH_TO_MEMORY;
//	  hdma_rx.Init.PeriphInc           = DMA_PINC_DISABLE;
//	  hdma_rx.Init.MemInc              = DMA_MINC_ENABLE;
//	  hdma_rx.Init.PeriphDataAlignment = DMA_PDATAALIGN_BYTE;
//	  hdma_rx.Init.MemDataAlignment    = DMA_MDATAALIGN_BYTE;
//	  hdma_rx.Init.Mode                = DMA_NORMAL;
//	  hdma_rx.Init.Priority            = DMA_PRIORITY_HIGH;
//	  hdma_rx.Init.FIFOMode            = DMA_FIFOMODE_DISABLE;
//	  hdma_rx.Init.FIFOThreshold       = DMA_FIFO_THRESHOLD_FULL;
//	  hdma_rx.Init.MemBurst            = DMA_MBURST_INC4;
//	  hdma_rx.Init.PeriphBurst         = DMA_PBURST_INC4;
//
//	  HAL_DMA_Init(&hdma_rx);
//
//	  /* Associate the initialized DMA handle to the the SPI handle */
//	  __HAL_LINKDMA(hspi, hdmarx, hdma_rx);
//
//	  /*##-4- Configure the NVIC for DMA #########################################*/
//	  /* NVIC configuration for DMA transfer complete interrupt (SPI3_TX) */
//	  HAL_NVIC_SetPriority(15/*SPIx_DMA_TX_IRQn*/, 0, 1);
//	  HAL_NVIC_EnableIRQ(SPIx_DMA_TX_IRQn);
//
//	  /* NVIC configuration for DMA transfer complete interrupt (SPI3_RX) */
//	  HAL_NVIC_SetPriority(SPIx_DMA_RX_IRQn, 0, 0);
//	  HAL_NVIC_EnableIRQ(SPIx_DMA_RX_IRQn);
//
//
//	  //HAL_DMA_Start();
}



void doNothing()
{
	static int cap = 0;
	cap++;
}

void
SysTick_Handler (void)
{
	millis++;
  timer_tick ();
  Tick();
  if(timingDelay > 0) timingDelay--;
}

int clickMultiply;
int Max;
int Min;
int Pos;
int Position;
int Position2;
int isFwd;

#define EncoderPinA 20	// Rotary Encoder Left Pin //
#define EncoderPinB 19	// Rotary Encoder Right Pin //
#define EncoderPinP 21	// Rotary Encoder Click //


	Encoder()
	{
		Position = 0;
		Position2 = 0;
		Max = 127;
		Min = 0;
		clickMultiply = 100;
	}

	void Tick(void)
	{
		if(!displayUpdating)
		{
			Position2 = (HAL_GPIO_ReadPin(encoderB.port, encoderB.pin) * 2) + HAL_GPIO_ReadPin(encoderBee.port, encoderBee.pin);;
			if (Position2 != Position)
			{
				isFwd = ((Position == 0) && (Position2 == 1)) || ((Position == 1) && (Position2 == 3)) ||
					((Position == 3) && (Position2 == 2)) || ((Position == 2) && (Position2 == 0));
				if (!HAL_GPIO_ReadPin(encoderP.port, encoderP.pin))
				{
					if (isFwd)
						menuEncoderTicks += 1;
					else
						menuEncoderTicks -= 1;
					menuPos = menuEncoderTicks/2;
					menuPos = menuPos % menuCount;
				}
				else
				{
					if (isFwd) Pos++;
					else Pos--;
				}
				//if (Pos < Min) Pos = Min;
				//if (Pos > Max) Pos = Max;
			}
			Position = Position2;
		}
	}

	int getPos(void)
	{
		return (Pos/2);
	}
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
int
main(int argc, char* argv[])
{

	HAL_Init();

	SystemClock_Config();

	//HAL_RCC_OscConfig()
	//	RCC_ClkInitStruct clockInitStructure;
	//	clockInitStructure.
	//	HAL_RCC_ClockConfig()
	//	SystemClock_Config();

	//	void (*systicker)();
	//	systicker = &doNothing();
	//
	//
	//	HAL_SYSTICK_Callback(systicker);
	//hal_setSysTickCallback(doNothing());

	// Send a greeting to the trace device (skipped on Release).
	trace_puts("Hello ARM World!");
	trace_puts("Sweet, this works now!");

//	for(int i; i > 1000; i++)
//	{
//		trace_printf("%f = %f\n", (float)i, log((double)i));
//	}


	// At this stage the system clock should have already been configured
	// at high speed.
	trace_printf("System clock: %uHz\n", SystemCoreClock);

	setupPeripheralPower();

	//initDdsPins();
	hal_setupPins();
	spi_init();

	configDMA(&SpiHandle );


//I2C_HandleTypeDef hi2c;
//HAL_I2C_MspInit(&hi2c);

//__HAL_I2C_DISABLE(I2C2);
clearStuckBusyFlag();

handleI2C.Instance = I2C2;
HAL_I2C_DeInit(&handleI2C);

handleI2C.Init.AddressingMode = I2C_ADDRESSINGMODE_7BIT;
handleI2C.Init.ClockSpeed = 400000;
handleI2C.Init.DualAddressMode = I2C_DUALADDRESS_DISABLED;
handleI2C.Init.DutyCycle = I2C_DUTYCYCLE_16_9;
handleI2C.Init.GeneralCallMode = I2C_GENERALCALL_DISABLED;
handleI2C.Init.NoStretchMode = I2C_NOSTRETCH_DISABLED;
handleI2C.Init.OwnAddress1 = 0x30F;
handleI2C.Init.OwnAddress2 = 0xFE;


if(HAL_I2C_Init(&handleI2C) != HAL_OK)
  {
    trace_puts("I2C didn't Init correctly");

  }
//handleI2C.Instance->SR2 = 0; //What the heck is wrong with this thing?!
//clearStuckBusyFlag();

HAL_StatusTypeDef result = HAL_ERROR;

while(result!= HAL_OK)
  result = HAL_I2C_IsDeviceReady(&handleI2C, (0x70 << 1), 100, 100); //We need to shift the address to the left for it to work (because of the R/W bit)

//HAL_I2C_Master_Transmit(&hi2c, 230, 0x10, 1, 1000);  //write_Si5338(230, 0x10); //OEB_ALL = 1

//*handleI2C = hi2c;

//HAL_I2C_Master_Transmit(&handleI2C, 230, 0x4F, 1, 1000);  //write_Si5338(230, 0x10); //OEB_ALL = 1
//HAL_I2C_Master_Transmit(handleI2C, 230, 0x4F, 1, 1000);  //write_Si5338(230, 0x10); //OEB_ALL = 1
//handleI2C = &hi2c;
//HAL_I2C_Master_Transmit(&handleI2C, 230, 0x4F, 1, 1000);  //write_Si5338(230, 0x10); //OEB_ALL = 1
//HAL_I2C_Master_Transmit(handleI2C, 230, 0x4F, 1, 1000);  //write_Si5338(230, 0x10); //OEB_ALL = 1

i2cSetup();
//i2cLoop();


//trace_puts(( == HAL_OK ? "SI5338 Ready" : "SI5338 Not ready"));

//HAL_I2C_MspInit(&hi2c);



	timer_start();

	blink_led_init();
	blink_led_on();

	populateCoeficients(filterUpperLimit - filterLowerLimit, mode, filterLowerLimit);

	initDac1();
	Encoder();

	Adafruit_ILI9340_begin();
	Adafruit_ILI9340_setRotation(1);
	//Adafruit_GFX_fillScreen(ILI9340_BLACK);
	Adafruit_GFX_fillScreen(ILI9340_BLACK);

	Adafruit_GFX_setTextSize(3);
	Adafruit_GFX_setTextWrap(1);
	Adafruit_GFX_setTextColor(ILI9340_WHITE, ILI9340_BLACK);
	Adafruit_ILI9340_setVerticalScrollDefinition(0,120,200);

	initAdc();
	adcConfigured = 1;
	adcStartConversion();

	//TIM_setup();
	//TIM_Config();
	TIM_Try();

	long long timeMeasurement = 0;

	updateDisplay(1);



	setGainPot(250, 250);

	//testing Uart
	configUartPeripheral();
//	while(1)
//	{
//	      //HAL_UART_Transmit_IT(&UartHandle, (uint8_t*)aTxBuffer, 16);
//
//		hal_delay_ms(100);
//	}

	//MAIN LOOP - Lowest Priority
	while(1)
	{
		//TODO: Should I shift away from 0Hz? to get away from 1/f noise? It didn's LOOK bad, but maybe it is negatively effecting things.
		//I could do something where the dial moves around on screen, but if you get too close to the edge, the DDSs start moving the frequency
		//Hmm, I think that's kind of a cool idea. It would be cool in two ways: it would allow you to shift the IF so you could get away from
		//birdies, and it would mean that while tuning around locally, the waterfall would stay aligned in a useful way. Eventually, when I have
		//sufficient display performance, I'd like to move (and scale, if applicable) the waterfall so it is properly aligned.

		//Speaking of 1/f noise. It doesn't seem to be much of an issue on this radio, I wonder why? Did I design something right?
			//Update: Not sure that the 1/f noise is as small an issue as I thought. It popped up when I was out in the field.
			//Maybe the 1/f noise is masked by all the noise in my neighborhood?
		//Also, early on, I thought it had an issue with microphonics, but it turned out that it was the connection to the computer.
		//Also since this is a form of direct conversion receiver (two of them together) I was worried about AM broadcast interference
		//but I haven't noticed any, again, maybe I did something right? Beginner's luck?

		HAL_UART_Receive_IT(&UartHandle, (uint8_t*)aRxBuffer, 16);

		int* p = UartHandle.pRxBuffPtr;
		int* q = &aRxBuffer;
		int difference = p- q;


		updateMenu();
		updateDisplay(0);
		drawWaterfall();
		drawSMeter();

		Adafruit_GFX_fillRect(310, 0, 3, 3, HAL_GPIO_ReadPin(PADDLE_THUMB_NC.port, PADDLE_THUMB_NC.pin) ? ILI9340_RED : ILI9340_BLUE);
		Adafruit_GFX_fillRect(310, 4, 3, 3, HAL_GPIO_ReadPin(PADDLE_INDEX_NC.port, PADDLE_INDEX_NC.pin) ? ILI9340_RED : ILI9340_BLUE);
		Adafruit_GFX_fillRect(310, 8, 3, 3, HAL_GPIO_ReadPin(PADDLE_THUMB_NO.port, PADDLE_THUMB_NO.pin) ? ILI9340_RED : ILI9340_BLUE);
		Adafruit_GFX_fillRect(310, 12, 3, 3, HAL_GPIO_ReadPin(PADDLE_INDEX_NO.port, PADDLE_INDEX_NO.pin) ? ILI9340_RED : ILI9340_BLUE);

		HAL_GPIO_WritePin(RED_LED.port, RED_LED.pin, HAL_GPIO_ReadPin(GPS_PPS.port, GPS_PPS.pin));

		if(!HAL_GPIO_ReadPin(PADDLE_THUMB_NO.port, PADDLE_THUMB_NO.pin))
		//if(1) //I am locking it in transmit for some testing.
		{
			transmitting = 1;
	        HAL_GPIO_WritePin(DAC_MUX.port, DAC_MUX.pin, 1); //0 = speaker/earphone. 1=TX Drivers
//	        HAL_GPIO_WritePin(RX_MUX.port, RX_MUX.pin, 1); //Active Low
//	        HAL_GPIO_WritePin(TX_MUX.port, TX_MUX.pin, 0); //Active Low
	        HAL_GPIO_WritePin(AMP_SWITCH_A.port, AMP_SWITCH_A.pin, 1); //Route through amp.
	        HAL_GPIO_WritePin(AMP_SWITCH_B.port, AMP_SWITCH_B.pin, 0); //always reverse of above.
	        HAL_GPIO_WritePin(AMP_POWER.port, AMP_POWER.pin, 0); //0 is on.
	        tone = 200;
		} else {
			transmitting = 0;
	        HAL_GPIO_WritePin(DAC_MUX.port, DAC_MUX.pin, 0); //0 = speaker/earphone. 1=TX Drivers
//	        HAL_GPIO_WritePin(RX_MUX.port, RX_MUX.pin, 0); //Active Low
//	        HAL_GPIO_WritePin(TX_MUX.port, TX_MUX.pin, 1); //Active Low
	        HAL_GPIO_WritePin(AMP_SWITCH_A.port, AMP_SWITCH_A.pin, 0); //Bypass amp.
	        HAL_GPIO_WritePin(AMP_SWITCH_B.port, AMP_SWITCH_B.pin, 1); //always reverse of above.
	        HAL_GPIO_WritePin(AMP_POWER.port, AMP_POWER.pin, 1); //1 is off.
	        tone = 0;
		}
	}
}

float passBandRms = 0;
int lastSMeterBarWidth = 0;
void drawSMeter()
{

	//Adafruit_GFX_fillRect(150, 160, 170, 3, ILI9340_BLACK);
	int width = 10*log((passBandRms * 1000000) + 1);
	if(width > lastSMeterBarWidth)
		Adafruit_GFX_fillRect(150 + lastSMeterBarWidth, 156, width - lastSMeterBarWidth, 3, ILI9340_RED);
	else
		Adafruit_GFX_fillRect(150 + width, 156, lastSMeterBarWidth - width, 3, ILI9340_BLACK);

	lastSMeterBarWidth = width;
}

enum menuItems
{
  volumeMenuItem = 0,
  modeMenuItem,
  megahertzMenuItem,
  hundredKilohertzMenuItem,
  tenKilohertzMenuItem,
  kilohertzMenuItem,
  hundredHertzMenuItem,
  tenHertzMenuItem,
  hertzMenuItem,
  filterLowMenuItem,
  filterHighMenuItem
};

//enum menuItems
//{
//  oneMhzPlace = 0,
//  hundredKhzPlace = 1,
//  tenKhzPlace = 2,
//  oneKhzPlace = 3,
//  hundredHzPlace = 4,
//  tenHzPlace = 5,
//  oneHzPlace = 6,
//  filterLower = 7,
//  filterUpper = 8,
//  modeMenu = 9,
//  volumeMenu = 10,
//};
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

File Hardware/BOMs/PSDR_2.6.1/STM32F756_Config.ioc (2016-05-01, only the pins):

Mcu.UserName=STM32F756VGTx
PA0/WKUP.GPIO_Label=AMP_SWITCH_A
PA0/WKUP.Signal=GPIO_Output
PA1.GPIO_Label=BOOT1
PA1.Signal=GPIO_Input
PA10.Signal=USB_OTG_FS_ID
PA11.Signal=USB_OTG_FS_DM
PA12.Signal=USB_OTG_FS_DP
PA13.Signal=SYS_JTMS-SWDIO
PA14.Signal=SYS_JTCK-SWCLK
PA2.GPIO_Label=RX-Q_FILTERED
PA2.Signal=ADCx_IN2
PA3.GPIO_Label=RX-I_FILTERED
PA3.Signal=ADCx_IN3
PA4.GPIO_Label=DAC1
PA4.Signal=COMP_DAC1_group
PA5.GPIO_Label=DAC2
PA5.Signal=COMP_DAC2_group
PA6.Signal=GPIO_Output
PA7.GPIO_Label=IMP_BRIDGE_SWITCH_B
PA7.Signal=GPIO_Output
PB0.GPIO_Label=MAGNITUDE
PB0.Signal=ADCx_IN8
PB1.GPIO_Label=MIC_FILTERED
PB1.Signal=ADCx_IN9
PB10.Signal=I2C2_SCL
PB11.Signal=I2C2_SDA
PB12.GPIO_Label=FILTER_CS
PB12.Signal=SPI2_NSS
PB13.GPIO_Label=FILTER/GAIN_POT_CLK
PB13.Signal=SPI2_SCK
PB14.GPIO_Label=FILTER_MISO
PB14.Signal=SPI2_MISO
PB15.GPIO_Label=FILTER/GAIN_POT_MOSI
PB15.Signal=SPI2_MOSI
PB2.GPIO_Label=TX_RF_SWITCH_A
PB2.Signal=GPIO_Output
PB3.Signal=SYS_JTDO-SWO
PC0.Signal=ADCx_IN10
PC1.GPIO_Label=IMP_BRIDGE_SWITCH_A
PC1.Signal=GPIO_Output
PC13.GPIO_Label=LCD_LED
PC13.Signal=GPIO_Output
PC14/OSC32_IN.Signal=RCC_OSC32_IN
PC15/OSC32_OUT.Signal=RCC_OSC32_OUT
PC2.GPIO_Label=INAMP_ENABLE
PC2.Signal=GPIO_Output
PC3.GPIO_Label=TRX_SWITCH
PC3.Signal=GPIO_Output
PC4.GPIO_Label=HALF_VCC
PC4.Signal=ADCx_IN14
PC5.GPIO_Label=PHASE
PC5.Signal=ADCx_IN15
PD8.GPIO_Label=FILTER_S1
PD8.Signal=GPIO_Output
PE10.GPIO_Label=FILTER_S0
PE10.Signal=GPIO_Output
PE11.GPIO_Label=LPF_POWER
PE11.Signal=GPIO_Output
PE12.GPIO_Label=LED_WHITE
PE12.Signal=GPIO_Output
PE13.GPIO_Label=LED_RED
PE13.Signal=GPIO_Output
PE14.GPIO_Label=AUDIO_AMP_SHDN
PE14.Signal=GPIO_Output
PE15.GPIO_Label=GPS_RESET
PE15.Signal=GPIO_Output
PE2.GPIO_Label=5V_REG_ENABLE
PE2.Signal=GPIO_Output
PE3.GPIO_Label=AMP_POWER
PE3.Signal=GPIO_Output
PE4.GPIO_Label=DAC_MUX
PE4.Signal=GPIO_Output
PE6.GPIO_Label=AMP_SWITCH_B
PE6.Signal=GPIO_Output
PE7.GPIO_Label=GPS_PPS
PE7.Signal=S_TIM1_ETR
PE8.GPIO_Label=FLIP_FLOP_POWER
PE8.Signal=GPIO_Output
PE9.GPIO_Label=F_SYNTH_CAL
PE9.Signal=S_TIM1_CH1
PH0/OSC_IN.Signal=RCC_OSC_IN
PH1/OSC_OUT.Signal=RCC_OSC_OUT

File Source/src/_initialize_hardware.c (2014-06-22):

//
// This file is part of the µOS++ III distribution.
// Copyright (c) 2014 Liviu Ionescu.
//

// ----------------------------------------------------------------------------

#include "stm32f4xx.h"
#include "stm32f4xx_hal.h"
#include "stm32f4xx_hal_cortex.h"

// ----------------------------------------------------------------------------

// The external clock frequency is specified as a preprocessor definition
// passed to the compiler via a command line option (see the 'C/C++ General' ->
// 'Paths and Symbols' -> the 'Symbols' tab, if you want to change it).
// The value selected during project creation was HSE_VALUE=8000000.
//
// The code to set the clock is at the end.
//
// Note1: The default clock settings assume that the HSE_VALUE is a multiple
// of 1MHz, and try to reach the maximum speed available for the
// board. It does NOT guarantee that the required USB clock of 48MHz is
// available. If you need this, please update the settings of PLL_M, PLL_N,
// PLL_P, PLL_Q to match your needs.
//
// Note2: The external memory controllers are not enabled. If needed, you
// have to define DATA_IN_ExtSRAM or DATA_IN_ExtSDRAM and to configure
// the memory banks in system/src/cmsis/system_stm32f4xx.c to match your needs.

// ----------------------------------------------------------------------------

// Forward declarations.

void
__initialize_hardware(void);

void
configure_system_clock(void);

// ----------------------------------------------------------------------------

// This is the application hardware initialisation routine,
// redefined to add more inits.
//
// Called early from _start(), right after data & bss init, before
// constructors.
//
// After Reset the Cortex-M processor is in Thread mode,
// priority is Privileged, and the Stack is set to Main.

void
__initialize_hardware(void)
{
  // Call the CSMSIS system initialisation routine.
  SystemInit();

#if defined (__VFP_FP__) && !defined (__SOFTFP__)

  // Enable the Cortex-M4 FPU only when -mfloat-abi=hard.
  // Code taken from Section 7.1, Cortex-M4 TRM (DDI0439C)

  // Set bits 20-23 to enable CP10 and CP11 coprocessor
  SCB->CPACR |= (0xF << 20);

#endif // (__VFP_FP__) && !(__SOFTFP__)

  // Initialise the HAL Library; it must be the first
  // instruction to be executed in the main program.
  HAL_Init();

  // Enable HSE Oscillator and activate PLL with HSE as source
  configure_system_clock();
}

// ----------------------------------------------------------------------------

/**
 * @brief  System Clock Configuration
 *         The system Clock is configured as follow :
 *            System Clock source            = PLL (HSE)
 *            SYSCLK(Hz)                     = 168000000
 *            HCLK(Hz)                       = 168000000
 *            AHB Prescaler                  = 1
 *            APB1 Prescaler                 = 4
 *            APB2 Prescaler                 = 2
 *            HSE Frequency(Hz)              = HSE_VALUE
 *            PLL_M                          = (HSE_VALUE/1000000u)
 *            PLL_N                          = 336
 *            PLL_P                          = 2
 *            PLL_Q                          = 7
 *            VDD(V)                         = 3.3
 *            Main regulator output voltage  = Scale1 mode
 *            Flash Latency(WS)              = 5
 * @param  None
 * @retval None
 */
void
configure_system_clock(void)
{
  RCC_ClkInitTypeDef RCC_ClkInitStruct;
  RCC_OscInitTypeDef RCC_OscInitStruct;

  // Enable Power Control clock
  __PWR_CLK_ENABLE();

  // The voltage scaling allows optimizing the power consumption when the
  // device is clocked below the maximum system frequency, to update the
  // voltage scaling value regarding system frequency refer to product
  // datasheet.
  __HAL_PWR_VOLTAGESCALING_CONFIG(PWR_REGULATOR_VOLTAGE_SCALE1);

  // Enable HSE Oscillator and activate PLL with HSE as source
  RCC_OscInitStruct.OscillatorType = RCC_OSCILLATORTYPE_HSE;
  RCC_OscInitStruct.HSEState = RCC_HSE_ON;
  RCC_OscInitStruct.PLL.PLLState = RCC_PLL_ON;
  RCC_OscInitStruct.PLL.PLLSource = RCC_PLLSOURCE_HSE;

  // This assumes the HSE_VALUE is a multiple of 1MHz. If this is not
  // your case, you have to recompute these PLL constants.
  RCC_OscInitStruct.PLL.PLLM = (HSE_VALUE/1000000u);
  RCC_OscInitStruct.PLL.PLLN = 336;
  RCC_OscInitStruct.PLL.PLLP = RCC_PLLP_DIV2;
  RCC_OscInitStruct.PLL.PLLQ = 7;
  HAL_RCC_OscConfig(&RCC_OscInitStruct);

  // Select PLL as system clock source and configure the HCLK, PCLK1 and PCLK2
  // clocks dividers
  RCC_ClkInitStruct.ClockType = (RCC_CLOCKTYPE_SYSCLK | RCC_CLOCKTYPE_HCLK
      | RCC_CLOCKTYPE_PCLK1 | RCC_CLOCKTYPE_PCLK2);
  RCC_ClkInitStruct.SYSCLKSource = RCC_SYSCLKSOURCE_PLLCLK;
  RCC_ClkInitStruct.AHBCLKDivider = RCC_SYSCLK_DIV1;
  RCC_ClkInitStruct.APB1CLKDivider = RCC_HCLK_DIV4;
  RCC_ClkInitStruct.APB2CLKDivider = RCC_HCLK_DIV2;
  HAL_RCC_ClockConfig(&RCC_ClkInitStruct, FLASH_LATENCY_5);
}

// ----------------------------------------------------------------------------

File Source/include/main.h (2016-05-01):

#pragma once

//#define PSDR1 1
#define PSDR2 2

//#define PSDR_BOARD PSDR2

#ifdef PSDR1
#define STM32F415xx
#define HSE_VALUE=8000000 //did I do this right? Both of these were defined in the progect settings before in the several preprocessors

//#include "stm32f415xx.h"
#endif

#ifdef PSDR2
//#define HSE_VALUE 24000000

#include "stm32f429xx.h"
#endif

#include "stm32f4xx.h"
#include "stm32f4xx_hal_conf.h"
//#include "core_cmInstr.h"
#include <stdio.h>
#include "stddef.h"
#include "diag/Trace.h"
#include "hal.h"
#include "adc.h"
#include "dds.h"
#include "Timer.h"
#include "BlinkLed.h"

//#include "stm32f4xx_hal_rcc.h"
#include "stm32f4xx_hal_gpio.h"
#include "Adafruit_GFX.h"
#include "Adafruit_ILI9340.h"
#include "stm32f4xx_hal.h"
//#include "stm32f4xx_hal.h"
#include "stm32f4xx_hal_def.h"
#include "string.h"
#include "math.h"
#include "arm_math.h"
//#include "stm32f4xx_hal_rtc.h"
//#include "stm32f4xx_hal_adc.h"
#include "stm32f4xx_it.h"
#include "stm32f4xx_hal_tim.h"
#include "stm32f4xx_hal_cortex.h"
#include "misc.h"
#include "stm32f4xx_hal_dac.h"
//#include "stm32f4xx_hal_i2c.h"
#include "images.h"
#include "stm32f4xx_hal_dma.h"

//#include "stm32f4xx_hal_def.h"
#include "stm32f4xx_hal_uart.h"
#include "stm32f4xx_hal_usart.h"
#include "i2c.h"


TIM_HandleTypeDef    TimHandle;
TIM_HandleTypeDef    TimHandle4;

#define MASKRED    0b1111100000000000
#define MASKGREEN  0b0000011111100000
#define MASKBLUE   0b0000000000011111
#define MASKYELLOW 0b1111111111100000
#define MASKTEAL   0b0000011111111111
#define MASKWHITE  0b1111111111111111
#define MASKBLACK  0b0000000000000000

/* Definition for SPIx's DMA */
#define SPIx_TX_DMA_CHANNEL              DMA_CHANNEL_3
#define SPIx_TX_DMA_STREAM               DMA2_Stream5
#define SPIx_RX_DMA_CHANNEL              DMA_CHANNEL_3
#define SPIx_RX_DMA_STREAM               DMA2_Stream2

/* Definition for SPIx's NVIC */
#define SPIx_DMA_TX_IRQn                 DMA2_Stream3_IRQn
#define SPIx_DMA_RX_IRQn                 DMA2_Stream0_IRQn
#define SPIx_DMA_TX_IRQHandler           DMA2_Stream3_IRQHandler
#define SPIx_DMA_RX_IRQHandler           DMA2_Stream0_IRQHandler

SPI_HandleTypeDef SpiHandle;
UART_HandleTypeDef UartHandle;

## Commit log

2014-06-22 Initial commit to GitHub.
    Includes the Source (as an Eclipse project) and the Hardware files (including schematic, layout, gerbers, and bill of materials.)
    The firmware is extremely incomplete. At this point the DDS chips work (with controlled phase relationship), the LCD (with fast-ish SPI, scrolling, and GFX, modified from Adafruit's library), the encoder knob, and LED work.
    The ADC is capturing, but not in a usable way, but it's enough to feed the DSP code and see a nice pretty waterfall. Timers, interrupts, and DACs are not working yet.
    [PSDR BOM.xlsx, PSDR.sch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]
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2014-07-07 Haven't committed in a while :o . Currently waterfall is disabled while I work on audio processing. I am capturing, FFT, filter, IFFT, and output. It seems to be working partly. I don't think I am do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
    Also, starting to implement the menu system. Oh, and fixed some indentation, so it looks like there was more changed to main() than there really was....
    [adc.c, hal.c, main.c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]
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2014-07-08 Added a crude Automatic Gain Control (AGC) that's happening on the audio output side. I want to add one for the RF side as well, but I'll need to change the hardware to do it. Also fixed some weirdne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
    [main.c]
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2014-07-15 The beginnings of AM demodulation. I think it works, but it doesn't sound good at all (then again, SSB leaves something to be desired as well.) Graphical display of filter (nice!) Doesn't crash if yo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
    [main.c]
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2014-07-23 Huge improvement in display. It was basically a bug that made it so hard to read. Playing with an IF shift feature, and filtering and stuff. I think the overlap-discard is not quite right yet....
    [main.c]
2014-07-23 Added some color bitmaps and some code to draw them (way prettier graphics, here we come!), fixed a minor bug in the mode selection menu.
    [main.c, main.h]
2014-07-27 Starting to (slowly) make changes to the schematic for the next hardware version.
    Making/made a lot of changes to the graphics and some to the menu system. Want to do a commit before I change too much more, incase I screw things up, you see. Graphics look much better!
    [PSDR.sch]
2014-07-27 Further improvements to the menu system. Now, rather than a red underline, the item itself turns red. Logic for updating runtime settings and updating the display is improved. Main() is streamlined. 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
    Does seem a little slow sometimes. Not sure why it would be (not more than it was before, anyway) Also, if you move through menu items too fast, some of them stay highlighted incorrectly.
    [main.c]
2014-08-02 Added basic volume control (not sure why I didn't do that a long time ago!) also a HackADayPrize logo, can't hurt, right? A few other small things.
    [PSDR BOM.xlsx, PSDR.sch, PSDR1_BOM.xlsx]
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2014-09-13 Backing up. PSDR2 has reached the point where it could be produced and would work; all lines are routed and there are no clearance issues. I am cleaning up the layout now, need to do some planes, sil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
    [PSDR.sch]
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2014-10-01 Just backing up. PSDR2 is receiving well, image rejection is good. Gain pot settings work. Audio out works (to earphones only, the speaker fails pretty badly, not sure why, but that's hardware anyway)
    [PSDR.sch, PSDR2.SLDASM, PSDR2_BOM.xlsx]
2014-10-06 Initial transmit support. Internal microphone working. Capacitive touch sensors working. Currently touch TOUCH1 to transmit, waterfall changes color and shows the filtered output that should be trans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
    [PSDR.sch]
2014-10-07 Big improvements to audio! I was doing overlap-add wrong. There are still issues, but it's much better. Also, changing modes between LSB/USB/AM works now (though the menu doesn't show USB correctly, 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
    [PSDR.sch, Stepping through filter coeficient population.xlsx]
2014-10-15 Pretty big improvements to bitmap drawing code, and waterfall display code. Also a hack to deal with the red-things-stay-red bug (it's not ideal, it just blocks the encoder tick() if the display is d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
    [PSDR.sch, Stepping through filter coeficient population.xlsx]
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2015-12-29 Got trace statements though the debugger! Cool! And it was so minor. Also, fixed a weird issue with missing linker files (at least on this computer......)
    [DevBoardKeyChain.sch, PSDR.sch, Si5338 Test Board_00AF.sch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]
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2016-02-25 More progress. We're at around 200 unroutes and just about all the components have been placed. I am using pin-swapping to make the routing easier and cleaner.
    [PSDR.sch]
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2016-03-20 Cleaning up the routing, a lot! At this point the goal is to increase performance, reliability, and manufacturability, but there is also an element of making it look good and being a perfectionist. I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
    [PSDR.sch]
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2016-04-21 A heroic effort to push things forward. Now working includes the I2C interface and the code to talk to and start up the frequency synth. Flip flops are on, frequencies are being divided. No luck on a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
    [PSDR.sch]
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2016-04-24 Progress on copying stuff over for the F7. I am making quite a mess, I think I sure hope I can reverse this all if I need to!!!
    [BlinkLed.h, _initialize_hardware.c]
2016-04-24 Progress, I think. The thing compiles and builds something, but it's only 1K and won't run. Trying to figure out what I am doing wrong. :/
    [BlinkLed.h, TinyGPS.c, _initialize_hardware.c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]
2016-05-01 Saving current progress. Still some weird issues. Having trouble with I2C (again! It was such a pain to get working on the F4) and also something with the ADC I think.... I suppose it could be assemb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
    [i2c.c, main.c, main.h]
2016-05-01 Didn't actually change much. This is testing with the new diode ring mixer. Seems to be working! Thank goodness!! Reception in 2m seems very weak... might need a preamp or something?
2016-05-01 Oops, didn't actually commit the files.
    [i2c.c, main.c]
2016-05-07 Control of the new frequency synth is pretty much working (not completely optimized, probably isn't taking full advantage of its resolution, and doesn't cover its full range yet) the PSDR can now tun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
    [PSDR.sch]
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2016-05-11 This fixes (I think) the ADC issue. Or rather, interprets the already correct values correctly. Anyway. I think we are good, though more testing would be nice. I compared the F4 display performance t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
    So with this, I think the F7 is now doing everythin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
    [PSDR.sch]
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2016-05-29 Almost done with PCB 2.6v. I decided to change the reference designators so it's easier to find components. But PADS randomly swapped a bunch of parts. I wasted HOURS fixing it! :( Anyway, it's almos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
    [PSDR.sch]
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2016-11-01 Update to Face Cover part. Also includes a fixture I designed to secure them while being milled.
    [BottomFixture.SLDPRT, Face Cover4.SLDPRT, FaceCoverFixture.SLDASM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]
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2016-11-08 Fixes very basic transmit support. Adds assembly instructions. Cleans up the Solid Model a little and moves older items to an Archive folder (basically to make sure they are okay to delete, since Git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
    [2.5mm_Allen_Wrench.SLDPRT, 2mm_Allen_Wrench.SLDPRT, 7x3x3 Bearing.SLDPRT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]
2016-12-31 More compiler warnings fixes
    [adc.c, adc.h, i2c.c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]
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2026-11-02 docs(bom): record why C307/C320/R72/R79 are DNP, in the BOM's own notes column
    Answers the remaining half of issue #14 ("were they removed, does the BOM need
    updating?"). From the 2.6.1 netlist extracted out of the board: none of the four
    is a series element, so none needs a 0 ohm jumper. C307 = U314(AD8302).8 to GND
    and C320 = GND to U314.14 are shunts; R72 and R79 bridge the mixer LO pairs
    (MIXER_LO2N/2P on L41.1/L41.6, MIXER_LO1N/1P on L81.1/L81.6), whose nets already
    reach the winding -- fitting 0 ohm there would short the pair. All four still
    have footprints, pads and silkscreen designators on the board.
    OPEN and DNS were written in the Value column, which is why the rows read like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
2026-11-02 fix(bom): record the manufacturer part numbers behind issue #13's two lines
    Both identities are recoverable from this repository, so they are written down
    before the DigiKey SKUs become the only thing left to search.
    U304 / 599-1068-1-ND: the row's own hyperlink target is
    .../digikey.com/product-detail/en/rfmd/SXB-2089Z/599-1068-1-ND/937042
    and the same row's note says "Name mismatch is okay, The Digikey part # is the
    correct part"; the 2.5 sheet carries the matching note "*Not the part listed in
    Type" on the equivalent row (U19). So the real device is RFMD SXB-2089Z and the
    Type / decal name MMIC-AMP_HMC482ST is a stale label.
    U16/U24/U30 / 1465-1374-1-ND: no hyperlink exists on this row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
2026-11-03 docs: hardware + firmware review (RX sensitivity root-cause)
    Key finding: in receive, signalPath() powers off and bypasses the HMC482
    RF gain block, recieve_with_filter is an empty stub, and the amp-relay
    polarity is unverified ("I think!") - so RX runs with no active gain stage.
    That (plus the lossy mixer-QSD) is the likely deafness, and most of it is
    firmware-fixable. Also documents the HMC1023 VDDBG board bug, the missing
    power-up UVLO, and that the from-source build bus-faults at boot.
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2026-11-03 usb: vendor ST USB Device Library (Core+CDC), enable PCD, fix 48MHz clock
    Groundwork for a USB CDC serial console:
    - Fix the USB clock: PLLQ 8 -> 9 (432MHz VCO / 9 = 48MHz; 8 gave 54MHz, so
    USB never worked - which is why there was no USB code).
    - Enable HAL_PCD_MODULE_ENABLED (the PCD/LL_USB HAL were already present).
    - Vendor the USB-Device Library Core + CDC class into Source/usb/ (from
    STMicroelectronics/stm32_mw_usb_device), plus the conf/desc/cdc_if
    templates (_ref_*) to adapt into glue. Not yet compiled/wired.
2026-11-03 usb: working CDC serial console (enumerates as VCP, live command parser)
    Wrote the glue on top of the vendored USB-Device library: usbd_conf (PCD
    HAL LL driver + MspInit + callbacks + OTG_FS_IRQHandler), usbd_desc (CDC
    VCP descriptors, VID 0483/PID 5740), usbd_cdc_if, and usb_serial (init +
    printf + command parser). Wired into the main loop and build.
    Verified end to end: the board enumerates as a COM port and answers
    commands over a terminal -- s (status: S-meter + HMC1023 regs), f1/f0
    (filter in/bypass), v<gain> (volume). This replaces the SWD global-poke
    workflow for bench bring-up.
    (Old CMSIS lacked __PACKED/__ALIGN_*; defined them in usbd_conf.h.)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
2026-11-03 fw: serial console - live HMC1023 reg r/w, RF-amp control, S-meter stream
    - s now resets the peak (real per-read S-meter); m1/m0 stream it (~4Hz).
    - r<reg> <hex> / R<reg>: write/read HMC1023 registers live (sweep corner,
    gain, etc. from a terminal via the hmc1023_write/read wrappers).
    - a1/a0: power + insert the HMC482 RF gain block in RX (the receive-with-amp
    deafness experiment); A1/A0 flips the unverified AMP_SWITCH sense.
    - Main loop now forces the 5V boost on (signalPath turned it off in RX,
    which would unpower both the LPF and the amp).
    Mechanism verified over USB; quantifying the sensitivity gain needs a signal
    source (antenna / WaveTek gen).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
2026-11-03 fix: amp-switch bypass polarity was backwards (blocked RX)
    The main-loop amp control drove AMP_SWITCH to the INSERTED position when
    the amp was off (A=1/B=0), routing the receive signal into the powered-down
    HMC482 instead of around it -- killing RX regardless of signal level. Now
    amp-off matches signalPaths stock bypass (A=0/B=1); amp-on inserts it.
    Also default g_filter_in=0 so the board boots in pure stock receive.
2026-11-03 fw: serial control of the rest of the RX path (TRX, TX-RF, imp-bridge)
    Force T/R switch, TX/antenna RF switch, and impedance-bridge switch to known
    RX states every loop (no longer depending on signalPath timing), and expose
    t/x/b commands to flip each live while watching the waterfall. Status line
    now shows trx/txrf/imp.
2026-11-03 fix: dont force the 5V boost on in RX (switcher noise was deafening it)
    Stock RX turns FIVE_VOLT_REGULATOR_ENABLE off on purpose -- the ADP1613
    boost switcher desensitizes the HF front end. My main loop forced it on
    every iteration, which killed receive (original fw hears a -40 dBm tone at
    S9+30; my build heard nothing). Now the boost is enabled only when the LPF
    or amp actually needs it (g_filter_in || g_amp_in); plain bypass RX leaves
    it off, matching stock.
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2026-11-03 fw: HMC1023 live bring-up tooling over the USB console
    - hmc1023_io_init(): configure the bit-bang SPI CS (PB12) and MISO (PB14)
    pins at startup, independent of the (disabled) probe. Fixes live console
    SPI reads returning 0xFFFFFF -- those pins were only set up inside
    hmc1023_probe(), which is commented out. Now R0 reads 0x114080 and
    reg writes verify by read-back.
    - Filter mux channel as a console setting: g_filt_ch + "M0".."M3" drive the
    shared select lines (S1<<1|S0) of both muxes U211/U298. ch1=bypass (stock),
    ch0=external filter (DNF), ch2 & ch3 = through the HMC1023 in opposite
    directions (ch2 = RX direction per netlist + bench test, ch3 = TX/forward).
    - Real S-meter ov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
2026-11-03 fw: fix dead HMC1023 RX path -- enable the I/Q channels (reg1 bits 2,3)
    The config wrote reg1=0x12, which clears filter_I_enable (bit 2) and
    filter_Q_enable (bit 3). Per the datasheet those default high and gate the
    chip's whole analog path (gain stage + filter + driver); 0x12 held both
    channels in reset, so the chip passed no signal -- which is why it always
    looked dead. Fix to reg1=0x1C, and add hmc1023_config_rx() + console 'H' to
    apply the proven RX config (channels on, +10 dB gain, 20 MHz corner, filter
    active) and read it back.
    Bench (detector bar): through-chip + gain reads ~89 in-band vs ~75 for the
    hardware-bypass path, and ~0 swing with the old reg1=0x12. Corrects the
    overnight fl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
2026-11-03 docs: correct HMC1023 gain (20 dB cascade) + add RX-chain / sensitivity trace
    Michael pointed out the two channels are wired as a cascade (I-channel out ->
    C293/C294 -> Q-channel in), so it's ~20 dB, not the 10 dB I'd written. Netlist
    confirms. Added the full RX chain from PSDR.asc: RF_ANT -> MASWSS0129 switches ->
    ADE-2ASK diode-ring mixers (quadrature, SY10EP52 LO) -> MCP6N11 in-amps (MAX5388
    gain pot) -> 74CBTLV3253 muxes -> HMC1023 -> STM32F746 ADC. Key point: the
    HMC1023 is the last baseband stage before the ADC, so its gain does not set the
    noise figure; sensitivity is set by the lossy diode-ring mixer (no LNA ahead) and
    the noisy MCP6N11 first baseband amp. Also: LPF_5V is switched fr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
2026-11-03 docs: correct RF architecture (HMC1023 is PRE-mixer) + add TX chain & VNA
    My first RX trace was wrong: the 74CBTLV3253 muxes and the HMC1023 are in the RF
    path AHEAD of the mixers (between antenna balun L39 and mixer balun L82), not in
    the baseband. FILTER_IF->L82->mixer RF ports and FILTER_RF->L39->antenna confirm
    it. So the HMC1023 is an active RF preamp + roofing LPF ahead of the lossy mixer,
    and its ~20 dB CAN improve noise figure / sensitivity -- opposite of what the doc
    said -- modulo the ADP1613-boost noise tradeoff. The MCP6N11 in-amp + MAX5388 gain
    pot are the post-mixer baseband gain (no NF benefit); clean-CW gain-pot sweep is
    a small monotonic lever as expected.
    Added the full TX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
2026-11-03 PSDR: composite USB CDC console + UAC1 microphone
    Present the device as a composite (IAD) CDC ACM console plus a USB Audio
    Class 1.0 microphone, so demod audio can stream to the PC (WSJT-X/fldigi)
    alongside the serial console. New hand-rolled single USBD class
    (usbd_cdc_audio.c/.h) serves both functions; usb_serial.c registers it in
    place of plain USBD_CDC; usbd_desc.c advertises the IAD composite device
    class; usbd_conf.c enables SOF (paces the iso IN) and rebalances the FIFOs.
    Key fix: USBD_MAX_NUM_INTERFACES was 1, so the USB-device core STALLed every
    standard/class interface request whose wIndex exceeded 1 (usbd_ctlreq.c gate).
    Once the audio streaming interface (iface 3) had a second a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
2026-11-03 PSDR: real-time iso-IN pacing for the UAC microphone
    Chain the next audio frame off the DataIn completion (one clean packet per
    USB frame) instead of re-arming unconditionally every SOF; SOF now only
    re-kicks when the chain has stalled. Handle IsoINIncomplete (IISOIXFR) by
    flushing the iso IN endpoint so a frame the host misses doesn't leave stale
    data backing up the TX FIFO.
    Before: the FIFO backed up and the host captured audio at ~0.02x real-time.
    After: host capture runs at real-time 48 kHz and the SWD counters show armed
    transfers ~= completed (iso_arm 6019 / iso_datain 6016 over a 6 s capture).
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2026-11-03 PSDR panel: speaker playback, demod mode and HPF/LPF filter controls
    - "Listen on PC speakers": plays the PSDR USB-audio mic out the default output
    via ffplay (auto-locates ffplay/ffmpeg and the dshow device; graceful hint if
    ffmpeg is missing). Audio is a separate USB function, so it runs alongside the
    serial console.
    - Mode radios (LSB/USB/AM -> D) and HPF/LPF sliders (-> K<lo> <hi>), with an
    approximate-Hz readout; the panel initialises them from, and reflects, the new
    mode/flo/fhi status fields.
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2026-11-03 PSDR: fix growing USB-audio latency - send exactly one frame per SOF
    The iso IN consumer drained "up to 32" samples per frame and padded underruns,
    so it averaged more than the 24 samples/frame the host plays at - a few percent
    fast, which piled up in the player as tens of seconds of latency over minutes.
    Send exactly AUDIO_SAMPLES_PER_FRAME every time so the device output rate equals
    the host rate; the ring absorbs jitter (rare underrun pads silence, rare overrun
    drops), so latency stays bounded instead of growing. Panel: run ffplay with
    nobuffer/low_delay so its own baseline latency is small too.
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2026-11-03 PSDR panel: target the demod device for Listen; add I/Q level slider
    With two capture devices now, the Listen button explicitly picks "PSDR Demod"
    (listening to raw I/Q would just be noise), and a new I/Q level slider sends the
    'Q' gain command for use with HDSDR/Quisk on the "PSDR I/Q" device.
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2026-11-04 PSDR: DMA-paced ADC with 15x oversample-average capture
    Replaces the free-running ADCs + polled adcGetConversion() (read from the
    48 kHz capture ISR) with a hardware-paced, oversampled, DMA-fed path:
    - TIM6 TRGO fires ADC1(mic)/ADC2(I)/ADC3(Q) SIMULTANEOUSLY at 720 kHz
    (= 48000*15, exact: 108 MHz/150). Simultaneous conversion removes the
    inter-ADC timing skew that free-running independent ADCs added to the I/Q
    quadrature error.
    - Each ADC circular-DMAs into a 2*15 buffer (DMA2 Str0/Str2/Str1). The
    half/full-complete ISR (exactly 48 kHz) averages the 15 samples that just
    landed -> a sinc anti-alias low-pass + ~sqrt(15) (~12 dB) noise reduction --
    writes the result into uhADCxConv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
2026-11-04 PSDR: I/Q imbalance correction (manual works; adaptive experimental)
    Adds a Gram-Schmidt I/Q correction on the USB I/Q feed, behind console 'B':
    0=off, 1=adaptive, 2=manual. A DC blocker runs first in both correcting modes
    (removes residual DC + the LO-leakage center spike). Console 'Y<x1000>' sets
    the phase/correlation coeff c1, 'U<x1000>' sets the amplitude coeff c2; status
    reports mode + c1/c2. Panel gets off/auto/man buttons and phase/amplitude
    sliders (a slider switches to manual).
    Bench result (Wavetek tone, HDSDR CLOSED so the capture is clean):
    - native (off) : 41-43 dB image rejection
    - MANUAL, computed-ideal c1/c2 : ~50 dB (c1~0.012, c2~1.016) -- WORKS
    - ADAPTIVE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
2026-11-04 PSDR panel: big frequency readout + tuner, signal-flow diagram, UX polish
    Control-panel usability pass (tools/psdr_panel.py):
    - Big VFO readout with per-digit tuning: scroll or click (top=up, bottom=down)
    any digit to tune that decade; syncs live from the firmware's status (held
    ~1 s after a manual move so it doesn't fight the user). Old entry+Set kept.
    - Demod "Listen" no longer pops a console window: ffplay now launches with
    CREATE_NO_WINDOW and DEVNULL streams.
    - Diagram extended with the MCU/DSP stage row inside a "STM32F746 — DSP"
    enclosure: ADC→DMA 15x oversample/avg→FFT→channel filter→demod→USB audio,
    plus the I/Q-balance tap → USB I/Q (HDSDR). Filter/demod box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
2026-11-04 PSDR panel: move serial writes off the UI thread (fixes freeze)
    The redesigned digit tuner makes it easy to fire many writes quickly (scroll
    to tune). A write on the Tk main thread blocks if the device's USB CDC input
    isn't draining fast enough, which froze the whole window. Now:
    - write() just enqueues the command (non-blocking, drops under backpressure).
    - A dedicated writer thread does the blocking serial I/O, with write_timeout as
    a backstop so even it can't hang forever.
    The UI can no longer be blocked by serial I/O.
2026-11-04 PSDR panel: debounce tuner + pace writes (stop flooding the device)
    The digit tuner fired one F (Si5338 I2C reprogram) per scroll-tick; a fast
    scroll flooded the device's USB CDC faster than the USB ISR could drain it
    (the DMA capture ISR competes for CPU), overflowing the RX FIFO and wedging
    the OUT endpoint -> host "write timeout" forever (needed an MCU reset).
    - Tuner now debounces: the readout updates instantly but the F command is sent
    only ~120 ms after scrolling settles (one command per gesture).
    - Writer thread paces to >= 25 ms between commands, so no slider/scroll burst
    can flood the device. The device handles paced commands fine.
    (Firmware could also be hardened so a flood c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
2026-11-04 PSDR: console 'F' actually retunes the LO (was display-only)
    The F command set vfoAFrequency and printed it but never called setFreq(), so
    the on-screen frequency changed while the Si5338 LO stayed put -- tuning from
    the panel moved the display but not the actual receive frequency. The encoder
    path relies on `if(vfoAFrequency != vfoALastFreq) setFreq(...)`, but
    updateDisplay() syncs vfoALastFreq = vfoAFrequency every frame, so that check
    never fires for an F-command change. Fix: F now calls setFreq() directly, like
    a tune should. Verified the device stays responsive after F (setFreq doesn't
    hang the main loop).
2026-11-04 PSDR: working AM demod (envelope detection) + AM filter fix
    AM was broken: it masked BOTH sidebands but excluded the carrier (DC) when the
    HPF offset>0, took the magnitude PER FFT BLOCK (nonlinear -> corrupts the
    overlap-save reconstruction), and never removed the carrier DC. Rewrote it as a
    proper envelope detector:
    - Demod (USB tap): AM = |I + jQ| of the RAW I/Q (ADC2=I, ADC3=Q is a true
    quadrature pair; the FFT bank's re/im are not), with a ~6 Hz DC-block to
    remove the carrier level, then a ~3 kHz one-pole audio lowpass. SSB unchanged
    (real part of the FFT-filtered bank).
    - processStream: dropped the per-block magnitude for AM; the bank stays linear
    (complex) so SSB/overlap keep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
2026-11-04 PSDR: AM on the speaker, mistune-tolerant, audio HPF/LPF
    Builds on the AM envelope detector:
    - Per-channel I/Q DC blockers before |I+jQ| remove the direct-conversion LO
    self-mix offset. That offset was beating against an off-centre carrier and
    leaking the carrier into the audio, which is why AM needed precise tuning.
    Now the carrier can sit anywhere in the passband (like a superhet's envelope
    detector behind a wide IF) -> tuning no longer has to be exact. Verified:
    tuned 3.86 kHz off the carrier still recovers a clean ~1 kHz (carrier
    residuals 16 dB down).
    - AM audio is computed once per sample and routed to BOTH the speaker DAC (all
    three output banks) and the USB demod - AM n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
